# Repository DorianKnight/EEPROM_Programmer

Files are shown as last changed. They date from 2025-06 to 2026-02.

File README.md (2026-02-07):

# EEPROM_Programmer

## Project Overview
Custom Serializer Deserializer (SerDes) PCB designed to handle read/write operations to a parallel address EEPROM.
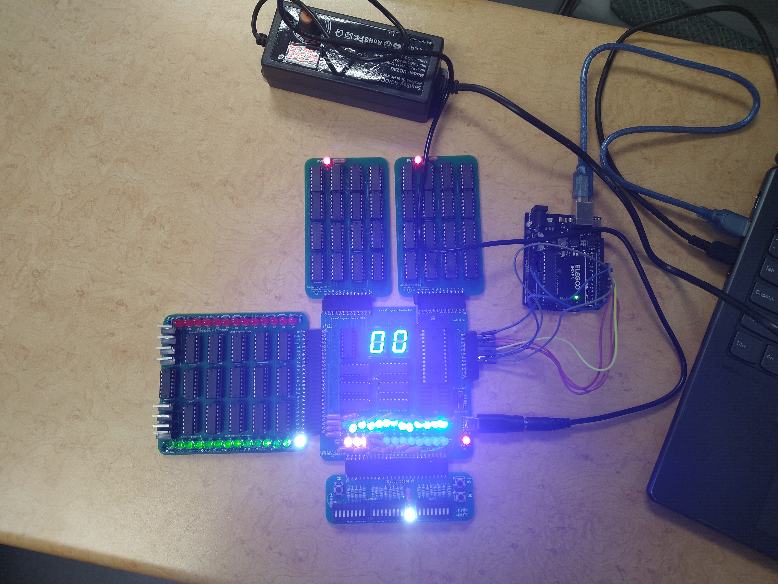
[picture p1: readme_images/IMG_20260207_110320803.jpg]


## High Level Architecture
Data from the host computer is transferred through serial communication to the Arduino. The Arduino writes the serial data into the SerDes which outputs the data in parallel to the EEPROM for storage.

To read information from the EEPROM, the Arduino loads the parallel data output into the SerDes and reconstructs the byte packet bit by bit. A high level functional block diagram explaining the system can be seen below.
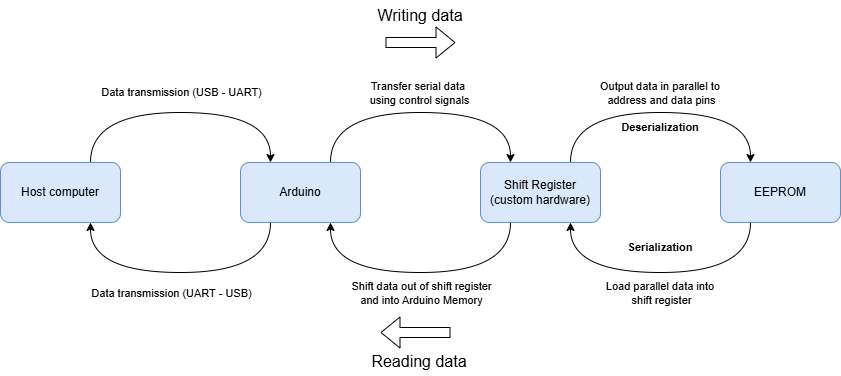
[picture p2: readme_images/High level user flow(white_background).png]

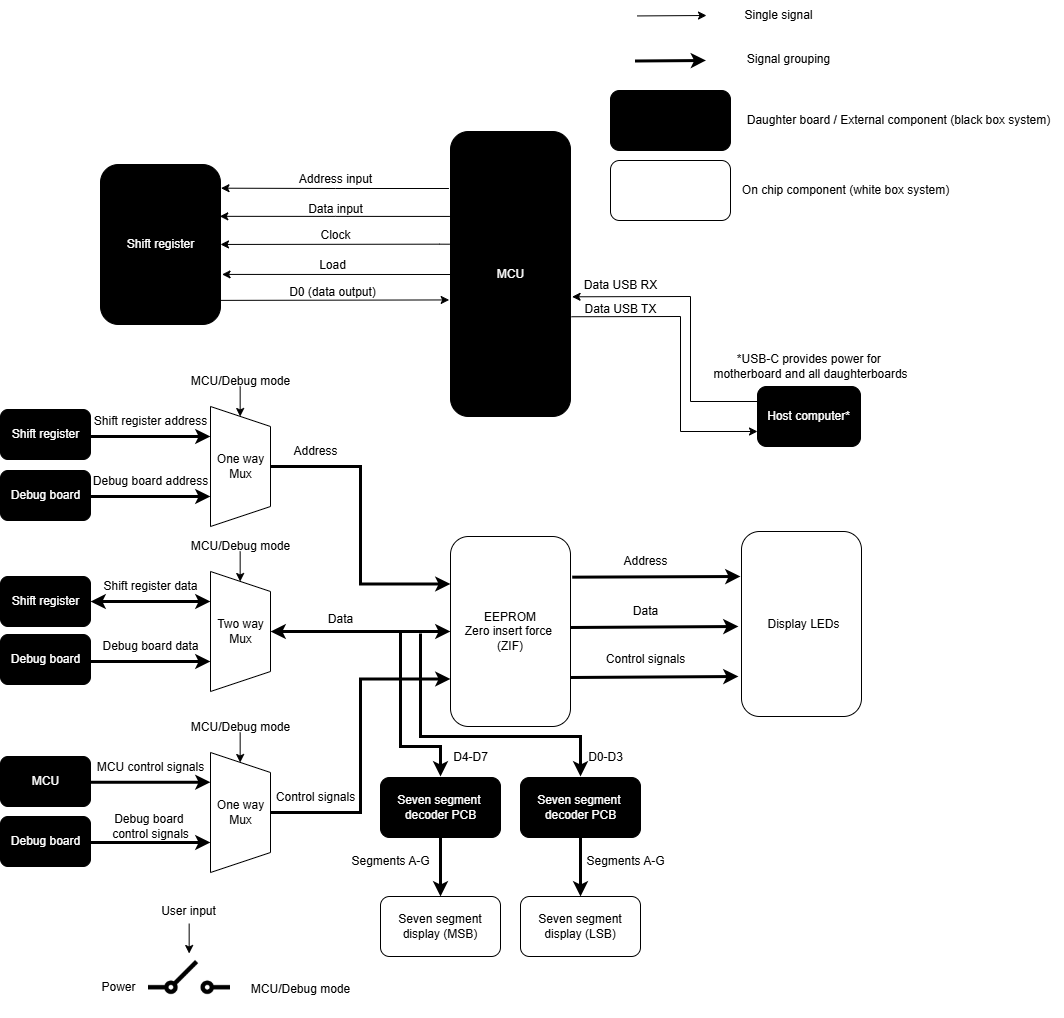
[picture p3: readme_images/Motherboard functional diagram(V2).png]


## SerDes
A custom shift register functions as a primitive SerDes. Going from serial to parallel, the custom hardware allows serial data to ripple into individual flip-flops where each flip-flop drives an individual output. These outputs then wire into the EEPROM’s address and data pins. The same hardware also functions to load in the parallel data output from the EEPROM and shift it out sequentially such that the Arduino can reconstruct the byte packet.
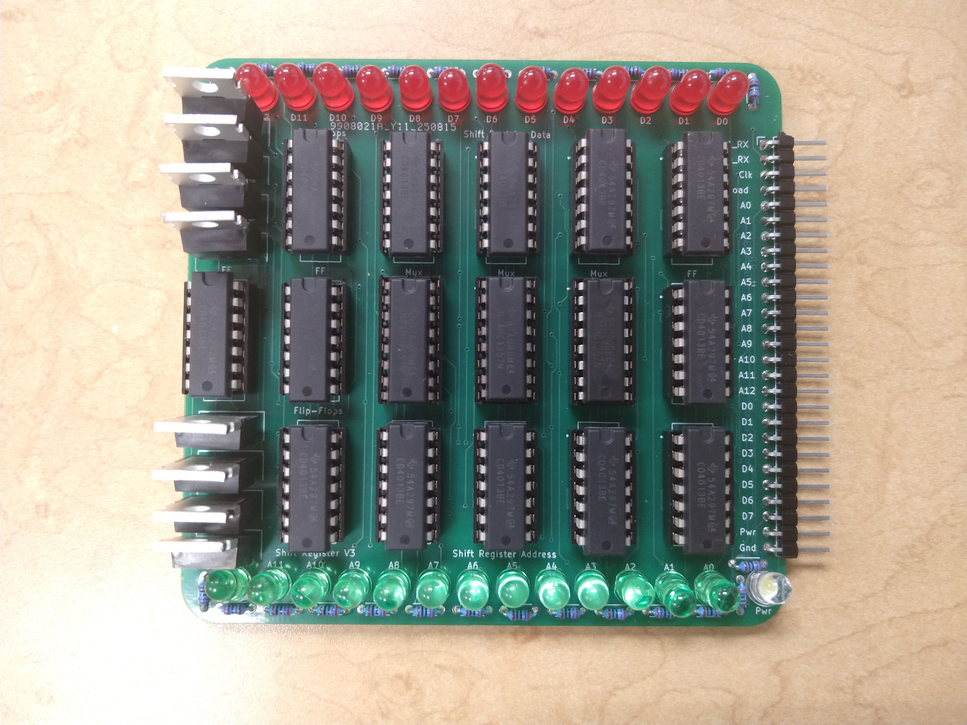
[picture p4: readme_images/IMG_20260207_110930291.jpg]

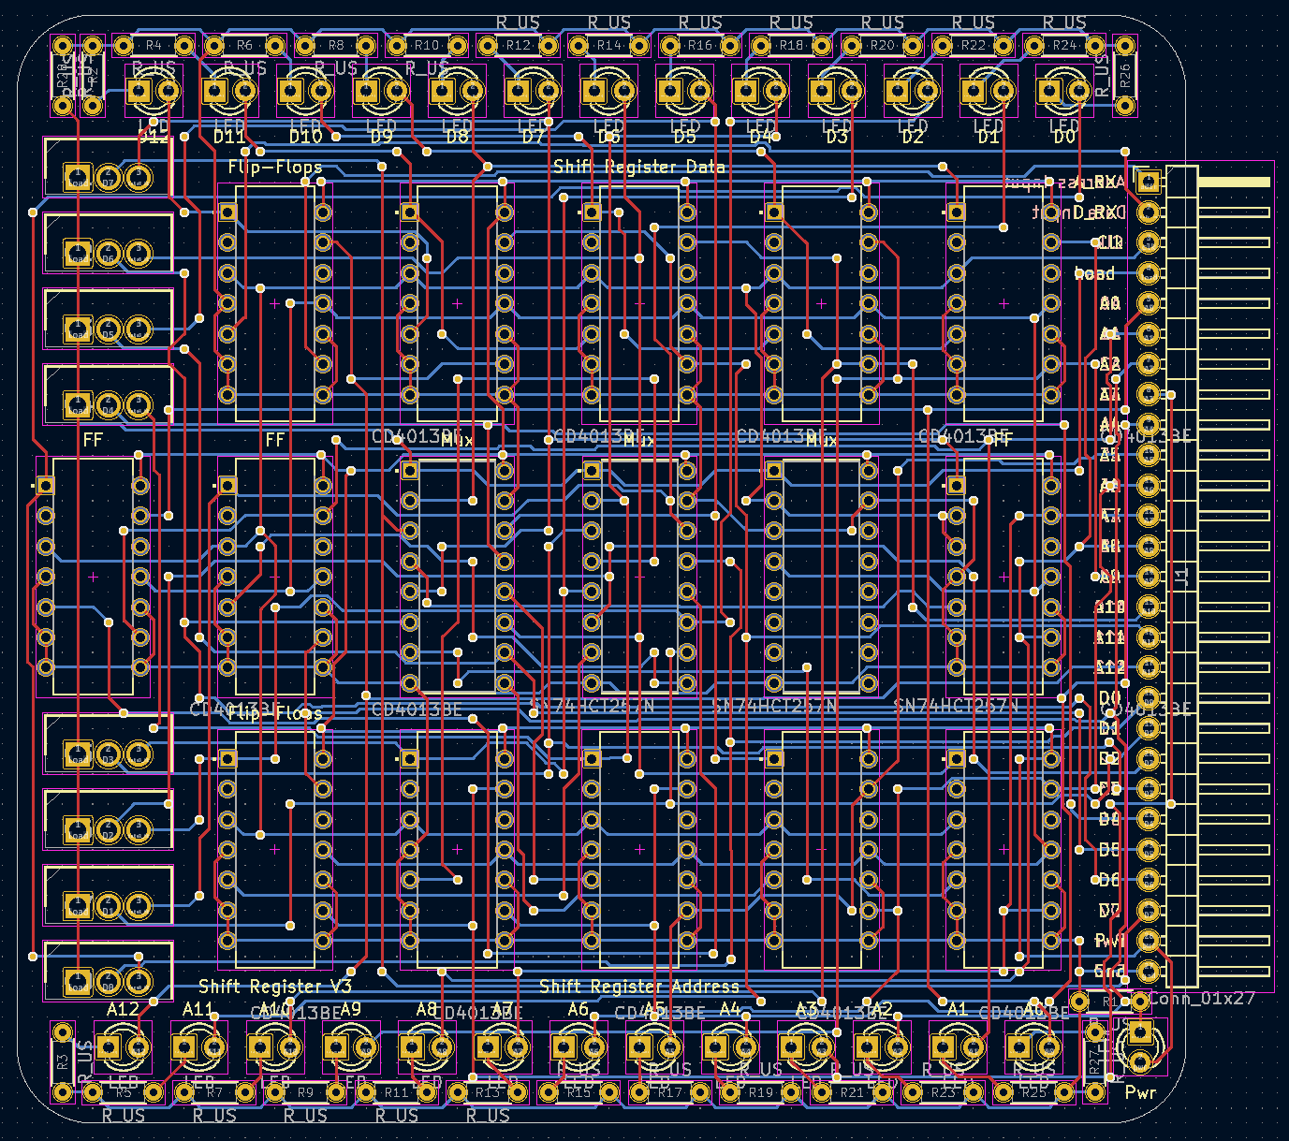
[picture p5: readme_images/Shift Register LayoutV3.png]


## Debugging
To facilitate debugging operations, a debug daughter board PCB was constructed that allows the technician to manually toggle all control signals made available to the Arduino MCU.
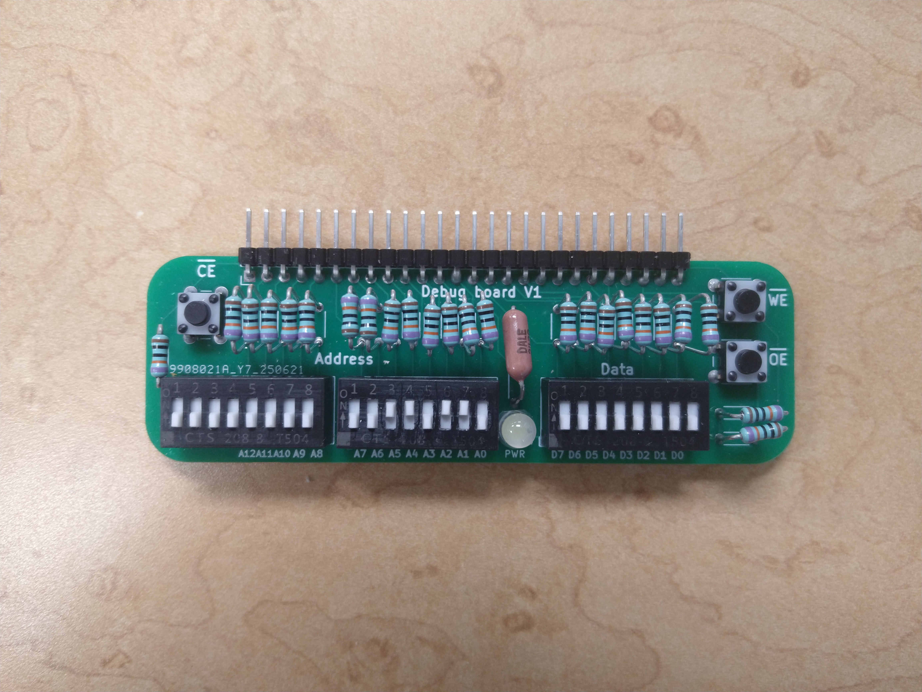
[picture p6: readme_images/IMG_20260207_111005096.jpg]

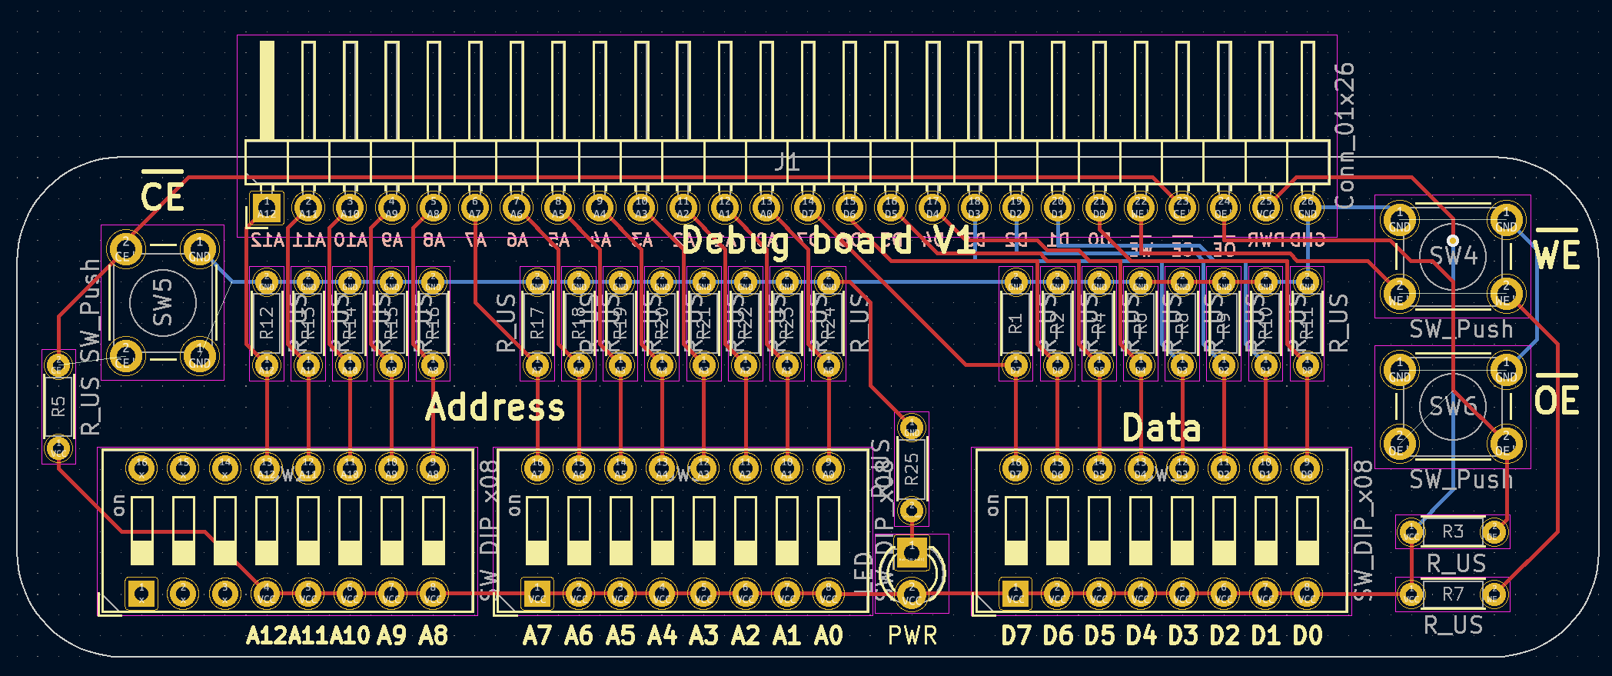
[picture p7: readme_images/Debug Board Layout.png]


## Motherboard Interface
The motherboard hosts a series of LEDs and seven-segment displays that serve to display the byte stored at a specific address. By changing the board to debug mode, the technician can select an address to read its binary and hexadecimal representation.
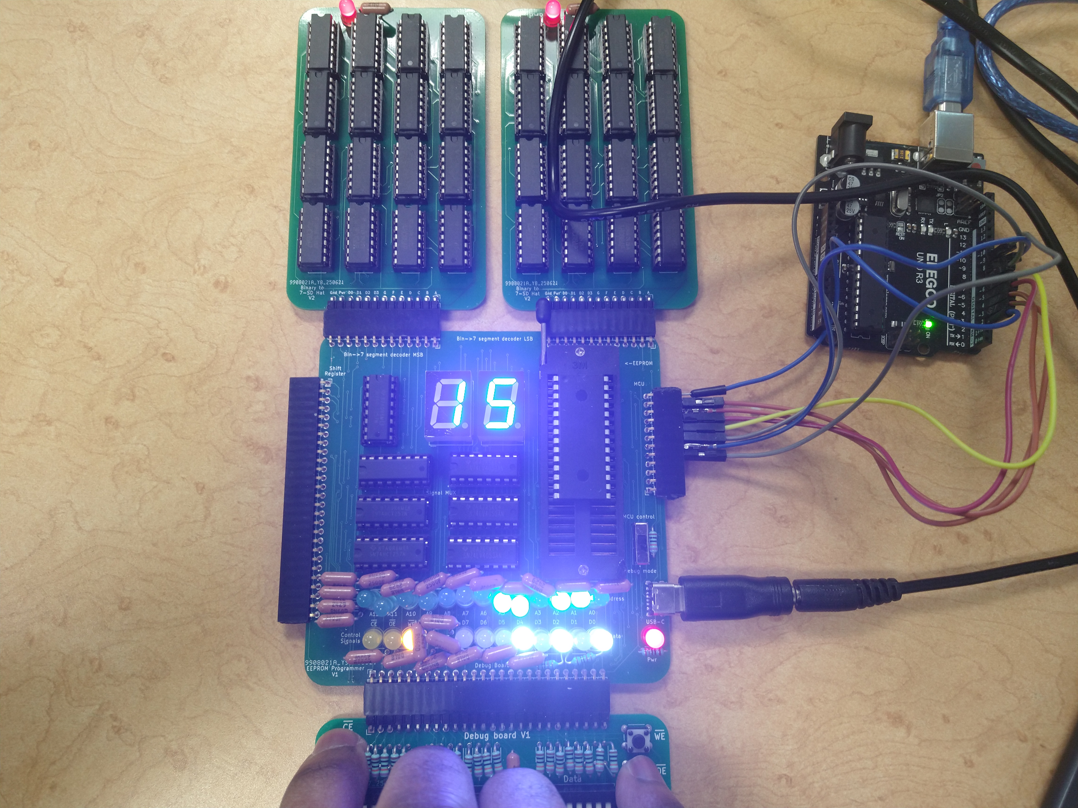
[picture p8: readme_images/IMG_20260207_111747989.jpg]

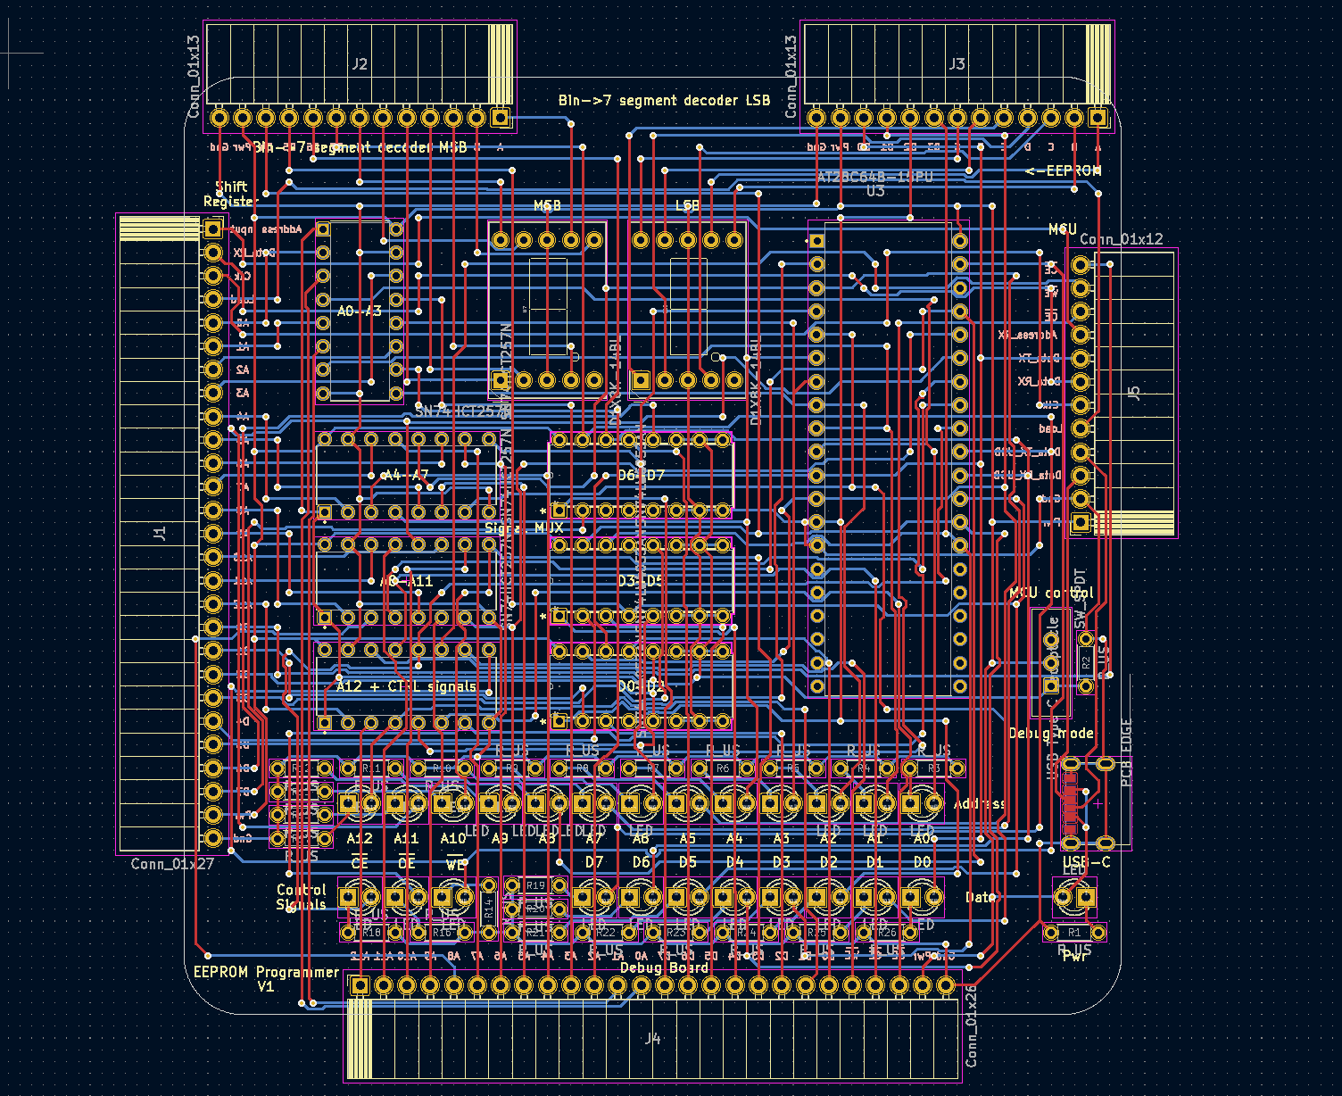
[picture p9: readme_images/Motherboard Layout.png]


## Custom Bin -> Hex 7-SD Driver 
Binary to hexadecimal conversion was accomplished through the design of custom digital combinational logic that uses a series of primitive logic gates to turn a four bit binary input into a seven pin output. The individual outputs turn on or off the individual segments on a seven segment display.
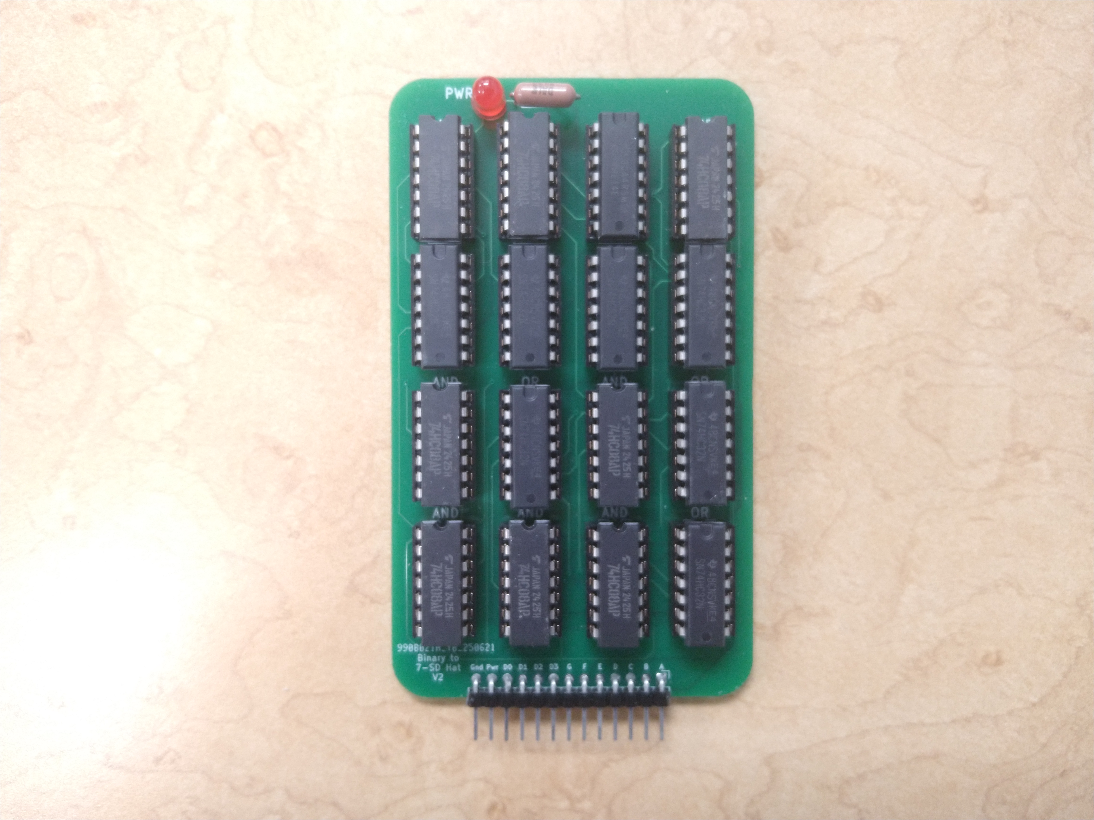
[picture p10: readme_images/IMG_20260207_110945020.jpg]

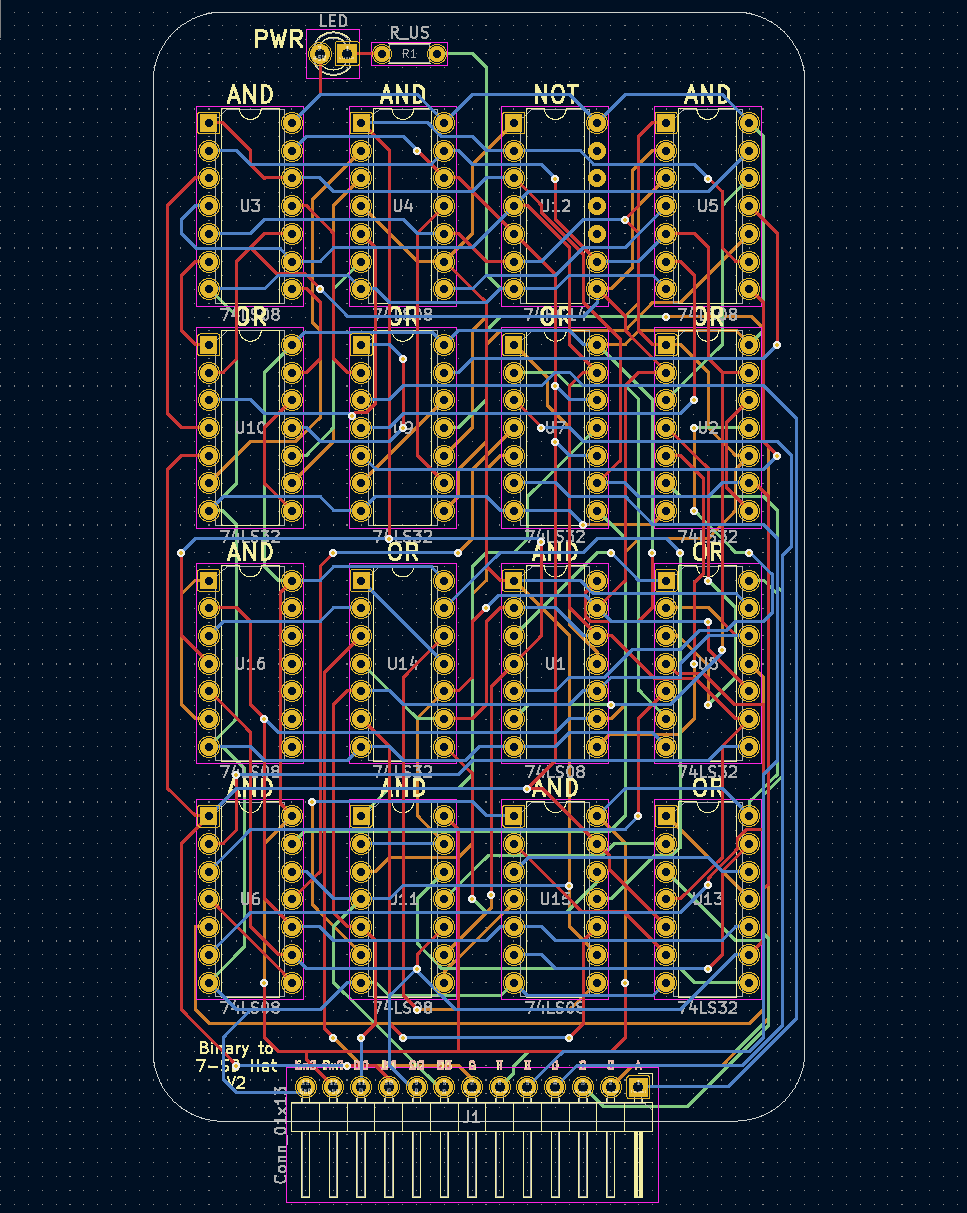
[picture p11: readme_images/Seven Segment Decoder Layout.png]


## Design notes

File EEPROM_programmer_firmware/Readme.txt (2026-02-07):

Arduino runs command_interpreter.ino which leverages EEPROM_Programmer_Utility.h and EEPROM_Programmer_Utility.cpp

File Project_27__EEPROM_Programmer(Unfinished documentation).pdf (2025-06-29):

# EEPROM Programmer

Dorian Knight

Created: June 27th 2025
Updated: June 29th 2025

## Contents

1 Project Overview | 2
2 Purpose | 2
3 Outcomes | 2
4 Skills Used | 3
5 Design Requirements | 3
6 High Level Design | 5
7 Design Implementation Details | 6
8 Bill of Materials Formation and Considerations | 23
1 | Internal project No.27

EEPROM Programmer

## 1 Project Overview

The EEPROM programmer is a custom-made hardware device with software support designed to interface a computer with the AT28C64B electrically erasable programmable read-only memory (EEPROM) [Link to data sheet] (https://ww1.microchip.com/downloads/en/DeviceDoc/doc0270.pdf) . For development and testing, custom firmware was made for the ATmega328p chip to drive the programmer. The EEPROM programmer also comes with bespoke software allowing the user to control the EEPROM programming from their computer.

## 2 Purpose

The purpose of this project was to venture far outside my comfort zone and tackle a problem I had no idea how to solve. I conceived this project idea while learning about the Pickit (https://www.microchip.com/en-us/development-tool/pg164130) series programmers after asking questions about how they worked and why I couldn’t program a PIC (https://en.wikipedia.org/wiki/PIC_microcontrollers) the same way I programmed an Arduino. (https://www.arduino.cc/)

Deciding to make a custom EEPROM programmer allowed me to gain the following skills:

- Gain printed circuit board (PCB) design experience
- Introduction to firmware and C language drivers
- Increase fluency in reading and understanding datasheets
- Using datasheet information to compose a bill of materials
- Use digital marketplace tools (digikey search) to select components that met requirement specifications but also didn’t break the bank
- Learn what it is like to manage a project – even if it was just a project with one developer who was also the manager

## 3 Outcomes

I worked through the hardware-software co-design process to create a custom EEPROM programmer PCB along with a custom software application to control the programming of a 64 KB EEPROM.

### 3.1 Hardware outcomes

- Created bidirectional serial to parallel interface allowing the Arduino’s serial data I/Os to interface with the EEPROM’s parallel addressing and data requirements
- Derived combinational digital logic through Karnaugh mapping to create a binary to seven-segment decoder
- Designed switching mechanism allowing the user to control the programmer through MCU firmware or user-driven debug board

### 3.2 Firmware outcomes

- Created custom C driver running on Arduino hardware to read from and write to an EEPROM using custom hardware bidirectional serial to parallel interface
- Supported error checking during EEPROM flashing transcription accuracy
- Communicates with custom software application over USB cable using UART
- Able to guarantee 99% accuracy when programming up to XX KHz

### 3.3 Software outcomes

- Used Angular framework with Electron to create a sleek graphical user interface (GUI) to interface with the MCU on the EEPROM Programmer

### 3.4 Project management outcomes

- Leveraged modular design to minimize development risks and parallelize development
- Strategically used Digikey component quantity price breaks to reduce component budget by 35%

## 4 Skills Used

(a) Digital logic | (b) Kicad logo | (c) Soldering | (d) Arduino icon
(e) Angular logo | (f) Electron logo | (g) GitHub icon

Figure 1: Skills used constructing EEPROM programmer

Digital logic was used to derive the combinational logic required to translate binary to seven-segment display control signals. Kicad was used to design and visualize the physical hardware of the EEPROM Programmer. Soldering was used to assemble all the components once I received the manufactured PCBs from JLCPCB. Arduino was used to drive the individual circuit components to accomplish the end goals of flashing data to the EEPROM. Arduino was also used to interface with the programmer software application such that the user could directly program the EEPROM from their computer. Angular was used to design the programming application and Electron was used to package that application making the software available for users on Windows, Linux and MacOS. GitHub was used to version control the Angular software application.

## 5 Design Requirements

To ensure project feasibility I drafted requirements during the project planning stage to set the initial project scope.

The requirements were as follows:

- R1: Must be controllable through microcontroller unit (MCU) or manual hardware debugger
- R2: Should use LED indicators to show the status of pins of interest (address, data, control signals)
- R3: All PCBs must have a power LED indicator that is illuminated when the board is powered.
- R4: Must minimize port interface size with MCU to increase the number of commercial MCUs that could be used to drive the EEPROM programmer hardware.
- R5: Must be programmable using software application on user’s computer.
- R6: Should perform error checking/correction during or after flashing information to the EEPROM.

Here is how the EEPROM programmer project adhers to the requirements above:

### 5.1 R1

To allow for MCU or direct user control, a switching mechanism was used to control multiplexing between the shift register and debug board signals. When the MCU control was selected, only the shift register and Arduino signals were let through to directly control the EEPROM. When debug mode was selected the multiplexers restricted the flow of information from the shift register and Arduino and allowed the signals from the debug board to pass through to the EEPROM.

### 5.2 R2

LEDs were used throughout the design on the shift register and the motherboard. The shift register LEDs indicate the status of each data flip-flop while the LEDs on the motherboard indicate the “post multiplexed” signal is on the address, data and control signal lines. Additional seven-segment display hardware was designed to humanize the data readout.

### 5.3 R3

An LED indicator was placed on all PCB boards to indicate whether or not the board was powered.

### 5.4 R4

Through the implementation of a bidirectional shift register, I was able to reduce the pin count from 28 pins to 12 pins greatly expanding the types of MCUs that could be used with my EEPROM programmer hardware.

Without serial to parallel converter the MCU needs 28 pins (2 power + 26 GPIO) to drive the following signals:

- 8 data
- 13 address
- 3 control
- 1 power
- 1 ground
- 1 USB TX
- 1 USB RX

With the serial to parallel converter the MCU only needs 12 pins (2 power + 10 GPIO) to drive the following signals:

- 1 data in (from the shift register for error correction)
- 1 data out (from Arduino to shift register)
- 1 address out (from Arduino to shift register)
- 3 control signals
- 1 load signal (used to reverse the serial-¿parallel interface into a parallel-¿serial interface)
- 1 clock signal (used to sequentially advance the data through the shift register
- 1 Power
- 1 Ground
- 1 USB TX
- 1 USB RX

### 5.5 R5

Angular application packaged for desktop using electron is used to interface the user’s computer with the onboard MCU.

### 5.6 R6

Every time a byte is written from the shift register into the EEPROM it is read back into the shift register then shifted out 1 bit at a time into the Arduino to be checked against the original byte that was sent out. If the received byte does not match the sent byte, the address is rewritten and checked again. This ensures that each address has the intended value.

By following these requirements, I was able to keep scope creep to a minimum and deliver a product that holds true to the initial inception of the project’s goals.

## 6 High Level Design

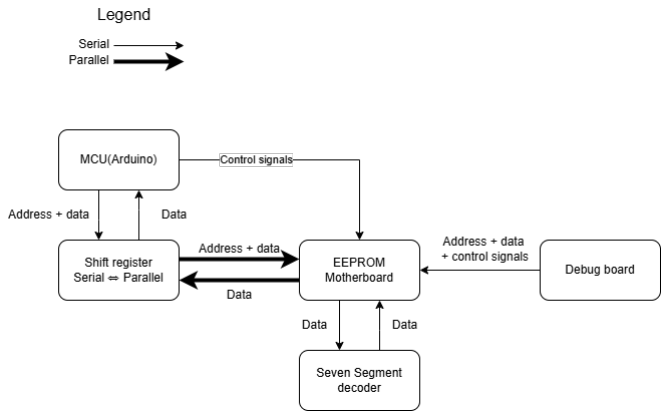
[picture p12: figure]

Figure 2: EEPROM programmer hardware high level block diagram

### 6.1 Serial to Parallel Conversion

Based on the system requirements the MCU interface is serial while the EEPROM interface is parallel. To rectify this difference, a custom bidirectional shift register is used such that the Arduino can pipe in the data one bit at a time and when sufficient data has been written, the Arduino can signal the EEPROM to read or write that specific address.

### 6.2 Bidirectional Read and Write

While data can be piped in one at a time into the shift register, data can also be loaded in parallel from the EEPROM into the shift register then shifted out to the Arduino controller one bit at a time. This is done to support error correction as the Arduino can compare what it intended to write vs what actually got written.

### 6.3 Manual User Debug

A custom debug board was designed to interface with the EEPROM Motherboard. When put into debug mode, the debug board dip switches and push buttons can be used to directly program the EEPROM.

### 6.4 Signal Multiplexing in EEPROM Motherboard

Both the shift register and debug board signals feed into multiplexer inputs and depending on the state of the MCU/debug switch either the shift register signals or debug board signals are let through to the EEPROM pins.

### 6.5 Seven Segment Decoder

A custom PCB was made to convert a 4-bit binary number into the seven signals required to drive a seven-segment display. This was done to prove my digital logic design capabilities. The PCB takes the 4 bits as an input and uses combinational logic derived through Karnaugh mapping to output the seven signals required to drive a seven-segment display. Two 7SD PCBs are used where each PCB drives one seven-segment display. One display represents the lower 4 bits in an address and the other represents the higher 4 bits. Together they represent every bit from 0x00 to 0xFF (0-255).

## 7 Design Implementation Details

### 7.1 Shift Register Design

The shift register design was created to resolve the serial to parallel disconnect between the MCU and EEPROM. R4 (from section 5.4) mandates that the required MCU GPIOs be kept to a minimum in order to maximize the list of compatible MCUs that could be used to drive the EEPROM programmer hardware. To reduce the number of required GPIOs, address and data bits are sent out one bit at a time serially instead of sending all bits at once in parallel. This reduces the number of address and data GPIO pins down from 21 (8 data + 13 address) to 2 (1 data + 1 address).

While the MCU interface was changed to support serial data flow, the EEPROM still required its data and address bits to be delivered in parallel. Looking at section 15 in the EEPROM datasheet we can see that the write waveform requires all 13 address bits and 8 data bits when the chip enable and write enable goes low.

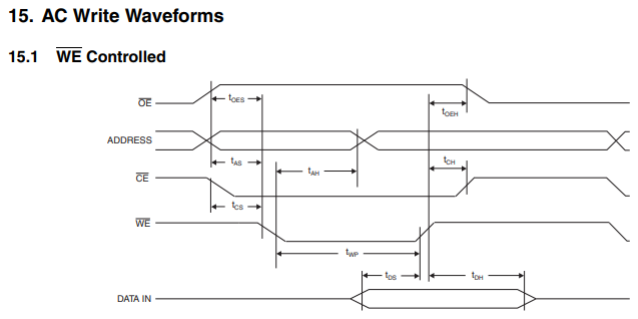
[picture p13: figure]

Figure 3: EEPROM writen enable controlled write waveform

Looking at the physical pin layout in figure 4 we can see that the 13 address bits and 8 data bits are all connected to separate legs of the IC requiring the driver to control the state of each chip leg at the time of writing.

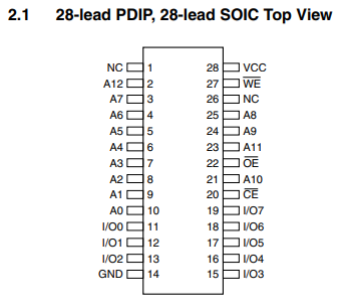
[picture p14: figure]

Figure 4: EEPROM IC pin layout

We only have two available pins (address and data) so the MCU can’t control the state of each individual leg at once. The solution to this disconnect was a serial to parallel shift register where the MCU could push in the address and data one bit at a time and the shift register would output all 13 address and 8 data bits at once when the entire bit stream had been output by the MCU. This will allow the two MCU GPIOs to control the 21 address and data legs of the EEPROM.

Unfortunately, the solution gets more complicated. R6 (from section 5.6) mandates that the MCU perform error checking processes either during or after programming to ensure transcription accuracy. To do this, the shift register must be bidirectional and allow the parallel address and data bits to be serially shifted out of the shift register back to the MCU for verification.

To support both R4 (from section 5.4) and R6 (from section 5.6), a custom bidirectional shift register PCB was developed. This bidirectional shift register supported MCU serial data and address inputs while also supporting parallel loading from the EEPROM data lines into the individual flip-flops when a “load” control signal is provided from the MCU. After loading, the data, now in the individual flip-flops that make up the shift register could be shifted out to the MCU one bit at a time.

The entire shift register design can be represented using the following functional block diagram in figure 5:

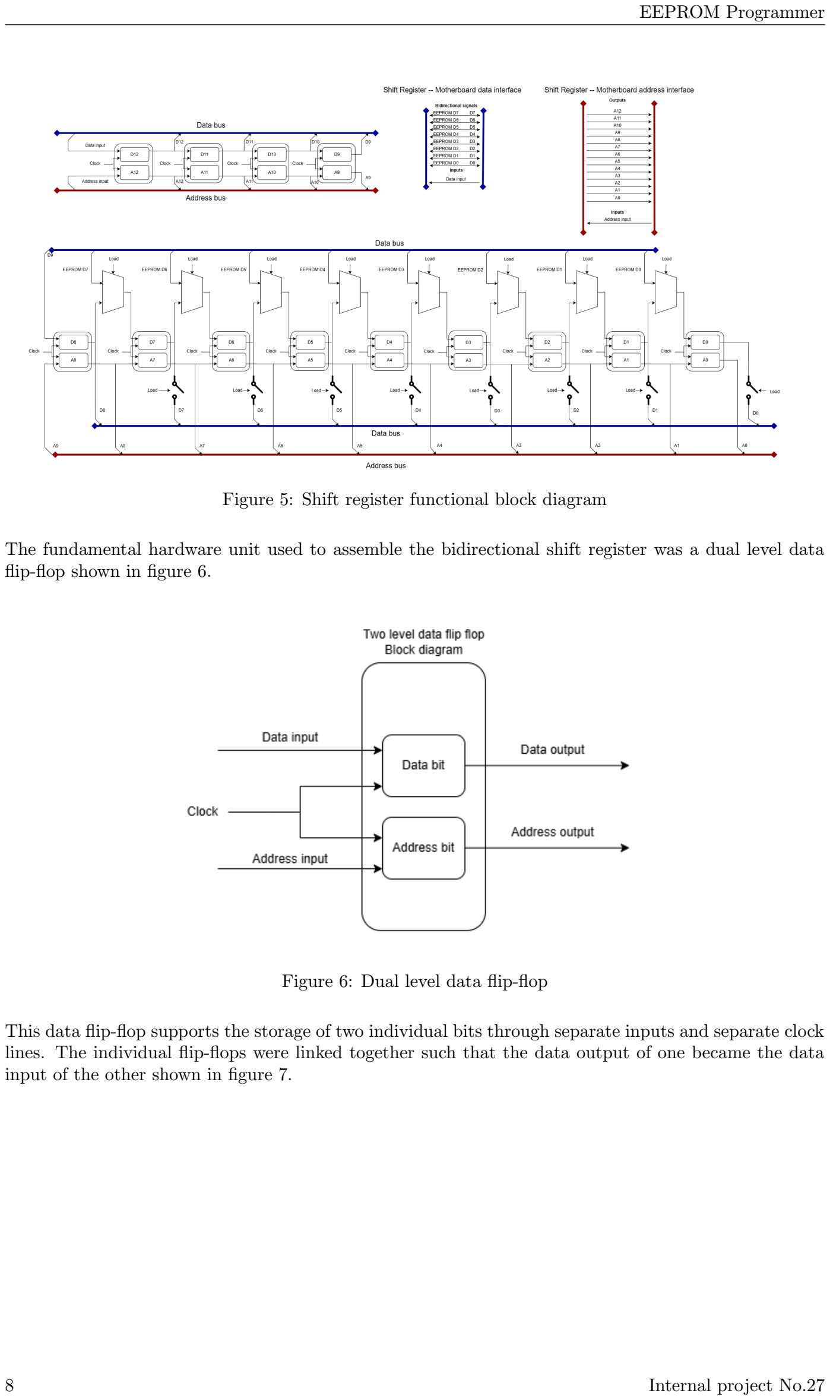
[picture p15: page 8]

Figure 5: Shift register functional block diagram

The fundamental hardware unit used to assemble the bidirectional shift register was a dual level data flip-flop shown in figure 6.

Figure 6: Dual level data flip-flop

This data flip-flop supports the storage of two individual bits through separate inputs and separate clock lines. The individual flip-flops were linked together such that the data output of one became the data input of the other shown in figure 7.

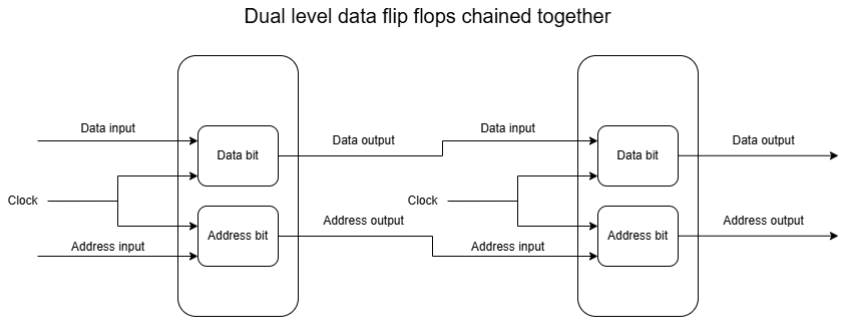
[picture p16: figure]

Figure 7: Two dual level data flip-flops linked together

All flip-flops share the same clock line to advance both the data and address bits at the same time, reducing the number of required clock lines from 2 to 1.

Thirteen dual level flip-flops were used to design the bidirectional shift register. This allowed each address bit to be represented in a flip-flop. However, since there were thirteen address bits, there were also thirteen data bits, of which only bits 0-7 were used by the EEPROM therefore only data bits 0-7 were connected through to the motherboard and into the EEPROM.

To support parallel loading, the data input lines were fed from a multiplexer shown in figure 8 which took the previous flip-flop’s data and the EEPROM’s data as inputs. The multiplexer was controlled by a “load” signal provided by the MCU requiring an additional GPIO pin.

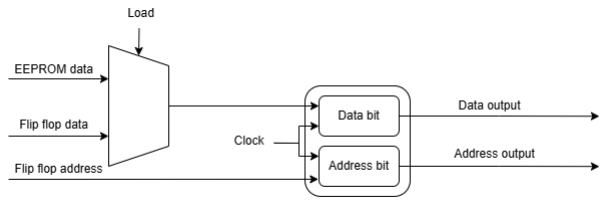
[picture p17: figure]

Figure 8: Flip-flop data input multiplexed to accept EEPROM data or shift register data

Because the data pins on the EEPROM are bidirectional, the data output from the flip-flops and the EEPROM data fed into the multiplexer actually come from the same PCB trace. To ensure the flip-flop data output doesn’t pollute the signal trace when trying to load data from the EEPROM, a switch was used to turn off the flip-flop output as seen in figure 9.

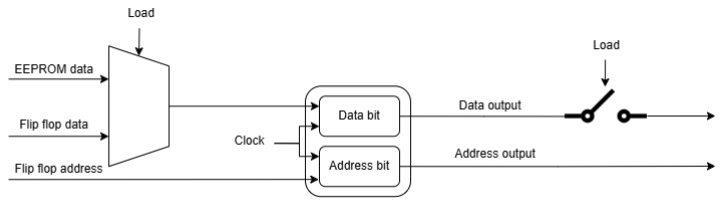
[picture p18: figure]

Figure 9: Flip-flop output controlled through load signal

The switch is controlled by the same load signal to reduce the required MCU GPIOs. When the load signal is active, the switch opens and the multiplexer switches to forward the EEPROM data. On the next clock signal, the EEPROM data bit will be stored in the shift register such that it can eventually be shifted out and read by the MCU.

Data bits 0-7 are the only outputs that need to be switched as data bits 8-12 are kept internally on the shift register board and are not piped forward to the motherboard.

### 7.2 Debug Board Design

The debug board was designed to satisfy R1 (from section 5.1). The manual hardware debugger is a combination of dip switches and buttons the user can use to physically control all the necessary signals to program individual addresses on the EEPROM. The main use of this board is for debugging purposes; to test if the correct byte is written on a specific address and if not, being able to rewrite that address with a new byte.

The debug board design can be represented using this functional block diagram in figure 10:

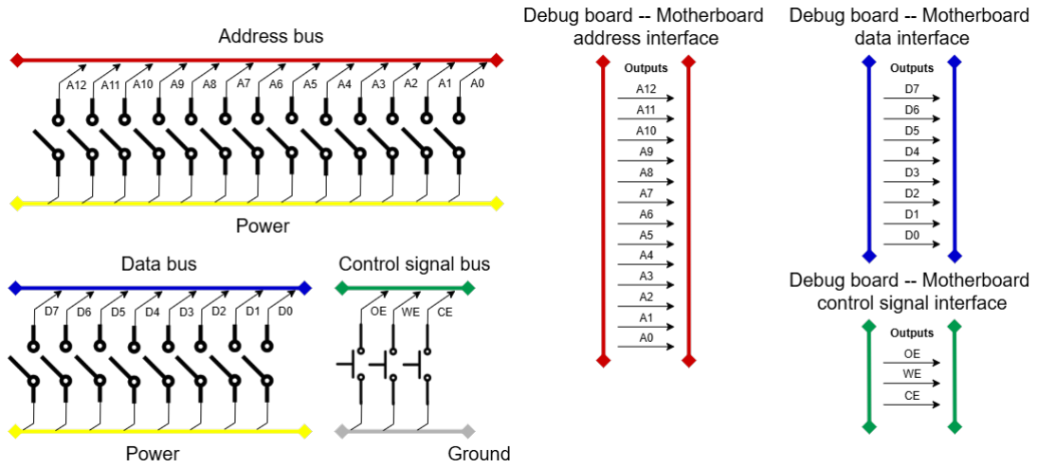
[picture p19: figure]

Figure 10: Debug board functioanl block diagram

Because the control signals are active low, the buttons are pulled high to Vcc and then the push button pulls the respective control signal back to ground when pressed. The remainder of the address and data signals are all pulled low to ground and the dip switches pull the signal line high to Vcc.

These signals are all piped through to the motherboard so that they can be multiplexed with the shift register signals, the output of which is piped through directly to the EEPROM.

### 7.3 Seven Segment Decoder Design

The seven-segment decoder was designed to satisfy R2 (from section 5.2). While the motherboard does have indicator LEDs showing the status of all address, data, and control signal lines, I’m more comfortable decoding hexadecimal than raw binary especially when the numbers get sufficiently large. To support a hexadecimal read out of the binary data at a specified address, I synthesized digital logic through Karnaugh mapping to take in a 4-bit binary number and output the required control signals to illuminate the hexadecimal representation of said number on a seven-segment display.

There are many valid ways to solve this problem. One would be to program an EEPROM where each address corresponded to a binary number and the data at that address mapped to the on/off status of each segment in a seven-segment display. It also was entirely possible to reuse one of my seven-segment decoder ICs from my time in undergrad but I decided to create my own combinational logic to showcase my digital logic synthesis skills.

The seven-segment decoder PCB can be represented using the following functional block diagram in figure 11.

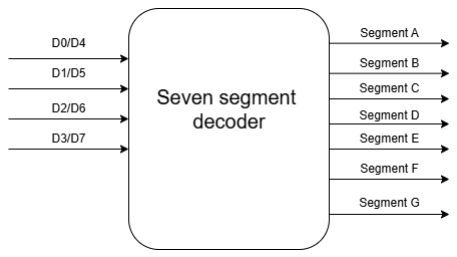
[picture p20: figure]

Figure 11: Seven segment decoder functional block diagram

There are two seven-segment decoder PCBs, one for bits D0-D3 and bits D4-D7. The corresponding segment outputs are piped to the two seven-segment displays housed on the motherboard. The two seven-segment displays represent the lowest four significant bits for D0-D3 and the four highest significant bits for D4-D7.

### 7.3.1 Combinational logic derivation overview

To derive the combinational logic, I had to create seven separate circuits which all took the four bits as input and outputted a zero or one for whether its respective segment should be turned off or on respectively.

Table 1 shows the Boolean state of each segment for every possible input from the motherboard.

Decimal representation | Input(binary) | Output (segments A-G) | 7SD output
0 1 2 3 4 5 6 7 8 9 10 11 12 13 14 15 | 0000 0001 0010 0011 0100 0101 0110 0111 1000 1001 1010 1011 1100 1101 1110 1111 | 1111110 0110000 1101101 1111001 0110011 1011011 1011111 1110000 1111111 1110011 1111101 0011111 1001110 0111101 1001111 1000111 | 0 1 2 3 4 5 6 7 8 9 a b C d E F

Table 1: 7SD combinational logic overview

### 7.3.2 A-segment combinational logic

Table 2 is a subset of table 1 displaying the individual Boolean state of the A-segment based on the binary input from the motherboard.

Decimal representation | Input (D3D2D1D0) | A segment output
0 1 2 3 4 5 6 7 8 9 10 11 12 13 14 15 | 0000 0001 0010 0011 0100 0101 0110 0111 1000 1001 1010 1011 1100 1101 1110 1111 | 1 0 1 1 0 1 1 1 1 1 1 0 1 0 1 1

Table 2: A-segment Boolean state based on 4-bit input

Writing table 2 in a 4x4 Karnaugh map using gray code produces the following combinational logic shown in figure 12.

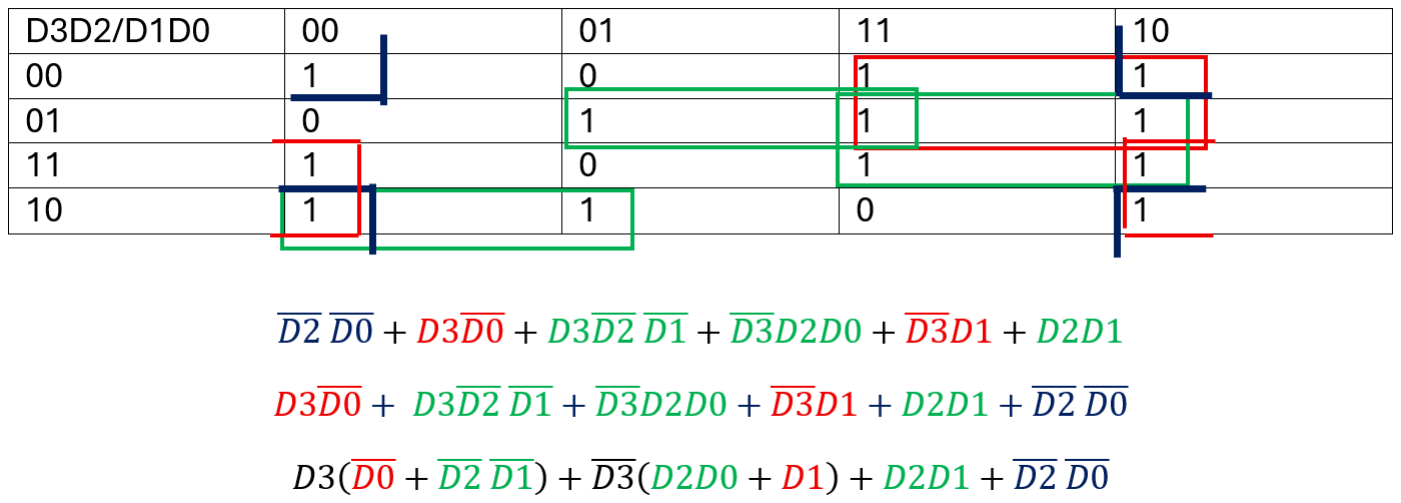
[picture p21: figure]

Figure 12: A-segment Karnaugh map + digital logic simplification

Implementing the logic above using logic gates yields the following circuit shown in figure 13.

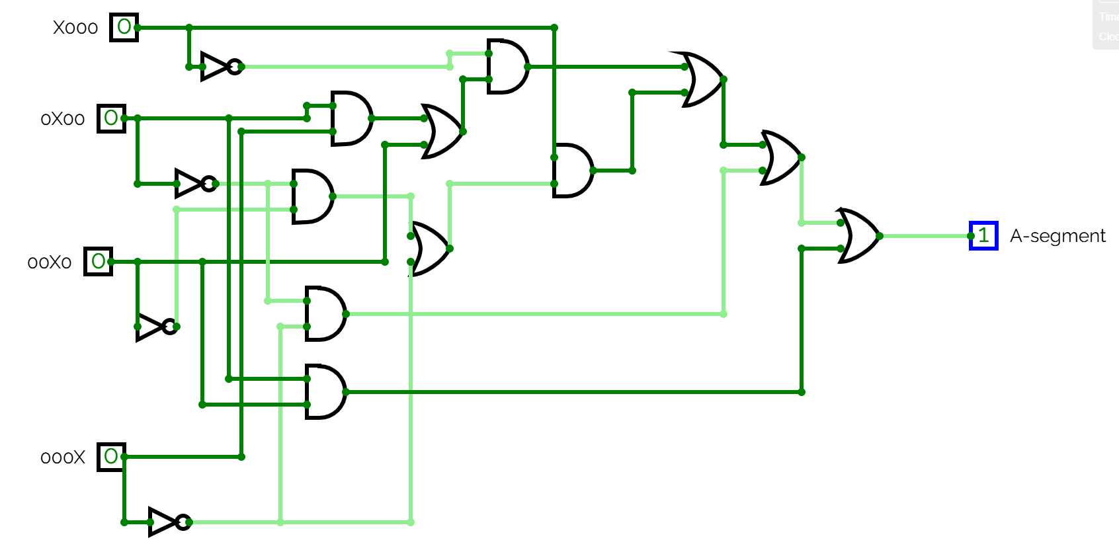
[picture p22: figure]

Figure 13: A-segment combinational logic

### 7.3.3 B-segment combinational logic

Table 3 is a subset of table 1 displaying the individual Boolean state of the B-segment based on the binary input from the motherboard.

Decimal representation | Input (D3D2D1D0) | B segment output
0 1 2 3 4 5 6 7 8 9 10 11 12 13 14 15 | 0000 0001 0010 0011 0100 0101 0110 0111 1000 1001 1010 1011 1100 1101 1110 1111 | 1 1 1 1 1 0 0 1 1 1 1 0 0 1 0 0

Table 3: B-segment Boolean state based on 4-bit input

Writing table 3 in a 4x4 Karnaugh map using gray code produces the following combinational logic shown in figure 14.

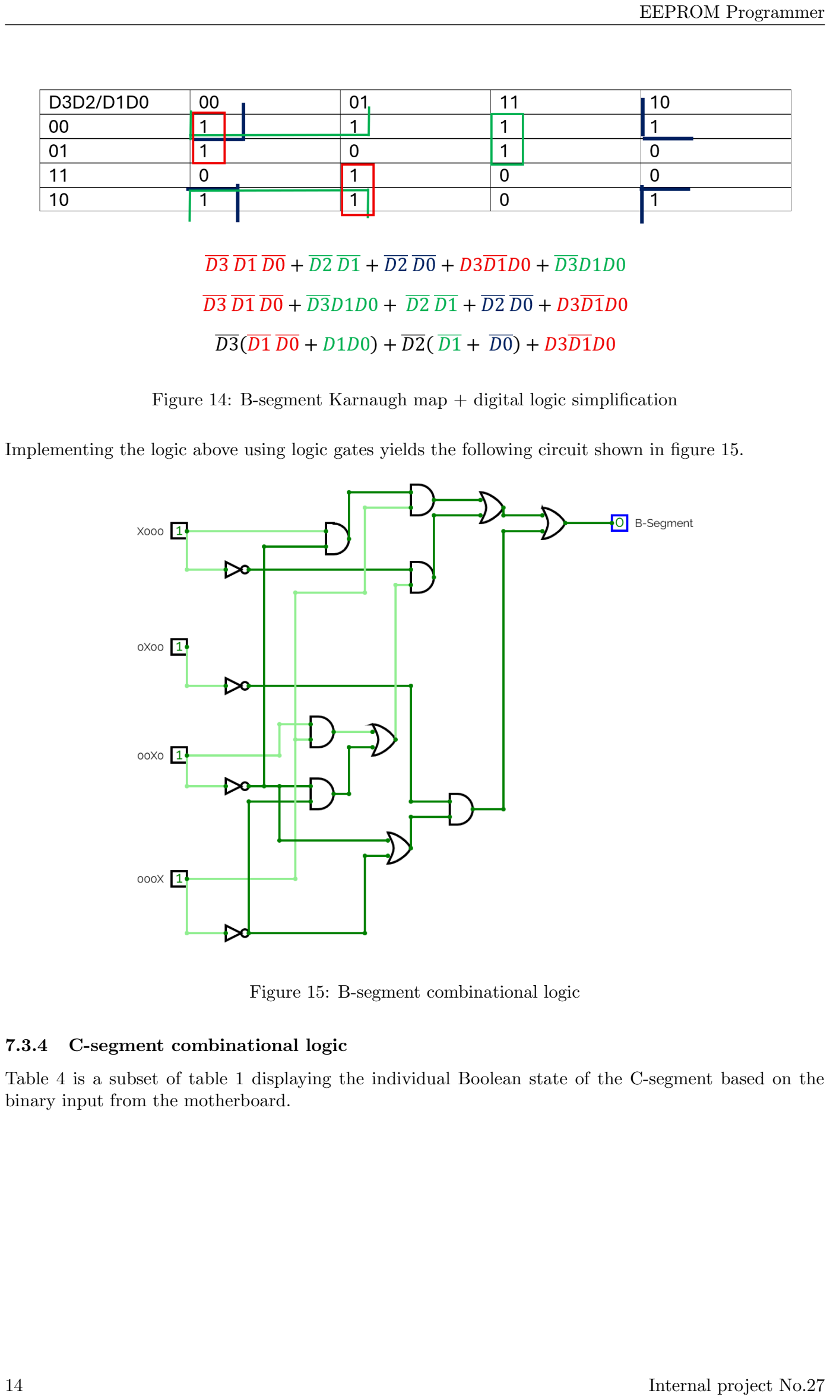
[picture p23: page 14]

Figure 14: B-segment Karnaugh map + digital logic simplification

Implementing the logic above using logic gates yields the following circuit shown in figure 15.

Figure 15: B-segment combinational logic

### 7.3.4 C-segment combinational logic

Table 4 is a subset of table 1 displaying the individual Boolean state of the C-segment based on the binary input from the motherboard.

Decimal representation | Input (D3D2D1D0) | C segment output
0 1 2 3 4 5 6 7 8 9 10 11 12 13 14 15 | 0000 0001 0010 0011 0100 0101 0110 0111 1000 1001 1010 1011 1100 1101 1110 1111 | 1 1 0 1 1 1 1 1 1 1 1 1 0 1 0 0

Table 4: C-segment Boolean state based on 4-bit input

Writing table 4 in a 4x4 Karnaugh map using gray code produces the following combinational logic shown in figure 16.

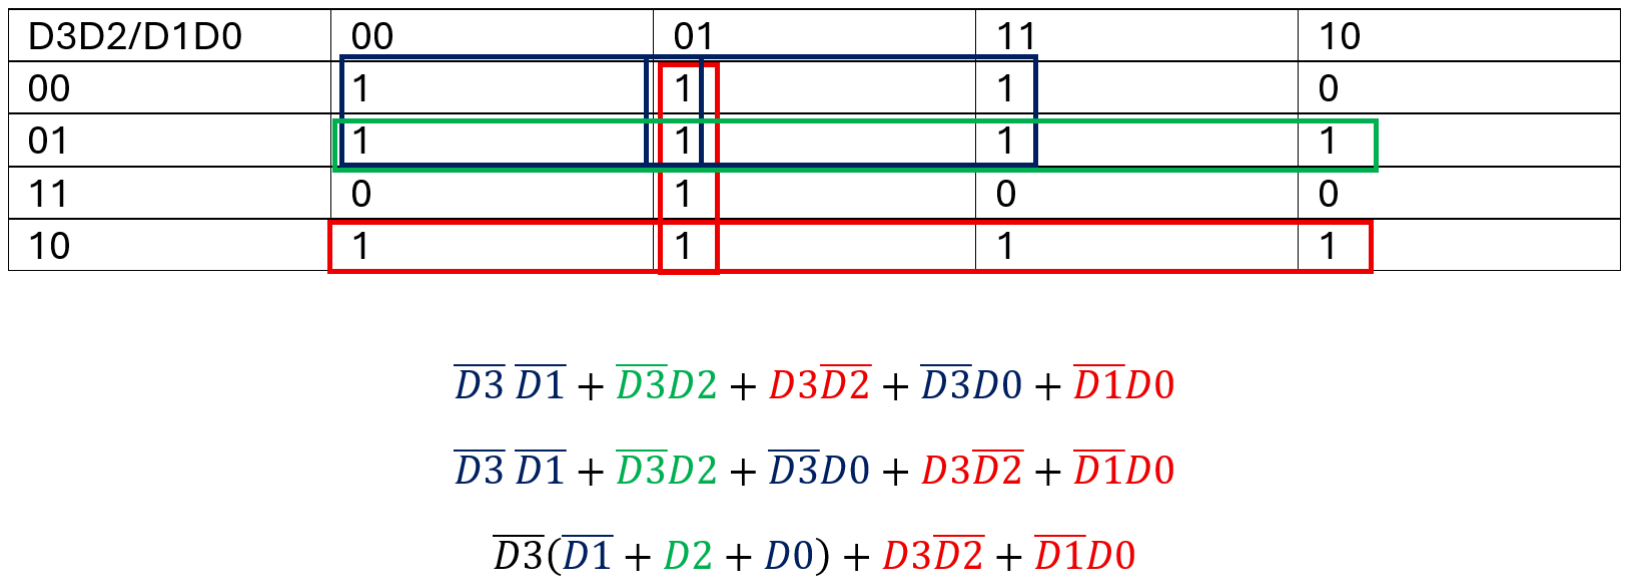
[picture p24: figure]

Figure 16: C-segment Karnaugh map + digital logic simplification

Implementing the logic above using logic gates yields the following circuit shown in figure 17.

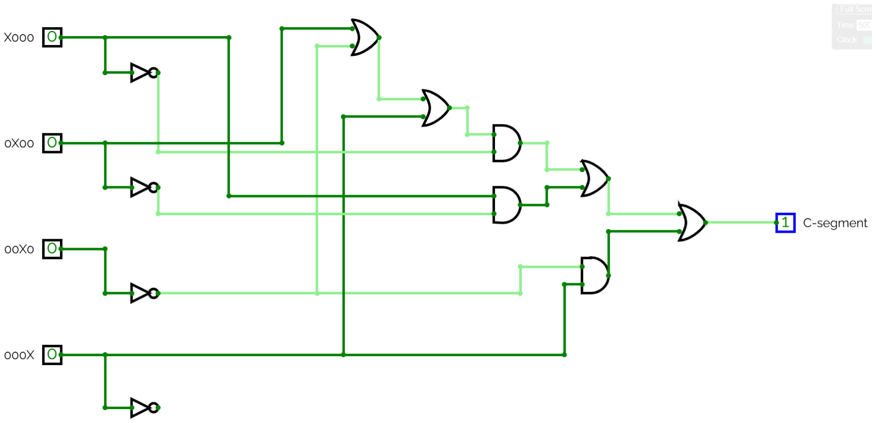
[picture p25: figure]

Figure 17: C-segment combinational logic

### 7.3.5 D-segment combinational logic

Table 5 is a subset of table 1 displaying the individual Boolean state of the D-segment based on the binary input from the motherboard.

Decimal representation | Input (D3D2D1D0) | D segment output
0 1 2 3 4 5 6 7 8 9 10 11 12 13 14 15 | 0000 0001 0010 0011 0100 0101 0110 0111 1000 1001 1010 1011 1100 1101 1110 1111 | 1 0 1 1 0 1 1 0 1 0 1 1 1 1 1 0

Table 5: D-segment Boolean state based on 4-bit input

Writing table 5 in a 4x4 Karnaugh map using gray code produces the following combinational logic shown in figure 18.

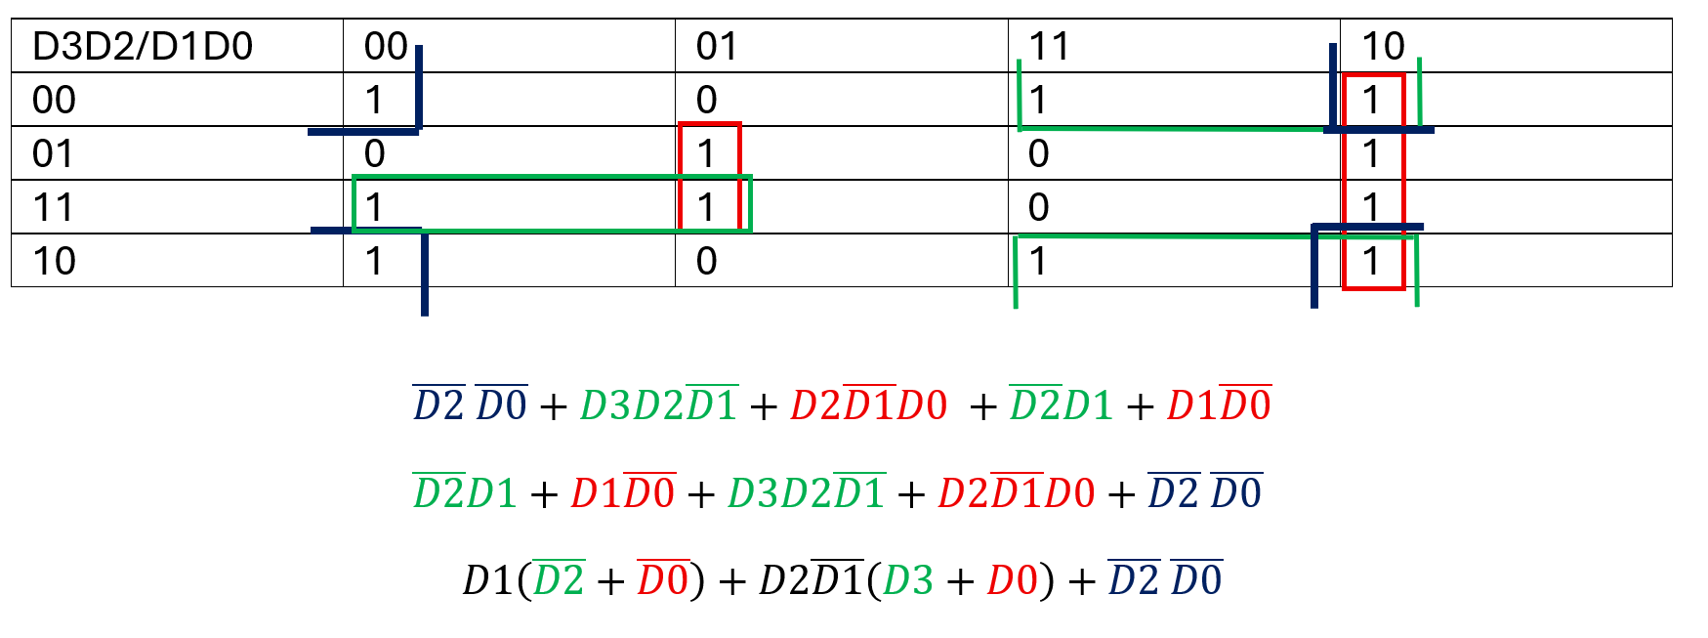
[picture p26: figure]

Figure 18: D-segment Karnaugh map + digital logic simplification

Implementing the logic above using logic gates yields the following circuit shown in figure 19.

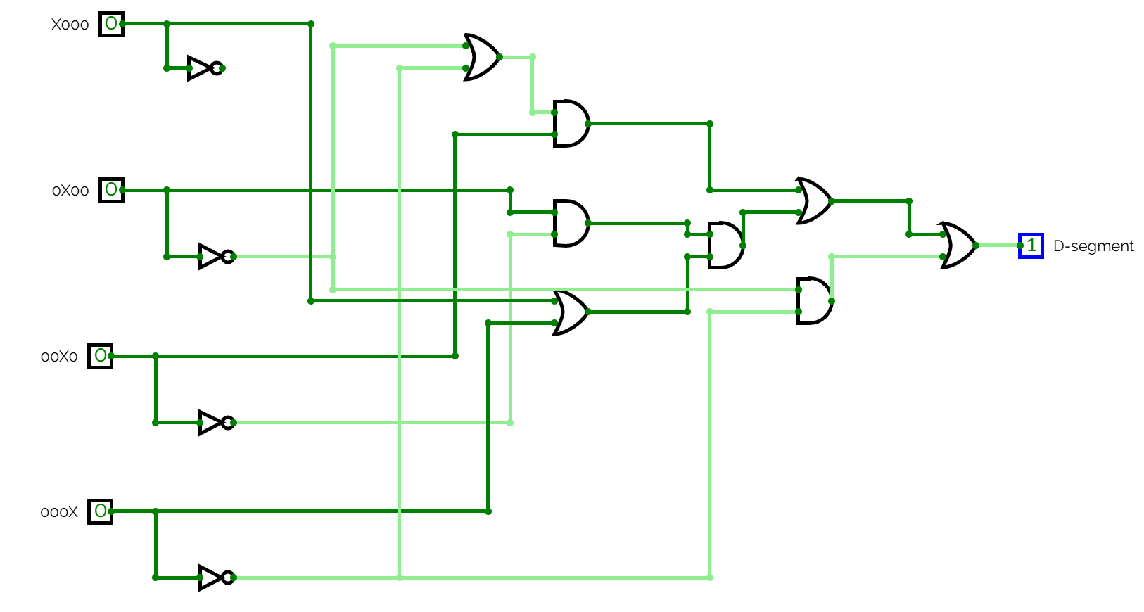
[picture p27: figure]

Figure 19: D-segment combinational logic

### 7.3.6 E-segment combinational logic

Table 6 is a subset of table 1 displaying the individual Boolean state of the E-segment based on the binary input from the motherboard.

Decimal representation | Input (D3D2D1D0) | E segment output
0 1 2 3 4 5 6 7 8 9 10 11 12 13 14 15 | 0000 0001 0010 0011 0100 0101 0110 0111 1000 1001 1010 1011 1100 1101 1110 1111 | 1 0 1 0 0 0 1 0 1 0 1 1 1 1 1 1

Table 6: E-segment Boolean state based on 4-bit input

Writing table 6 in a 4x4 Karnaugh map using gray code produces the following combinational logic shown in figure 20.

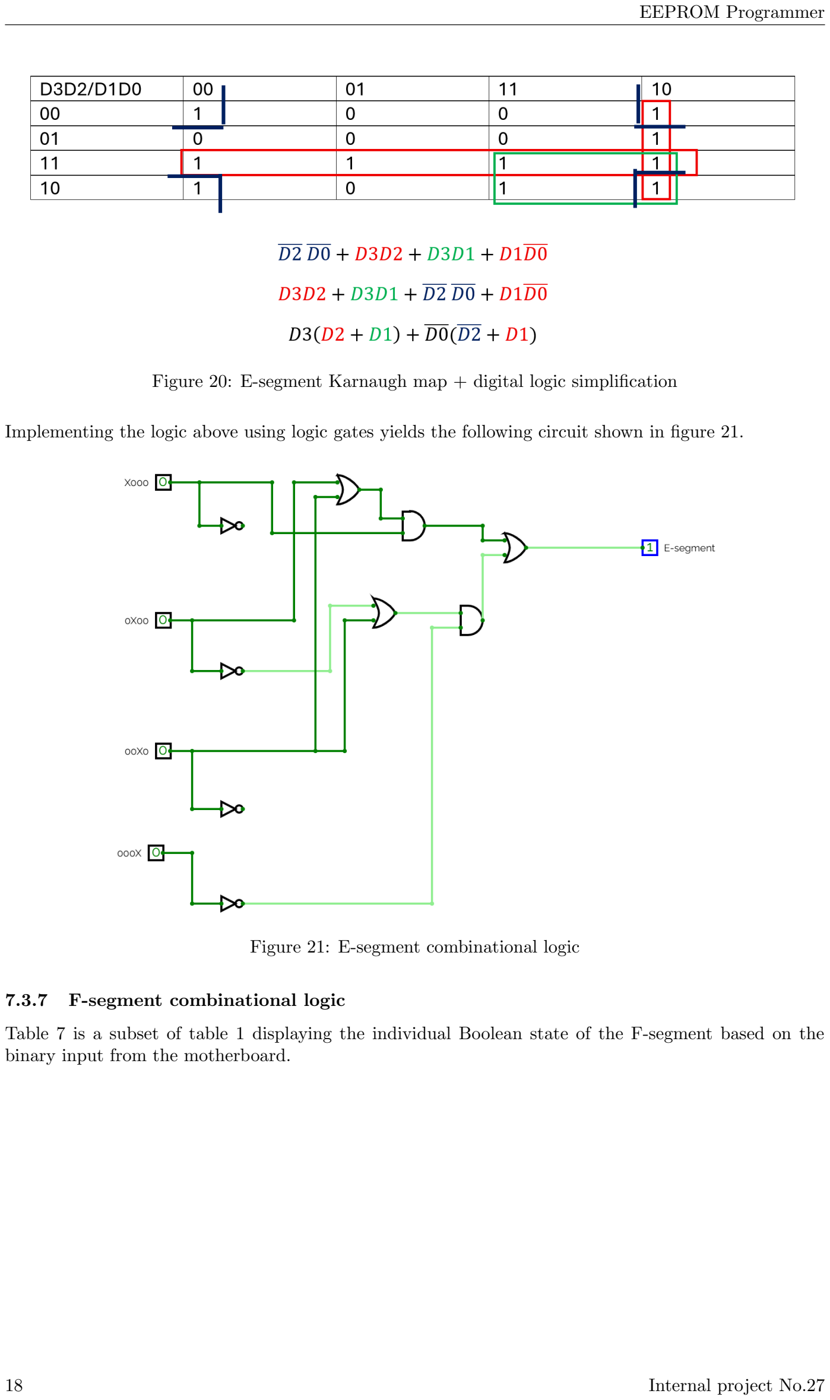
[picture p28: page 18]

Figure 20: E-segment Karnaugh map + digital logic simplification

Implementing the logic above using logic gates yields the following circuit shown in figure 21.

Figure 21: E-segment combinational logic

### 7.3.7 F-segment combinational logic

Table 7 is a subset of table 1 displaying the individual Boolean state of the F-segment based on the binary input from the motherboard.

Decimal representation | Input (D3D2D1D0) | F segment output
0 1 2 3 4 5 6 7 8 9 10 11 12 13 14 15 | 0000 0001 0010 0011 0100 0101 0110 0111 1000 1001 1010 1011 1100 1101 1110 1111 | 1 0 0 0 1 1 1 0 1 1 0 1 1 0 1 1

Table 7: F-segment Boolean state based on 4-bit input

Writing table 7 in a 4x4 Karnaugh map using gray code produces the following combinational logic shown in figure 22.

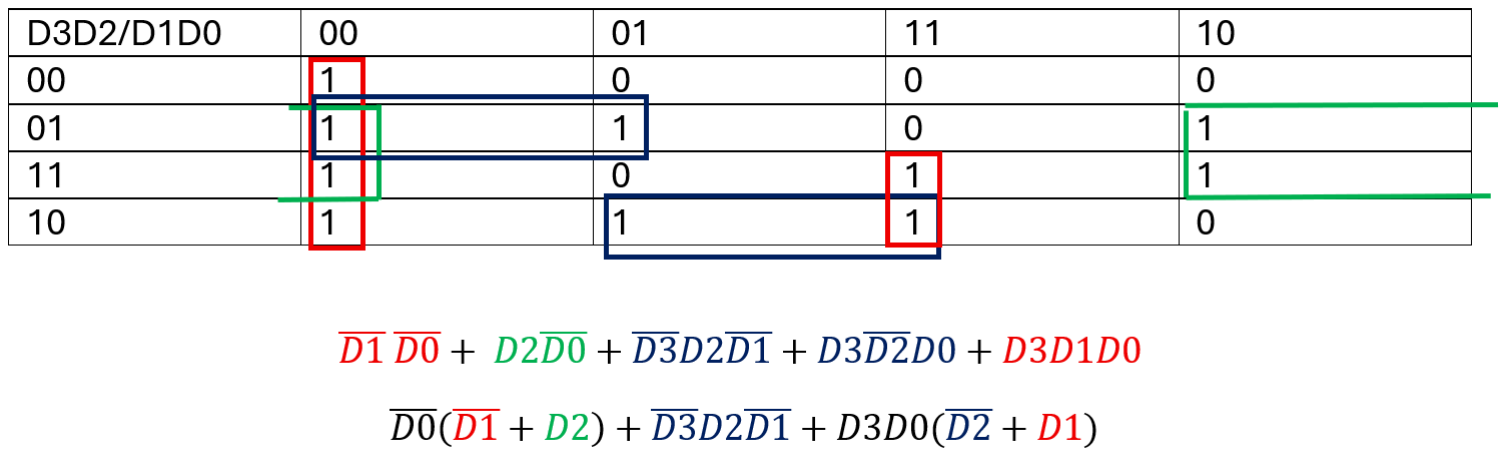
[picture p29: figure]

Figure 22: F-segment Karnaugh map + digital logic simplification

Implementing the logic above using logic gates yields the following circuit shown in figure 23.

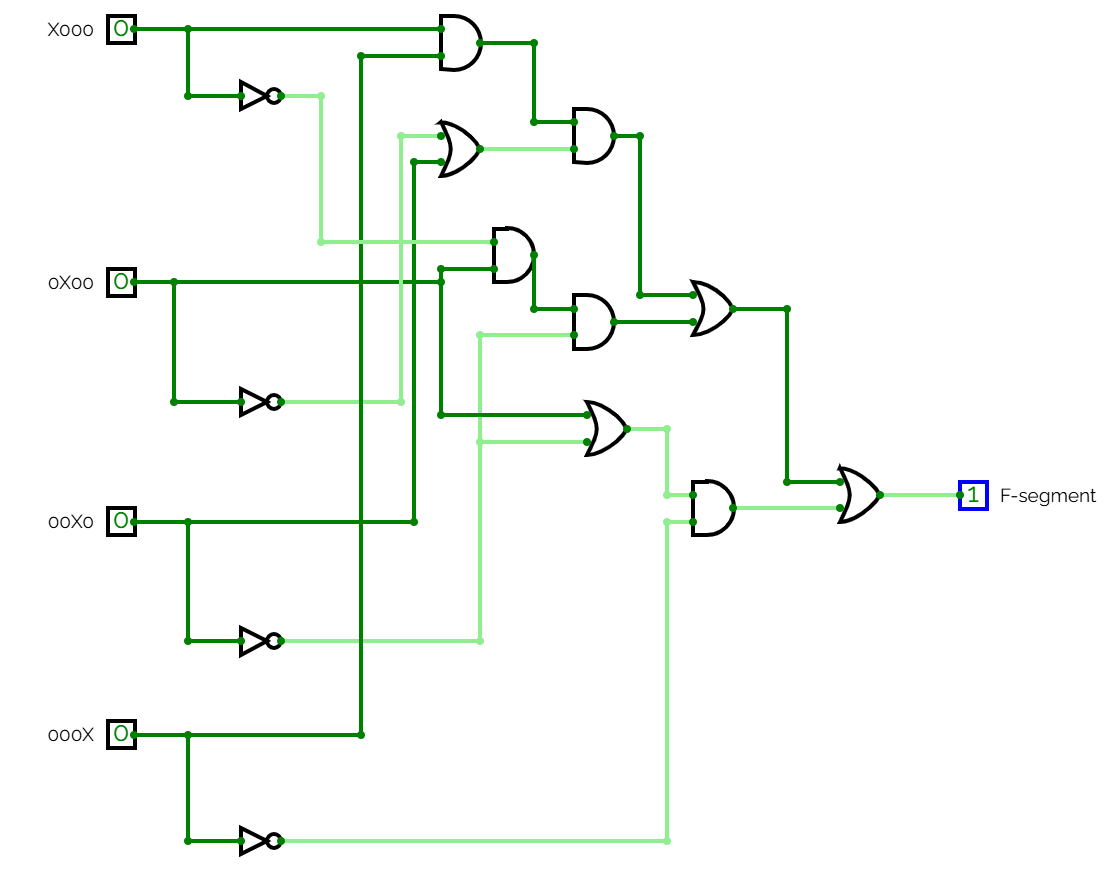
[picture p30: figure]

Figure 23: F-segment combinational logic

### 7.3.8 G-segment combinational logic

Table 8 is a subset of table 1 displaying the individual Boolean state of the G-segment based on the binary input from the motherboard.

Decimal representation | Input (D3D2D1D0) | G segment output
0 1 2 3 4 5 6 7 8 9 10 11 12 13 14 15 | 0000 0001 0010 0011 0100 0101 0110 0111 1000 1001 1010 1011 1100 1101 1110 1111 | 0 0 1 1 1 1 1 0 1 1 1 1 0 1 1 1

Table 8: B-segment Boolean state based on 4-bit input

Writing table 8 in a 4x4 Karnaugh map using gray code produces the following combinational logic shown in figure 24.

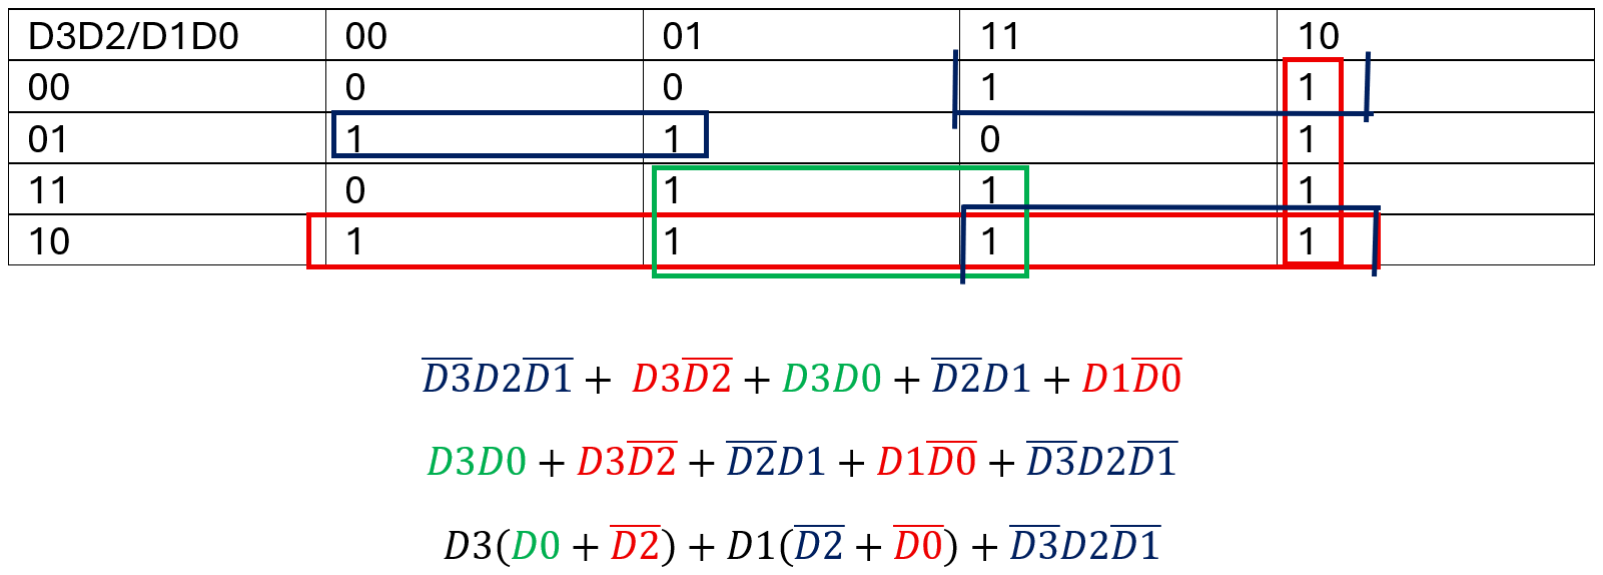
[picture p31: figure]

Figure 24: G-segment Karnaugh map + digital logic simplification

Implementing the logic above using logic gates yields the following circuit shown in figure 25.

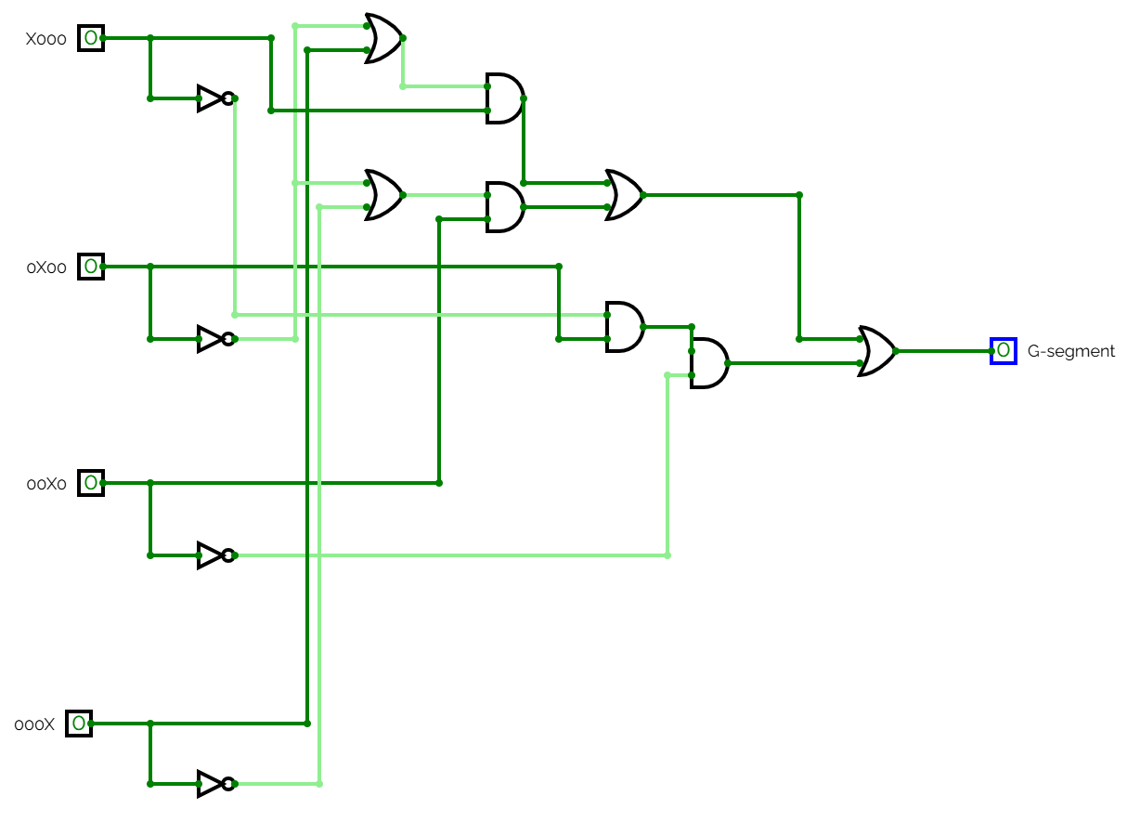
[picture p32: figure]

Figure 25: G-segment combinational logic

### 7.3.9 Combinational logic simulation

Before designing the physical PCB to decode binary into 7SD control signals, I ran my derived combinational logic through a simulator to ensure the base logic was sound. Check out my simulation on CircuitVerse here. (https://circuitverse.org/users/235298/projects/7-sd-display-encoder)

### 7.4 Motherboard Design

The motherboard design is integral to the functionality of the entire project. The motherboard is what allows all control signals and data signals to interface with the EEPROM hardware. The motherboard also hosts a suite of LEDs that show the status of each address, data, and control signal trace.

The motherboard docks with all daughterboards, taking signals from the MCU and directing them to the shift register, then taking the shift register signals and debug board signals through a multiplexer into the seven-segment decoder and ZIF (zero input force) socket which houses the EEPROM to be programmed.

The EEPROM programmer motherboard can be represented using the following functional block diagram in figure 26:

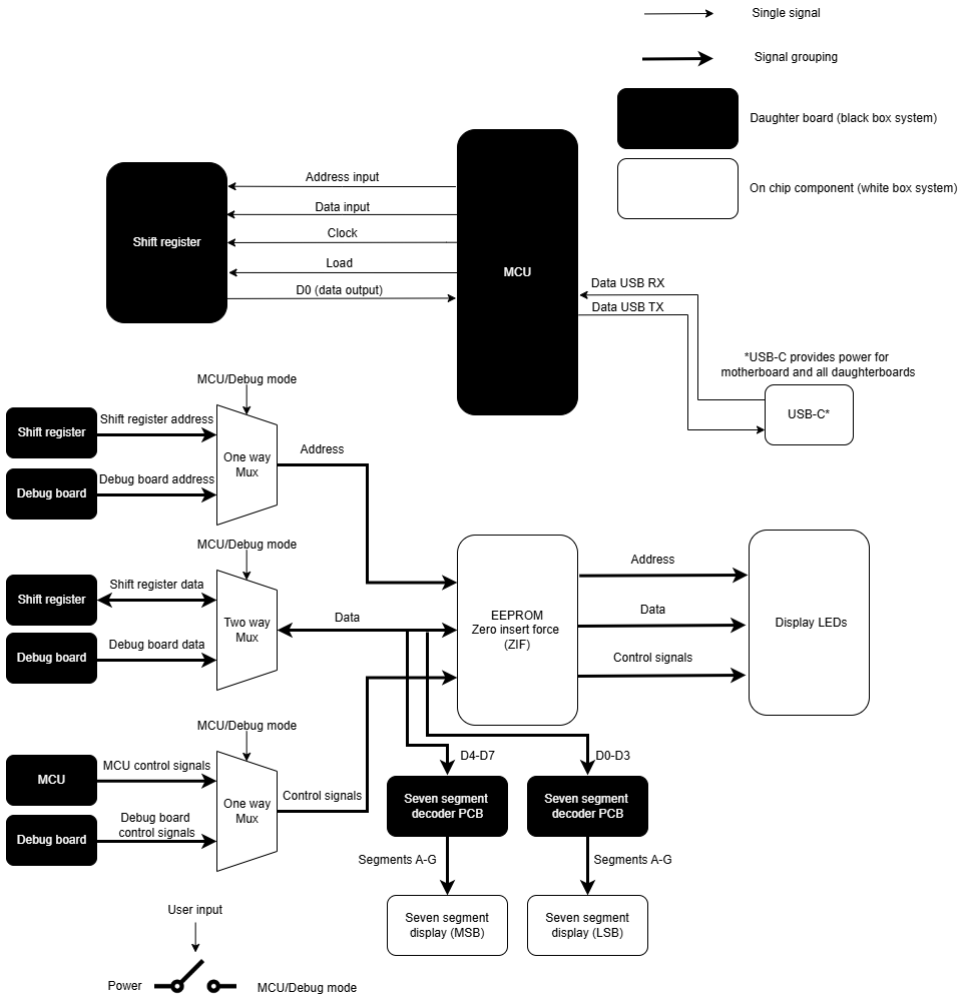
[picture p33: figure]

Figure 26: EEPROM programmer motherboard functional block diagram

As seen in the functional block diagram, the MCU/Debug mode switch allows the EEPROM Programmer to be controlled through either the MCU (Arduino) or the manual debug board satisfying R1 (from section 5.1). The motherboard also has a LED display showing the status of all address, data, and control signals in addition with a seven-segment display to humanize the data read out satisfying R2 (from section 5.2). While not shown on any block diagram, all PCBs have a power LED indicator which illuminates when the board is powered satisfying R3 (from section 5.3). Through the development of the shift register, the MCU can serially read and write data allowing for the minimization of required GPIOs thus keeping the list of compatible MCUs larger than if the MCU had to interface in parallel with the EEPROM satisfying R4 (from section 5.4).

Details on how R5 (from section 5.5) and R6 (from section 5.6) are satisfied are discussed in later sections.

Unlike the previous daughterboards, the motherboard doesn’t necessarily “do” anything, rather it connects everything together and interfaces with the user through the “MCU/Debug mode” switch to alternate between MCU control and human manual control.

## 8 Bill of Materials Formation and Considerations

The project component cost according to the BOM ended up coming out to $196.70 CAD however I already had ZIF (zero input force) sockets and EEPROMs from a previous order so I was able to cut the raw cost down to $183.69 CAD. I sourced all parts for this project using Digikey. Digikey has a price break feature where if you buy a greater quantity of items, the cost per unit decreases. In effect, buying ten of one item is usually cheaper than buying nine. By strategically leveraging this price break feature on a case by case basis, I was able to bring down my raw cost from $183.69 CAD down to $119.32 CAD, a 35% reduction in component costs.

Below is a table of all components required to build the EEPROM programmer before changing the quantities to take advantage of price breaks.

TABLE INCOMPLETE, coming soon.

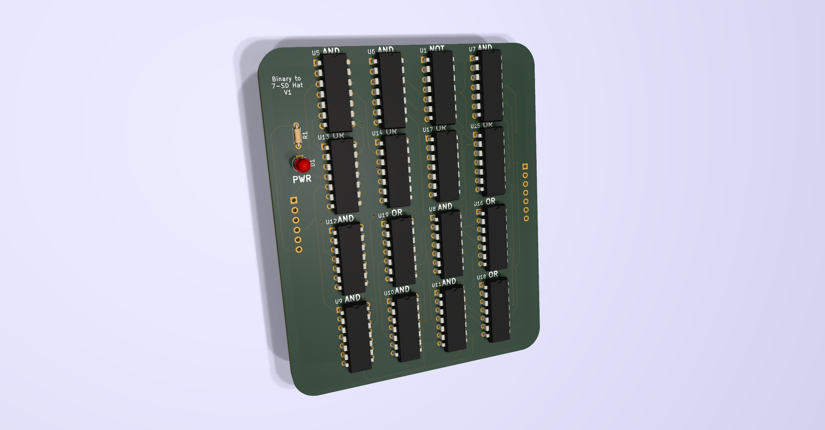
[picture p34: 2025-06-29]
7SD_hat/Seven Segment Display/photos/v1_hat_4.png

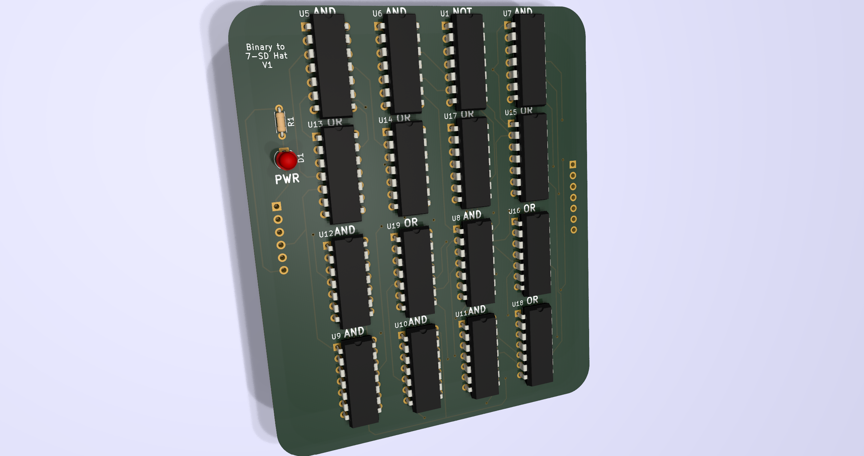
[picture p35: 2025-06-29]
7SD_hat/Seven Segment Display/photos/v1_hat_3.png

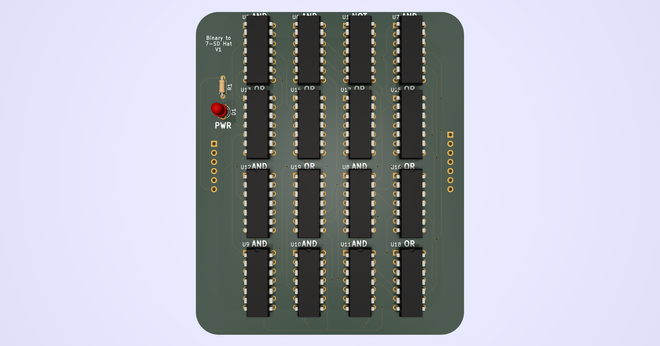
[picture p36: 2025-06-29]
7SD_hat/Seven Segment Display/photos/v1_hat_2.png

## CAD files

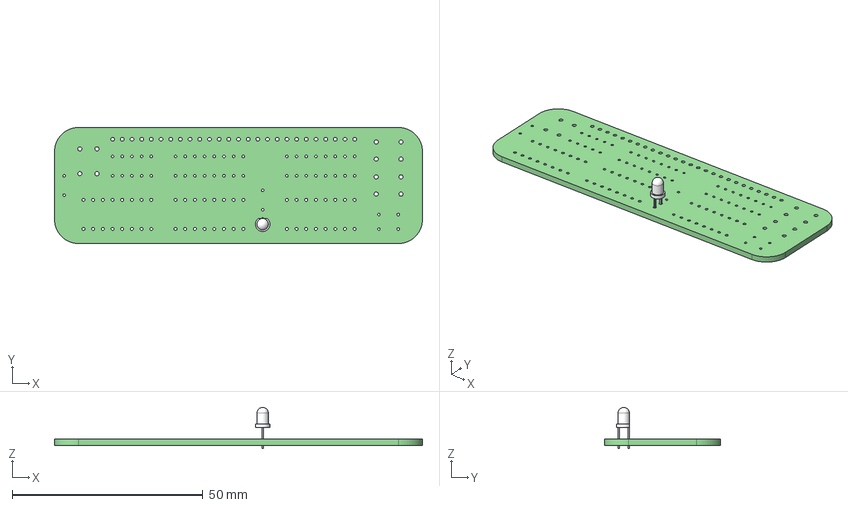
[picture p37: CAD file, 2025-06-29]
V2 3d models/DebugBoard.step
96.5 x 30.5 x 10.8 mm
DebugBoard PCB

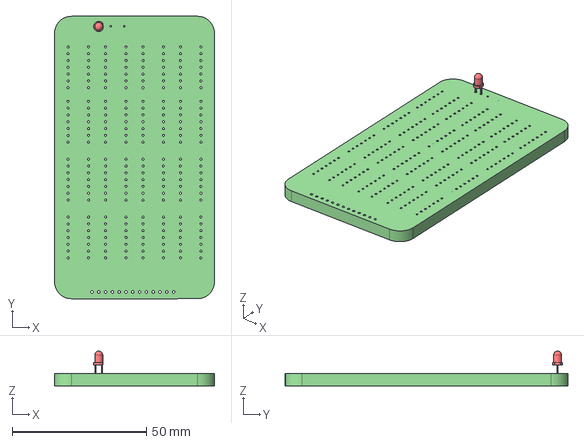
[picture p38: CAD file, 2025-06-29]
V2 3d models/Seven Segment Display.step
59.7 x 105.4 x 13.0 mm
Seven Segment Display PCB

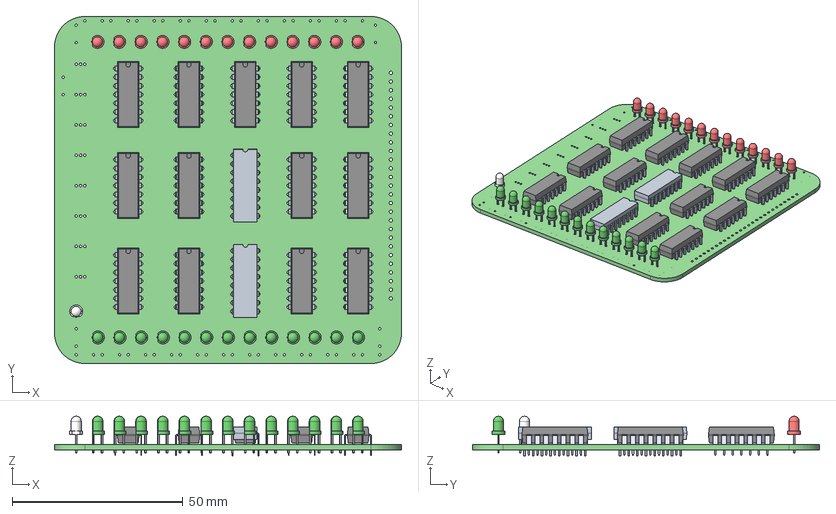
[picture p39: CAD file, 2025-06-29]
V2 3d models/ShiftRegisterPrototypeV2.step
101.6 x 101.6 x 11.6 mm
ShiftRegisterPrototypeV2 PCB

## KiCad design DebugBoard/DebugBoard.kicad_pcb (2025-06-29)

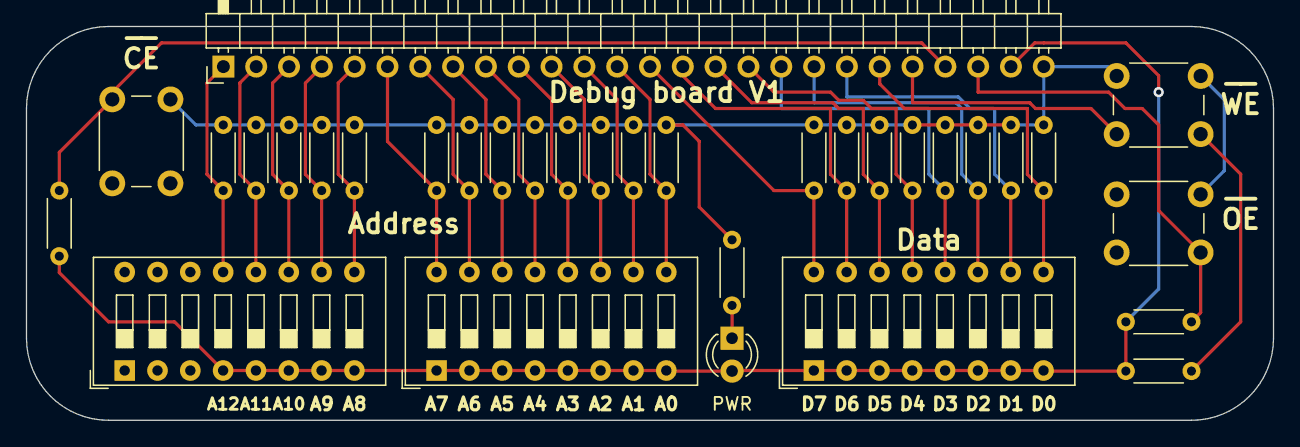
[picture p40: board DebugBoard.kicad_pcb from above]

Board: 2 copper layers, 96.5 x 30.5 mm, 33 parts (0 on the bottom side), 27 nets.

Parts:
D1: LED; LED_D3.0mm_white
J1: Conn_01x26; PinHeader_1x26_P2.54mm_Horizontal
R1, R2, R3, R4, R5, R6, R7, R8, R9, R10, R11, R12, R13, R14, R15, R16, R17, R18, R19, R20, R21, R22, R23, R24, R25: R_US; R_Axial_DIN0204_L3.6mm_D1.6mm_P5.08mm_Horizontal
SW1, SW2, SW3: SW_DIP_x08; SW_DIP_SPSTx08_Slide_9.78x22.5mm_W7.62mm_P2.54mm
SW4, SW5, SW6: SW_Push; SW_PUSH_6mm

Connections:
A0: J1.13, R24.1, SW3.9
A1: J1.12, R23.1, SW3.10
A2: J1.11, R22.1, SW3.11
A3: J1.10, R21.1, SW3.12
A4: J1.9, R20.1, SW3.13
A5: J1.8, R19.1, SW3.14
A6: J1.7, R18.1, SW3.15
A7: J1.6, R17.1, SW3.16
A8: J1.5, R16.1, SW2.9
A9: J1.4, R15.1, SW2.10
A10: J1.3, R14.1, SW2.11
A11: J1.2, R13.1, SW2.12
A12: J1.1, R12.1, SW2.13
CE': J1.23, R5.2, SW5.2
D0: J1.21, R11.1, SW1.9
D1: J1.20, R10.1, SW1.10
D2: J1.19, R9.1, SW1.11
D3: J1.18, R8.1, SW1.12
D4: J1.17, R6.1, SW1.13
D5: J1.16, R4.1, SW1.14
D6: J1.15, R2.1, SW1.15
D7: J1.14, R1.1, SW1.16
GND: J1.26, R1.2, R2.2, R4.2, R6.2, R8.2, R9.2, R10.2, R11.2, R12.2, R13.2, R14.2, R15.2, R16.2, R17.2, R18.2, R19.2, R20.2, R21.2, R22.2, R23.2, R24.2, R25.1, SW4.1, SW5.1, SW6.1
unnamed: D1.1 (K), R25.2
OE': J1.24, R3.2, SW6.2
VCC: D1.2 (A), J1.25, R3.1, R5.1, R7.1, SW1.1, SW1.2, SW1.3, SW1.4, SW1.5, SW1.6, SW1.7, SW1.8, SW2.4, SW2.5, SW2.6, SW2.7, SW2.8, SW3.1, SW3.2, SW3.3, SW3.4, SW3.5, SW3.6, SW3.7, SW3.8
WE': J1.22, R7.2, SW4.2

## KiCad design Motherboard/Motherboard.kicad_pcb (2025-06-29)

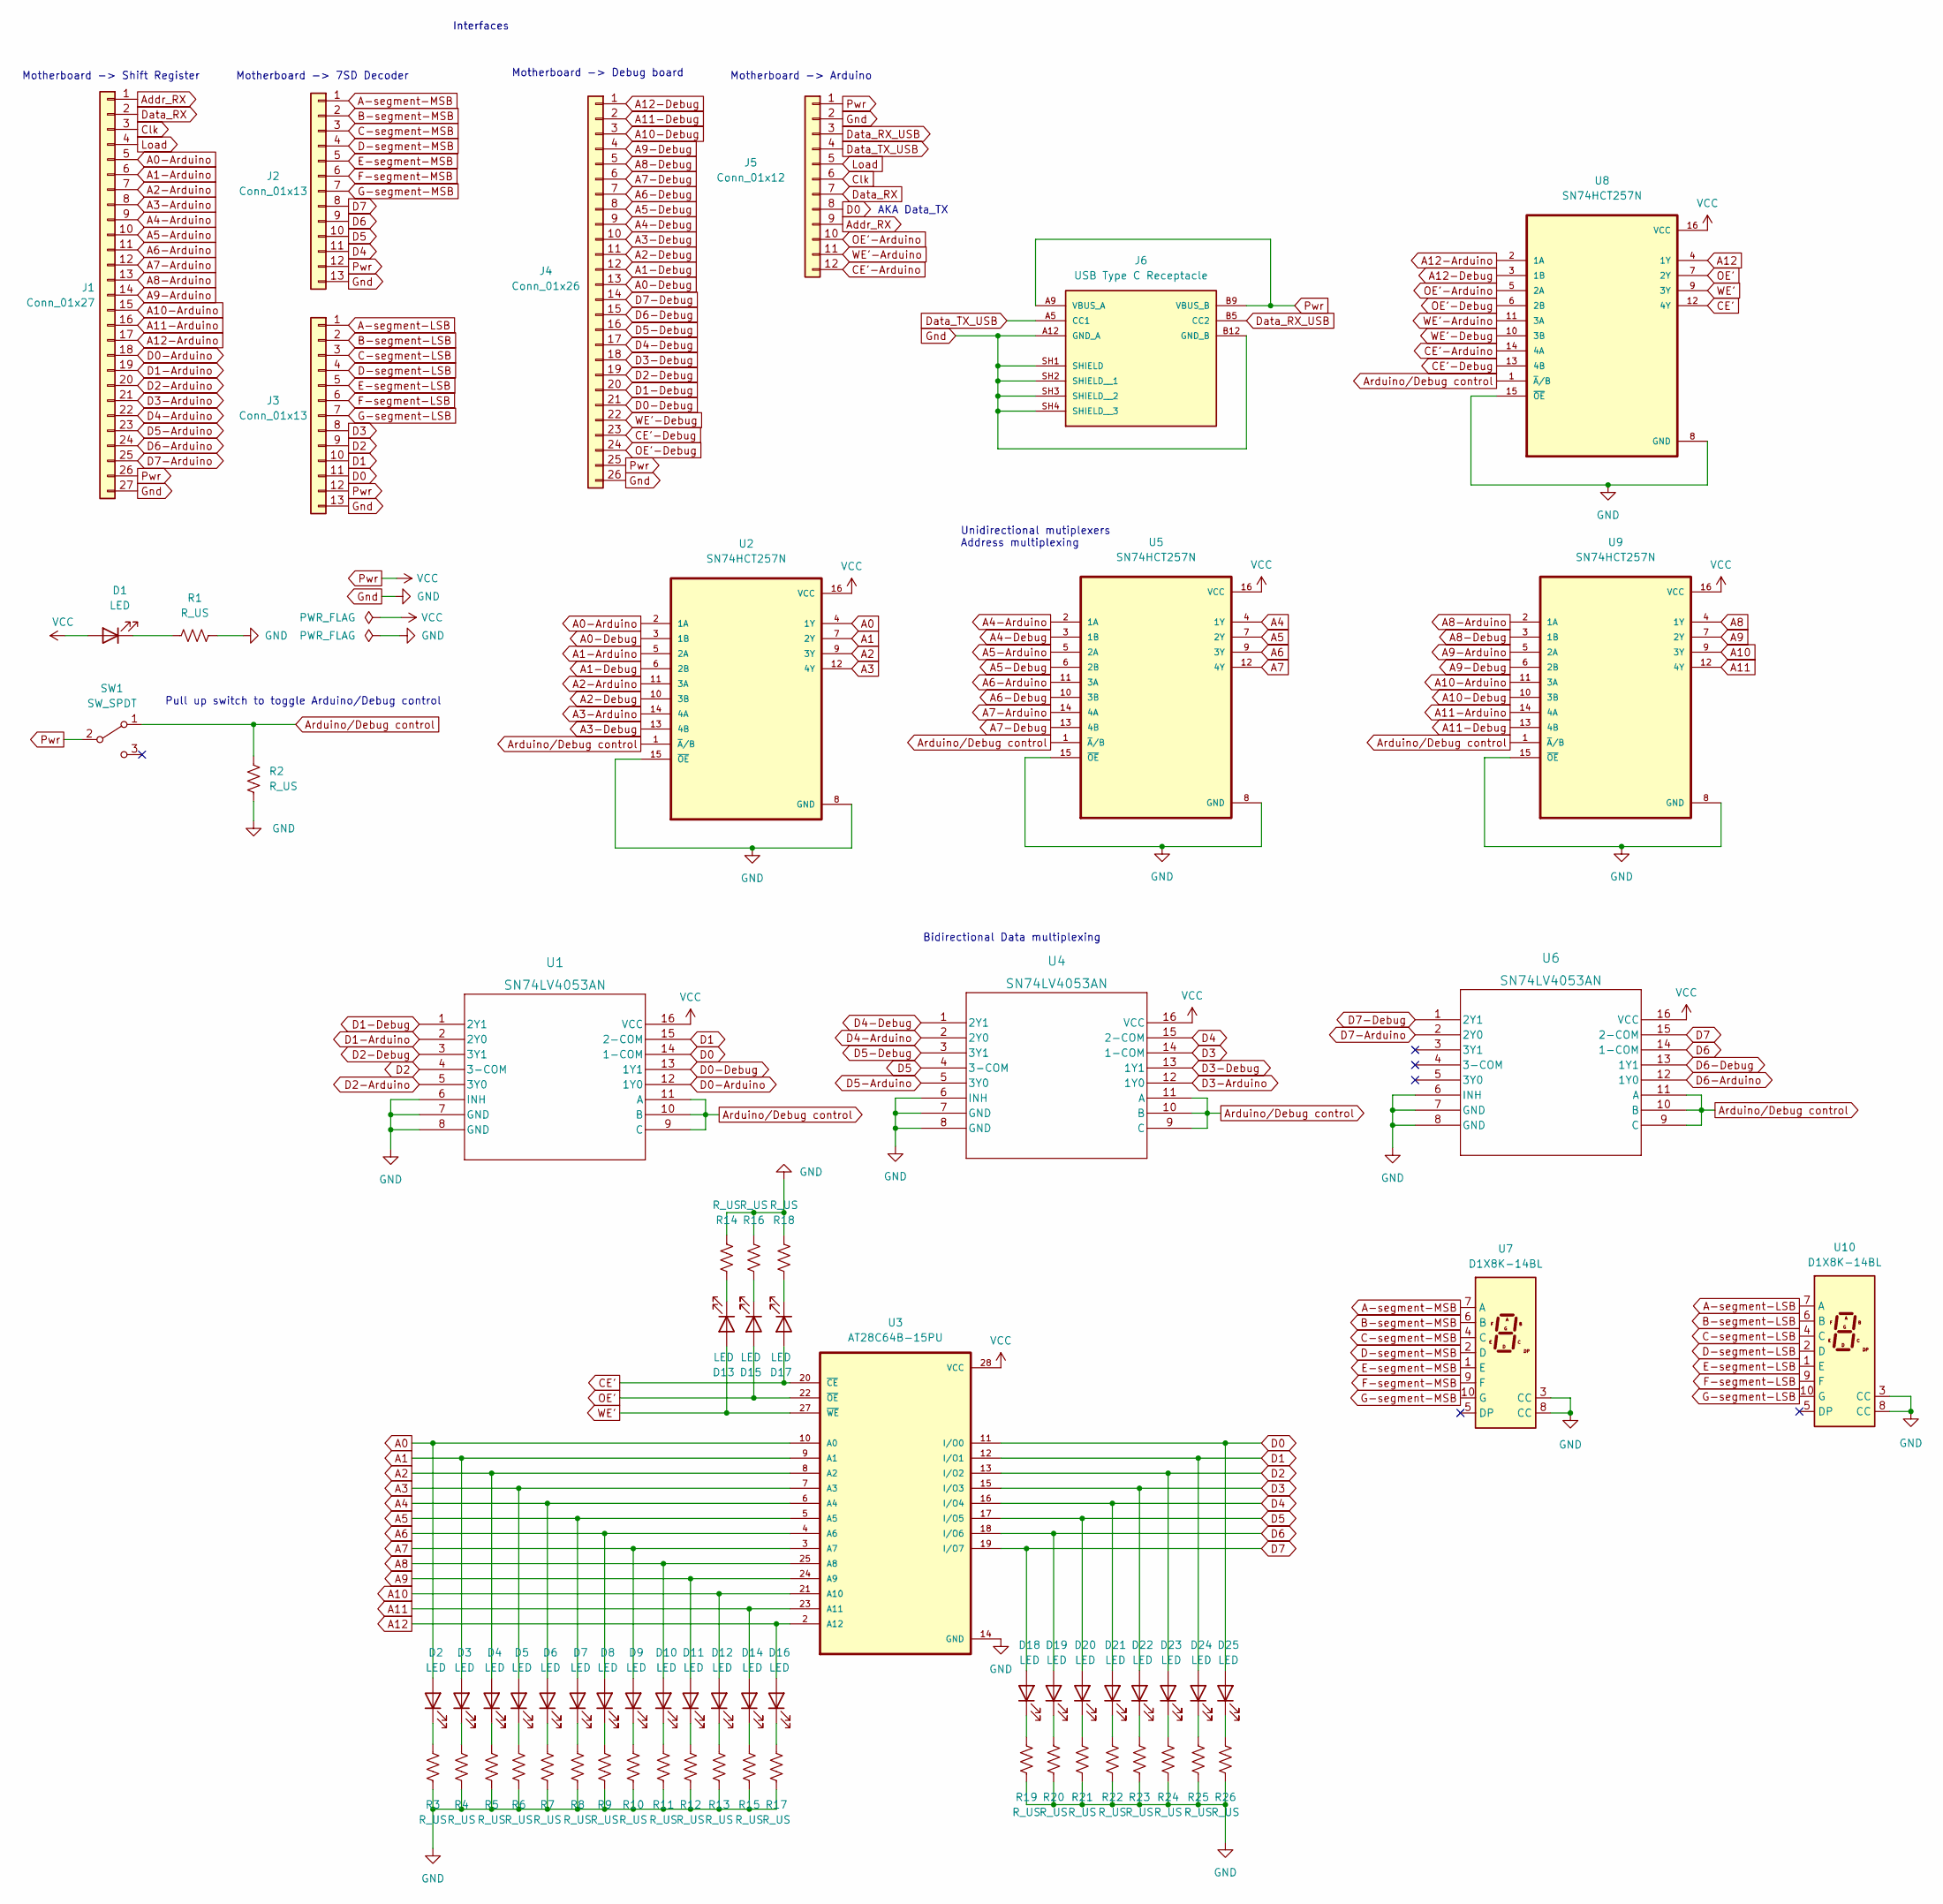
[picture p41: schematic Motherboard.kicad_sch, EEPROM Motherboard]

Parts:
D1: LED; LED_D3.0mm_red
D2, D3, D4, D5, D6, D7, D8, D9, D10, D11, D12, D14, D16: LED; LED_D3.0mm_blue
D13, D15, D17: LED; LED_D3.0mm_yellow
D18, D19, D20, D21, D22, D23, D24, D25: LED; LED_D3.0mm_white
J1: Conn_01x27; PinSocket_1x27_P2.54mm_Horizontal
J2, J3: Conn_01x13; PinSocket_1x13_P2.54mm_Horizontal
J4: Conn_01x26; PinSocket_1x26_P2.54mm_Horizontal
J5: Conn_01x12; PinSocket_1x12_P2.54mm_Horizontal
J6: USB Type C Receptacle; AMPHENOL_10164359-00011LF; PARTREV A
R1, R2, R3, R4, R5, R6, R7, R8, R9, R10, R11, R12, R13, R14, R15, R16, R17, R18, R19, R20, R21, R22, R23, R24, R25, R26: R_US; R_Axial_DIN0204_L3.6mm_D1.6mm_P5.08mm_Horizontal
SW1: SW_SPDT; SPDT_SW_SLW-116641-5A-S-D
U1, U4, U6: SN74LV4053AN
U2, U5, U8, U9: SN74HCT257N; DIP794W45P254L1969H508Q16
U3: AT28C64B-15PU; EEPROM in 40pin ZIF; PARTREV B
U7, U10: D1X8K-14BL; D1X8K

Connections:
A0: D2.2 (A), U2.4 (1Y), U3.10 (A0)
A0-Arduino: J1.5, U2.2 (1A)
A0-Debug: J4.13, U2.3 (1B)
A1: D3.2 (A), U2.7 (2Y), U3.9 (A1)
A1-Arduino: J1.6, U2.5 (2A)
A1-Debug: J4.12, U2.6 (2B)
A2: D4.2 (A), U2.9 (3Y), U3.8 (A2)
A2-Arduino: J1.7, U2.11 (3A)
A2-Debug: J4.11, U2.10 (3B)
A3: D5.2 (A), U2.12 (4Y), U3.7 (A3)
A3-Arduino: J1.8, U2.14 (4A)
A3-Debug: J4.10, U2.13 (4B)
A4: D6.2 (A), U3.6 (A4), U5.4 (1Y)
A4-Arduino: J1.9, U5.2 (1A)
A4-Debug: J4.9, U5.3 (1B)
A5: D7.2 (A), U3.5 (A5), U5.7 (2Y)
A5-Arduino: J1.10, U5.5 (2A)
A5-Debug: J4.8, U5.6 (2B)
A6: D8.2 (A), U3.4 (A6), U5.9 (3Y)
A6-Arduino: J1.11, U5.11 (3A)
A6-Debug: J4.7, U5.10 (3B)
A7: D9.2 (A), U3.3 (A7), U5.12 (4Y)
A7-Arduino: J1.12, U5.14 (4A)
A7-Debug: J4.6, U5.13 (4B)
A8: D10.2 (A), U3.25 (A8), U9.4 (1Y)
A8-Arduino: J1.13, U9.2 (1A)
A8-Debug: J4.5, U9.3 (1B)
A9: D11.2 (A), U3.24 (A9), U9.7 (2Y)
A9-Arduino: J1.14, U9.5 (2A)
A9-Debug: J4.4, U9.6 (2B)
A10: D12.2 (A), U3.21 (A10), U9.9 (3Y)
A10-Arduino: J1.15, U9.11 (3A)
A10-Debug: J4.3, U9.10 (3B)
A11: D14.2 (A), U3.23 (A11), U9.12 (4Y)
A11-Arduino: J1.16, U9.14 (4A)
A11-Debug: J4.2, U9.13 (4B)
A12: D16.2 (A), U3.2 (A12), U8.4 (1Y)
A12-Arduino: J1.17, U8.2 (1A)
A12-Debug: J4.1, U8.3 (1B)
A-segment-LSB: J3.1, U10.7 (A)
A-segment-MSB: J2.1, U7.7 (A)
Addr_RX: J1.1, J5.9
Arduino/Debug control: R2.1, SW1.1 (A), U1.9 (C), U1.10 (B), U1.11 (A), U2.1 (~A/B), U4.9 (C), U4.10 (B), U4.11 (A), U5.1 (~A/B), U6.9 (C), U6.10 (B), U6.11 (A), U8.1 (~A/B), U9.1 (~A/B)
B-segment-LSB: J3.2, U10.6 (B)
B-segment-MSB: J2.2, U7.6 (B)
C-segment-LSB: J3.3, U10.4 (C)
C-segment-MSB: J2.3, U7.4 (C)
CE': D17.2 (A), U3.20 (~CE), U8.12 (4Y)
CE'-Arduino: J5.12, U8.14 (4A)
CE'-Debug: J4.23, U8.13 (4B)
Clk: J1.3, J5.6
D0: D25.2 (A), J3.11, J5.8, U1.14 (1-COM), U3.11 (I/O0)
D0-Arduino: J1.18, U1.12 (1Y0)
D0-Debug: J4.21, U1.13 (1Y1)
D1: D24.2 (A), J3.10, U1.15 (2-COM), U3.12 (I/O1)
D1-Arduino: J1.19, U1.2 (2Y0)
D1-Debug: J4.20, U1.1 (2Y1)
D2: D23.2 (A), J3.9, U1.4 (3-COM), U3.13 (I/O2)
D2-Arduino: J1.20, U1.5 (3Y0)
D2-Debug: J4.19, U1.3 (3Y1)
D3: D22.2 (A), J3.8, U3.15 (I/O3), U4.14 (1-COM)
D3-Arduino: J1.21, U4.12 (1Y0)
D3-Debug: J4.18, U4.13 (1Y1)
D4: D21.2 (A), J2.11, U3.16 (I/O4), U4.15 (2-COM)
D4-Arduino: J1.22, U4.2 (2Y0)
D4-Debug: J4.17, U4.1 (2Y1)
D5: D20.2 (A), J2.10, U3.17 (I/O5), U4.4 (3-COM)
D5-Arduino: J1.23, U4.5 (3Y0)
D5-Debug: J4.16, U4.3 (3Y1)
D6: D19.2 (A), J2.9, U3.18 (I/O6), U6.14 (1-COM)
D6-Arduino: J1.24, U6.12 (1Y0)
D6-Debug: J4.15, U6.13 (1Y1)
D7: D18.2 (A), J2.8, U3.19 (I/O7), U6.15 (2-COM)
D7-Arduino: J1.25, U6.2 (2Y0)
D7-Debug: J4.14, U6.1 (2Y1)
D-segment-LSB: J3.4, U10.2 (D)
D-segment-MSB: J2.4, U7.2 (D)
Data_RX: J1.2, J5.7
Data_RX_USB: J5.3, J6.B5 (CC2)
Data_TX_USB: J5.4, J6.A5 (CC1)
E-segment-LSB: J3.5, U10.1 (E)
E-segment-MSB: J2.5, U7.1 (E)
F-segment-LSB: J3.6, U10.9 (F)
F-segment-MSB: J2.6, U7.9 (F)
G-segment-LSB: J3.7, U10.10 (G)
G-segment-MSB: J2.7, U7.10 (G)
Gnd: J1.27, J2.13, J3.13, J4.26, J5.2, J6.A12 (GND_A), J6.B12 (GND_B), J6.SH1 (SHIELD), J6.SH2 (SHIELD__1), J6.SH3 (SHIELD__2), J6.SH4 (SHIELD__3), R1.1, R2.2, R3.1, R4.1, R5.1, R6.1, R7.1, R8.1, R9.1, R10.1, R11.1, R12.1, R13.1, R14.1, R15.1, R16.1, R17.1, R18.1, R19.1, R20.1, R21.1, R22.1, R23.1, R24.1, R25.1, R26.1, U1.6 (INH), U1.7 (GND), U1.8 (GND), U2.8 (GND), U2.15 (~OE), U3.14 (GND), U4.6 (INH), U4.7 (GND), U4.8 (GND), U5.8 (GND), U5.15 (~OE), U6.6 (INH), U6.7 (GND), U6.8 (GND), U7.3 (CC), U7.8 (CC), U8.8 (GND), U8.15 (~OE), U9.8 (GND), U9.15 (~OE), U10.3 (CC), U10.8 (CC)
Load: J1.4, J5.5
unnamed: D1.1 (K), R1.2
unnamed: D2.1 (K), R3.2
unnamed: D3.1 (K), R4.2
unnamed: D4.1 (K), R5.2
unnamed: D5.1 (K), R6.2
unnamed: D6.1 (K), R7.2
unnamed: D7.1 (K), R8.2
unnamed: D8.1 (K), R9.2
unnamed: D9.1 (K), R10.2
unnamed: D10.1 (K), R11.2
unnamed: D11.1 (K), R12.2
unnamed: D12.1 (K), R13.2
unnamed: D13.1 (K), R14.2
unnamed: D14.1 (K), R15.2
unnamed: D15.1 (K), R16.2
unnamed: D16.1 (K), R17.2
unnamed: D17.1 (K), R18.2
unnamed: D18.1 (K), R19.2
unnamed: D19.1 (K), R20.2
unnamed: D20.1 (K), R21.2
unnamed: D21.1 (K), R22.2
unnamed: D22.1 (K), R23.2
unnamed: D23.1 (K), R24.2
unnamed: D24.1 (K), R25.2
unnamed: D25.1 (K), R26.2
OE': D15.2 (A), U3.22 (~OE), U8.7 (2Y)
OE'-Arduino: J5.10, U8.5 (2A)
OE'-Debug: J4.24, U8.6 (2B)
Pwr: D1.2 (A), J1.26, J2.12, J3.12, J4.25, J5.1, J6.A9 (VBUS_A), J6.B9 (VBUS_B), SW1.2 (B), U1.16 (VCC), U2.16 (VCC), U3.28 (VCC), U4.16 (VCC), U5.16 (VCC), U6.16 (VCC), U8.16 (VCC), U9.16 (VCC)
WE': D13.2 (A), U3.27 (~WE), U8.9 (3Y)
WE'-Arduino: J5.11, U8.11 (3A)
WE'-Debug: J4.22, U8.10 (3B)

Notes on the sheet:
Bidirectional Data multiplexing
Motherboard -> 7SD Decoder
Pull up switch to toggle Arduino/Debug control
Motherboard -> Shift Register
Motherboard -> Arduino
Interfaces
Unidirectional mutiplexers Address multiplexing
AKA Data_TX
Motherboard -> Debug board

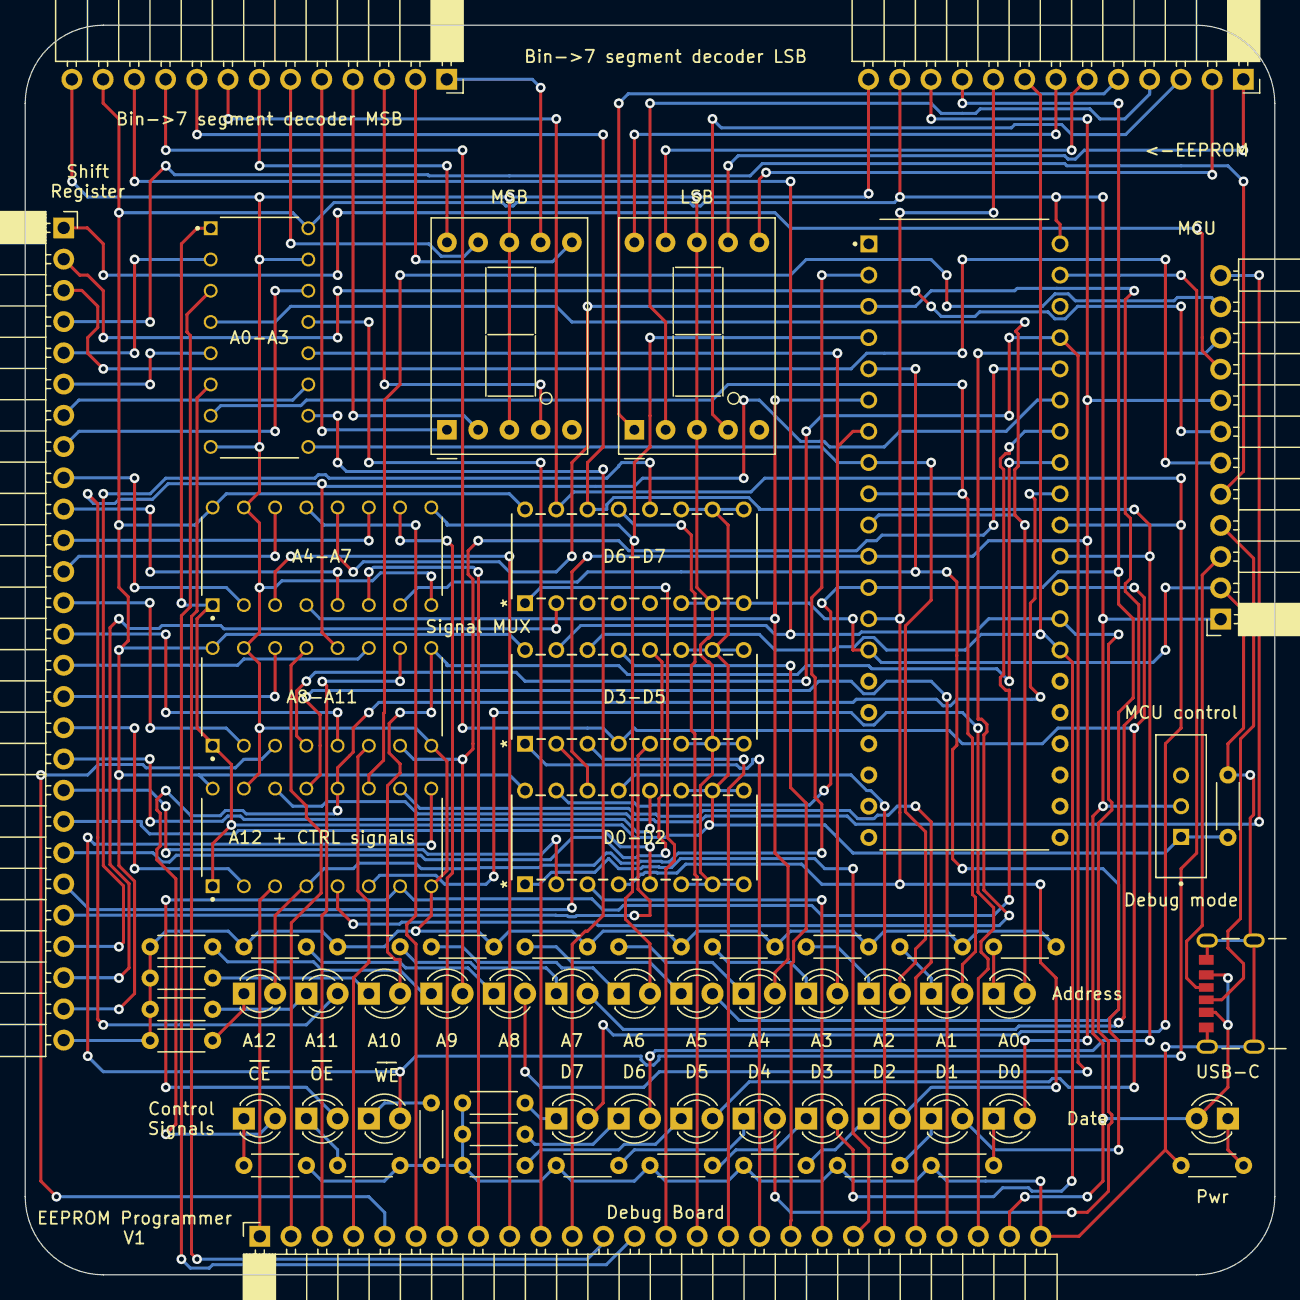
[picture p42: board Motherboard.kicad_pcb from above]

Board: 2 copper layers, 101.6 x 101.6 mm, 68 parts (0 on the bottom side), 120 nets.

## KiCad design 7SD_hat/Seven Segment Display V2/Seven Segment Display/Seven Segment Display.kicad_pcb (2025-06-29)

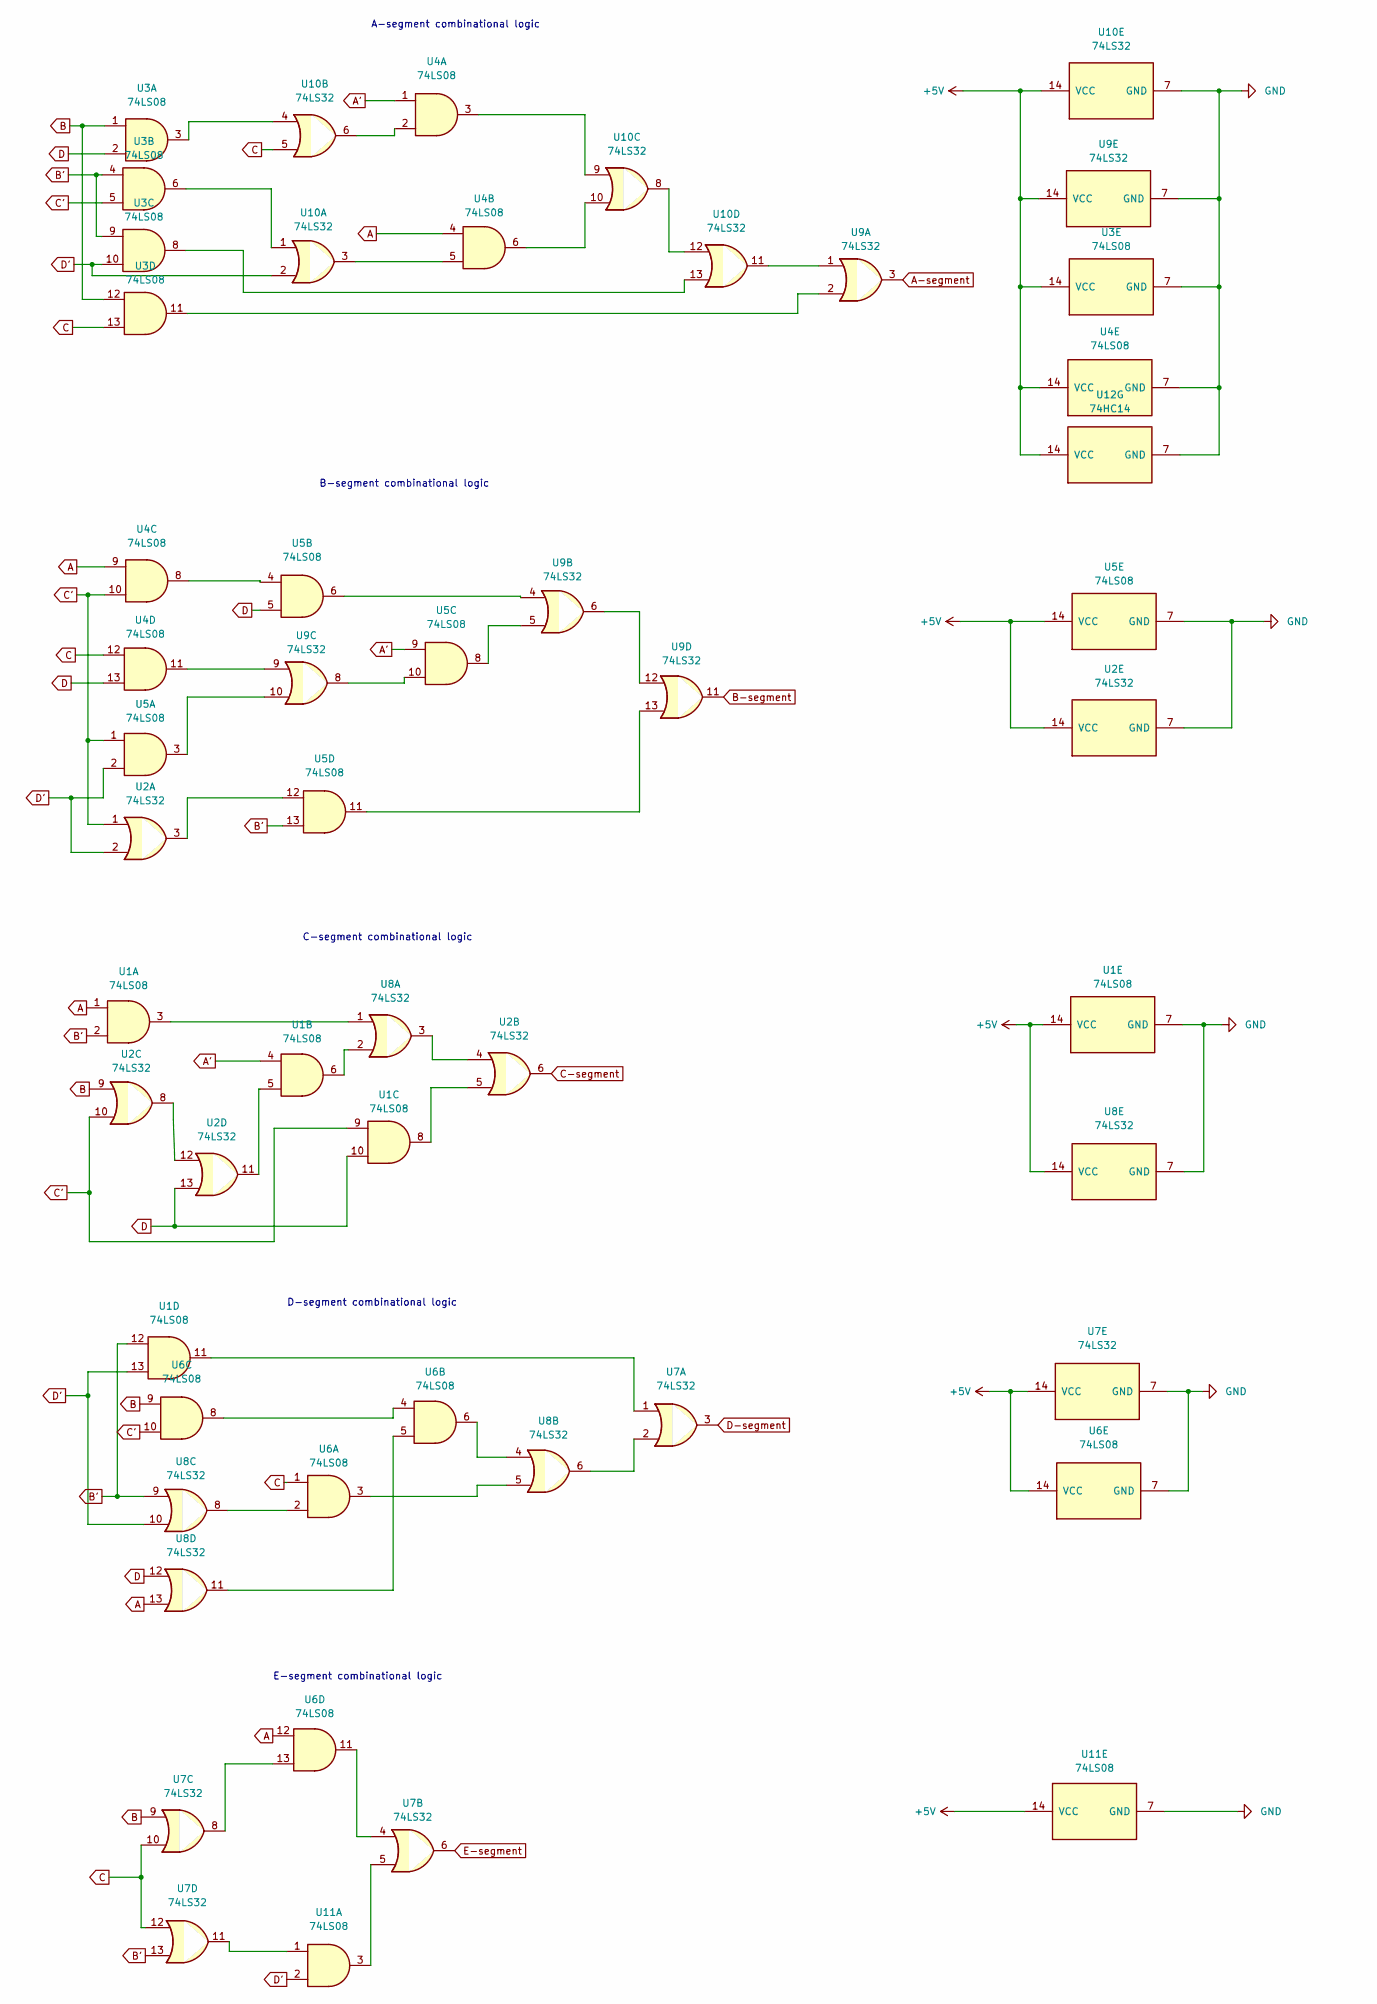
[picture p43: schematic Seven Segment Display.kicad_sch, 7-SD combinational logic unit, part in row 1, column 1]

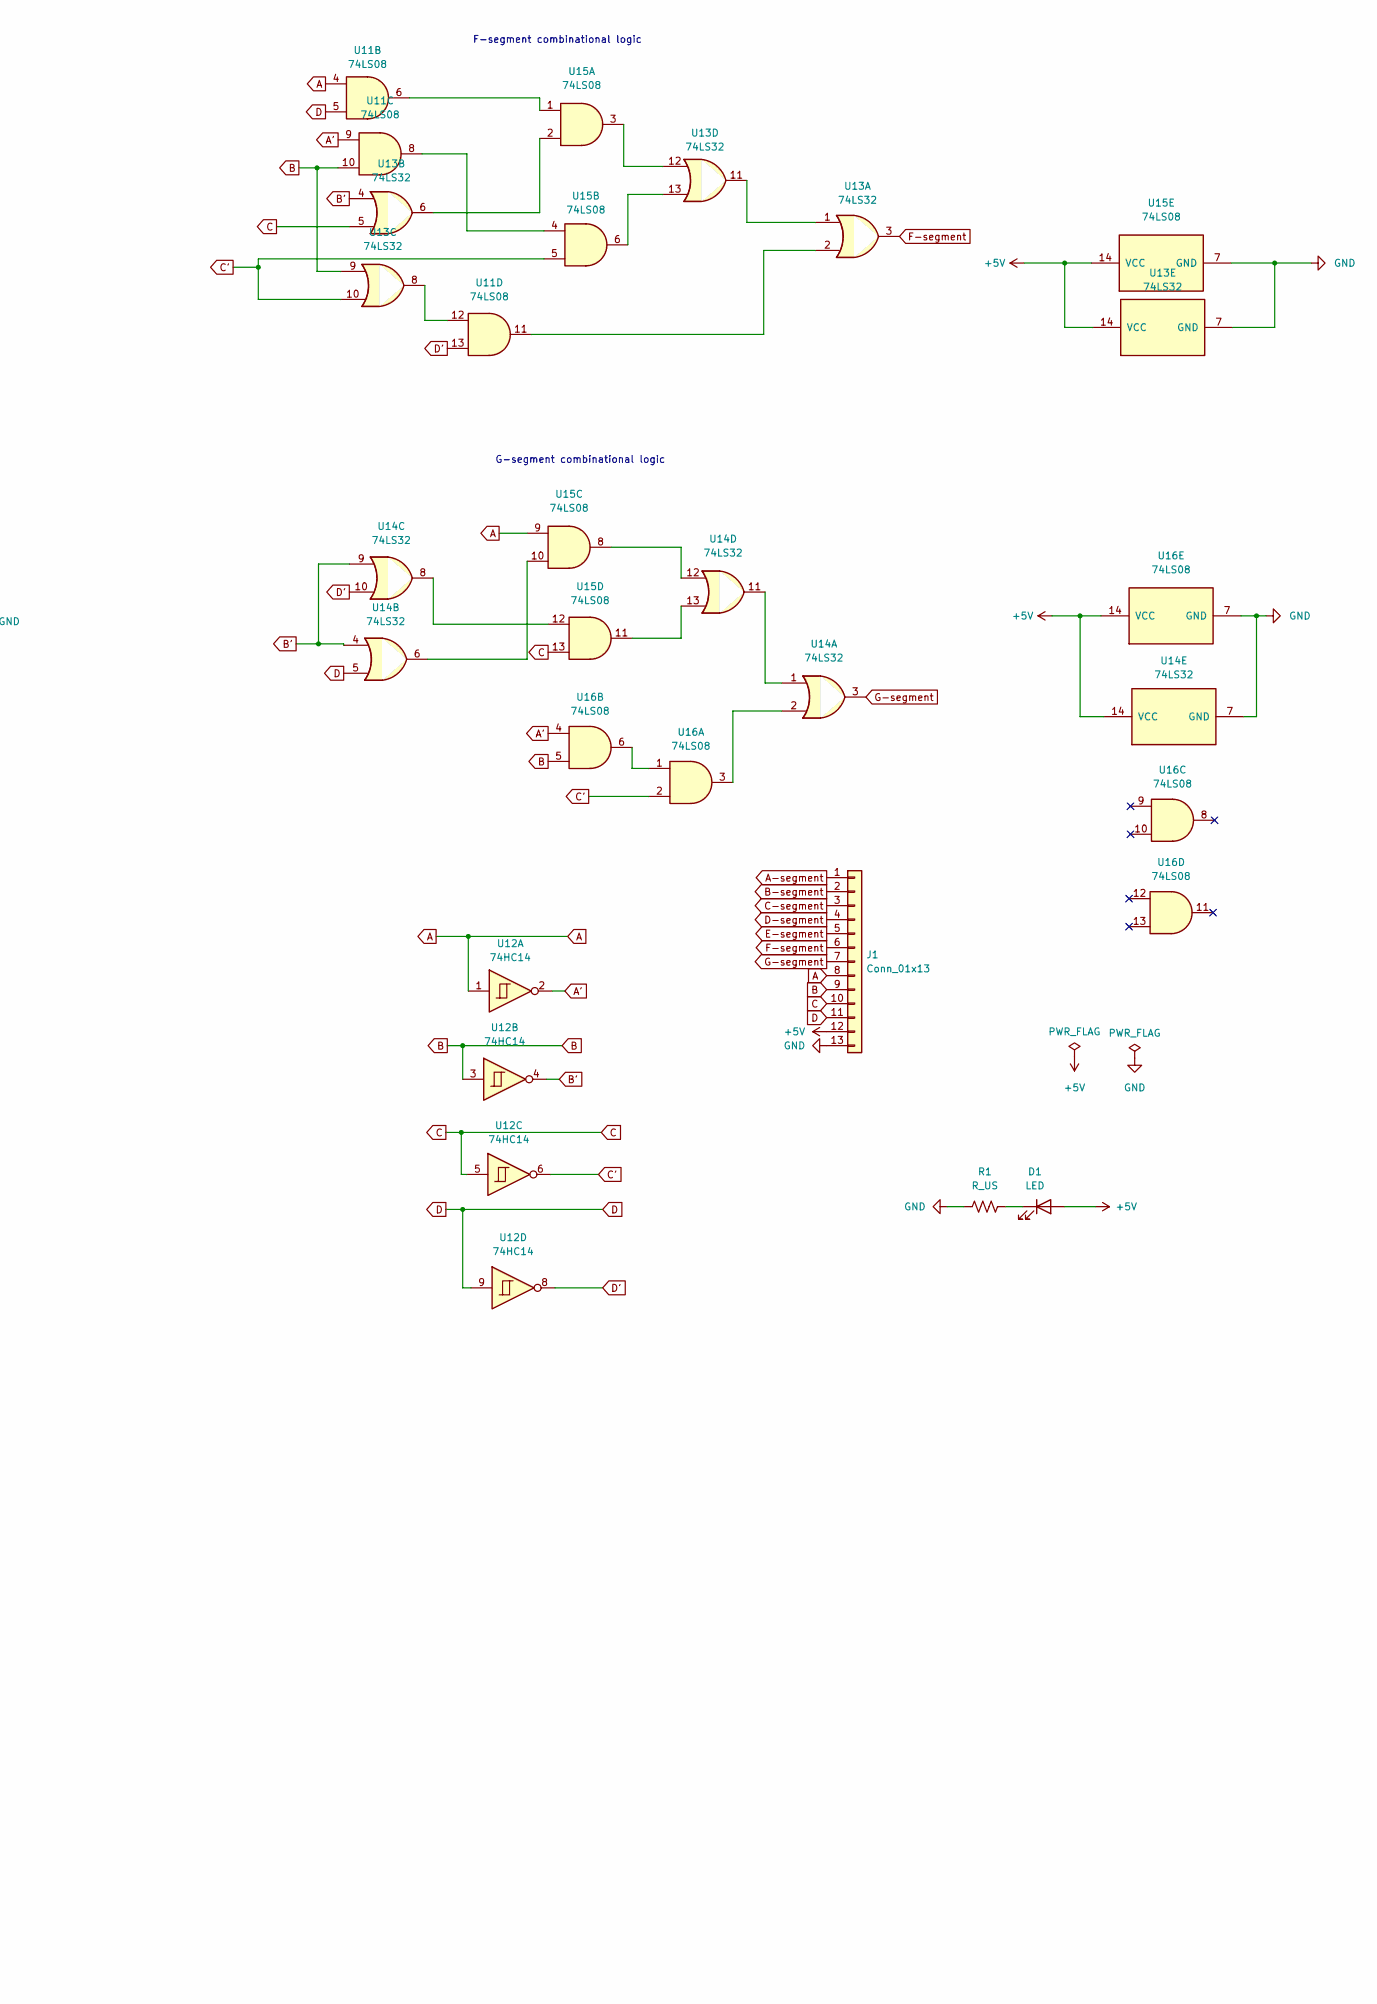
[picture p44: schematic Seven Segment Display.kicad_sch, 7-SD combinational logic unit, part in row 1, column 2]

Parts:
D1: LED; LED_D3.0mm_red
J1: Conn_01x13; PinHeader_1x13_P2.54mm_Horizontal
R1: R_US; R_Axial_DIN0204_L3.6mm_D1.6mm_P5.08mm_Horizontal
U1, U3, U4, U5, U6, U11, U15, U16: 74LS08; DIP-14_W7.62mm
U2, U7, U8, U9, U10, U13, U14: 74LS32; DIP-14_W7.62mm
U12: 74HC14; DIP-14_W7.62mm

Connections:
+5V: D1.2 (A), J1.12, U1.14 (VCC), U2.14 (VCC), U3.14 (VCC), U4.14 (VCC), U5.14 (VCC), U6.14 (VCC), U7.14 (VCC), U8.14 (VCC), U9.14 (VCC), U10.14 (VCC), U11.14 (VCC), U12.14 (VCC), U13.14 (VCC), U14.14 (VCC), U15.14 (VCC), U16.14 (VCC)
A: J1.8, U1.1, U4.4, U4.9, U6.12, U8.13, U11.4, U12.1, U15.9
A': U1.4, U4.1, U5.9, U11.9, U12.2, U16.4
A-segment: J1.1, U9.3
B: J1.9, U2.9, U3.1, U3.12, U6.9, U7.9, U11.10, U12.3, U13.9, U16.5
B': U1.2, U1.12, U3.4, U3.9, U5.13, U7.13, U8.9, U12.4, U13.4, U14.4, U14.9
B-segment: J1.2, U9.11
C: J1.10, U3.13, U4.12, U6.1, U7.10, U7.12, U10.5, U12.5, U13.5, U15.13
C': U1.9, U2.1, U2.10, U3.5, U4.10, U5.1, U6.10, U12.6, U13.10, U15.5, U16.2
C-segment: J1.3, U2.6
D: J1.11, U1.10, U2.13, U3.2, U4.13, U5.5, U8.12, U11.5, U12.9, U14.5
D': U1.13, U2.2, U3.10, U5.2, U8.10, U10.2, U11.2, U11.13, U12.8, U14.10
D-segment: J1.4, U7.3
E-segment: J1.5, U7.6
F-segment: J1.6, U13.3
G-segment: J1.7, U14.3
GND: J1.13, R1.1, U1.7 (GND), U2.7 (GND), U3.7 (GND), U4.7 (GND), U5.7 (GND), U6.7 (GND), U7.7 (GND), U8.7 (GND), U9.7 (GND), U10.7 (GND), U11.7 (GND), U12.7 (GND), U13.7 (GND), U14.7 (GND), U15.7 (GND), U16.7 (GND)
unnamed: D1.1 (K), R1.2
unnamed: U1.3, U8.1
unnamed: U1.5, U2.11
unnamed: U1.6, U8.2
unnamed: U1.8, U2.5
unnamed: U1.11, U7.1
unnamed: U2.3, U5.12
unnamed: U2.4, U8.3
unnamed: U2.8, U2.12
unnamed: U3.11, U9.2
unnamed: U4.8, U5.4
unnamed: U4.11, U9.9
unnamed: U5.3, U9.10
unnamed: U5.6, U9.4
unnamed: U5.8, U9.5
unnamed: U5.10, U9.8
unnamed: U5.11, U9.13
unnamed: U6.2, U8.8
unnamed: U6.3, U8.5
unnamed: U6.4, U6.8
unnamed: U6.5, U8.11
unnamed: U6.6, U8.4
unnamed: U6.11, U7.4
unnamed: U6.13, U7.8
unnamed: U7.2, U8.6
unnamed: U9.6, U9.12
unnamed: U3.6, U10.1
unnamed: U4.5, U10.3
unnamed: U3.3, U10.4
unnamed: U4.2, U10.6
unnamed: U4.3, U10.9
unnamed: U4.6, U10.10
unnamed: U9.1, U10.11
unnamed: U10.8, U10.12
unnamed: U3.8, U10.13
unnamed: U7.11, U11.1
unnamed: U7.5, U11.3
unnamed: U11.6, U15.1
unnamed: U11.8, U15.4
unnamed: U11.11, U13.2
unnamed: U11.12, U13.8
unnamed: U13.1, U13.11
unnamed: U13.6, U15.2
unnamed: U13.12, U15.3
unnamed: U13.13, U15.6
unnamed: U14.1, U14.11
unnamed: U14.2, U16.3
unnamed: U14.6, U15.10
unnamed: U14.8, U15.12
unnamed: U14.12, U15.8
unnamed: U14.13, U15.11
unnamed: U16.1, U16.6

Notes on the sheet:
D-segment combinational logic
G-segment combinational logic
A-segment combinational logic
F-segment combinational logic
B-segment combinational logic
C-segment combinational logic
E-segment combinational logic

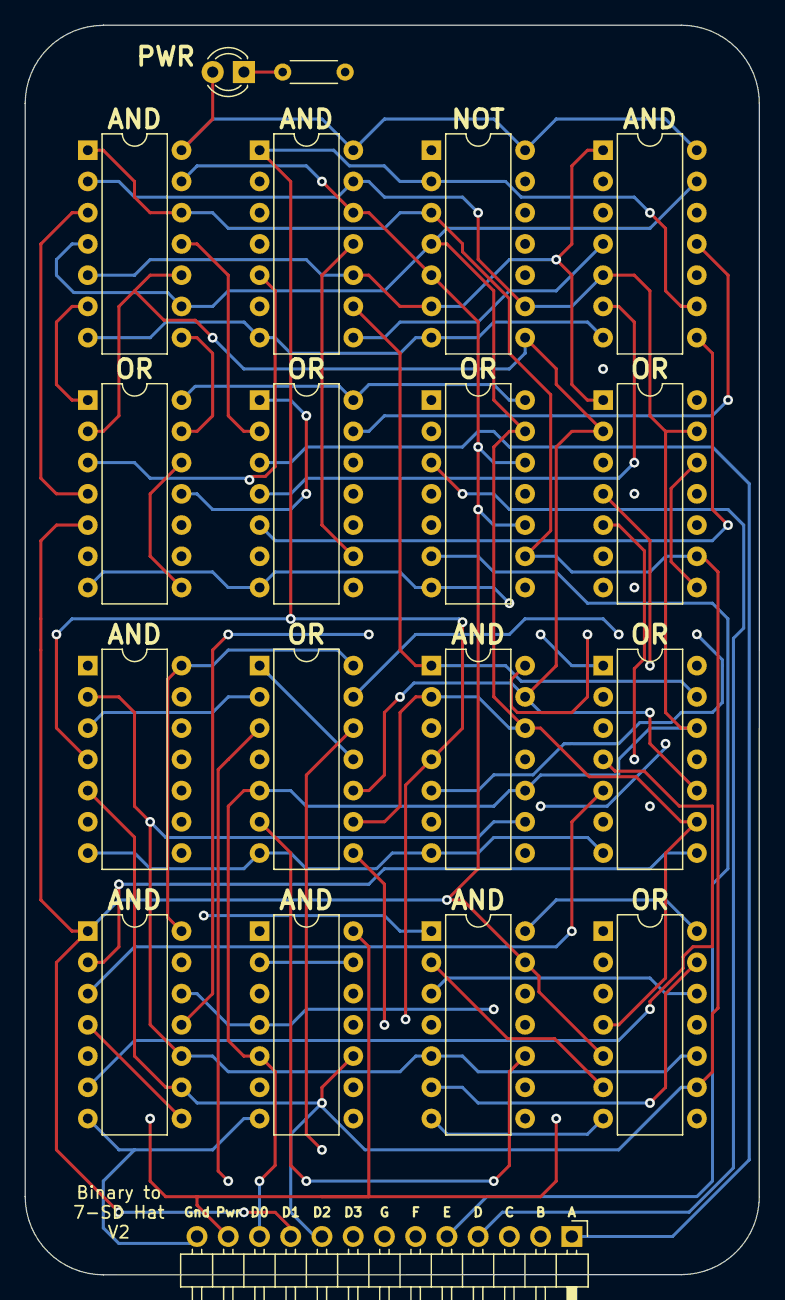
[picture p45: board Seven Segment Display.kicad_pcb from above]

Board: 4 copper layers, 59.7 x 101.6 mm, 19 parts (0 on the bottom side), 69 nets.

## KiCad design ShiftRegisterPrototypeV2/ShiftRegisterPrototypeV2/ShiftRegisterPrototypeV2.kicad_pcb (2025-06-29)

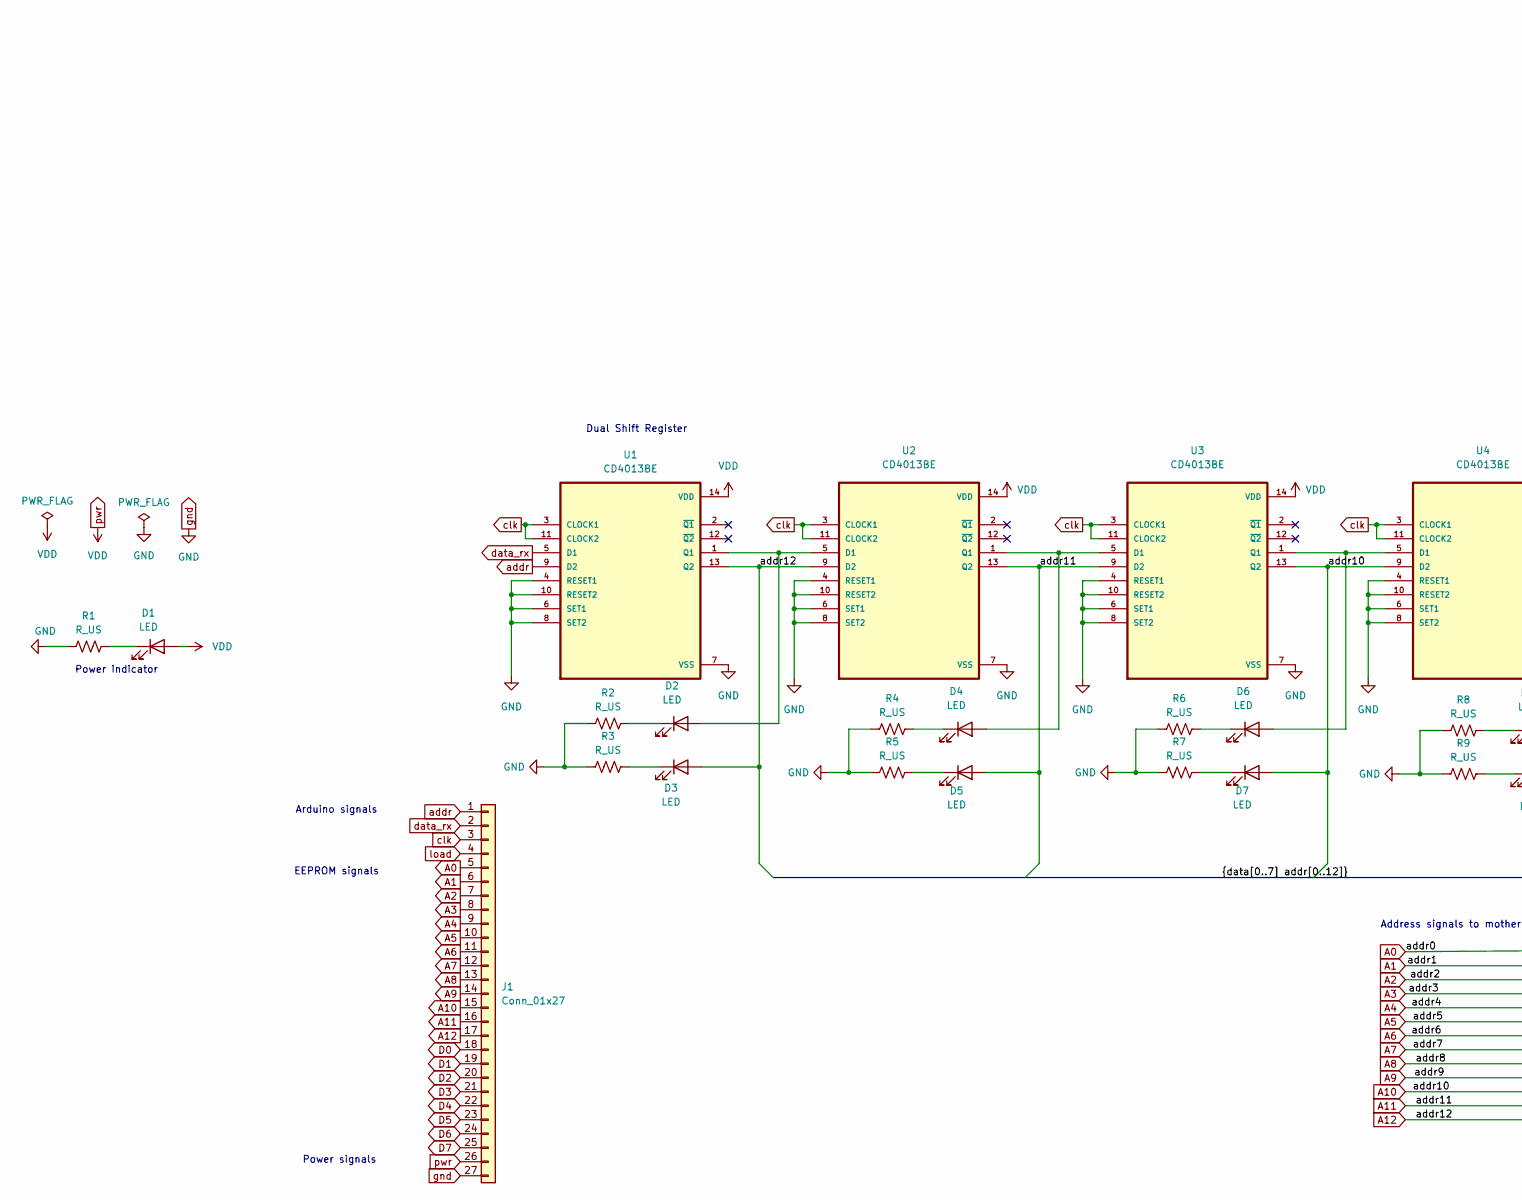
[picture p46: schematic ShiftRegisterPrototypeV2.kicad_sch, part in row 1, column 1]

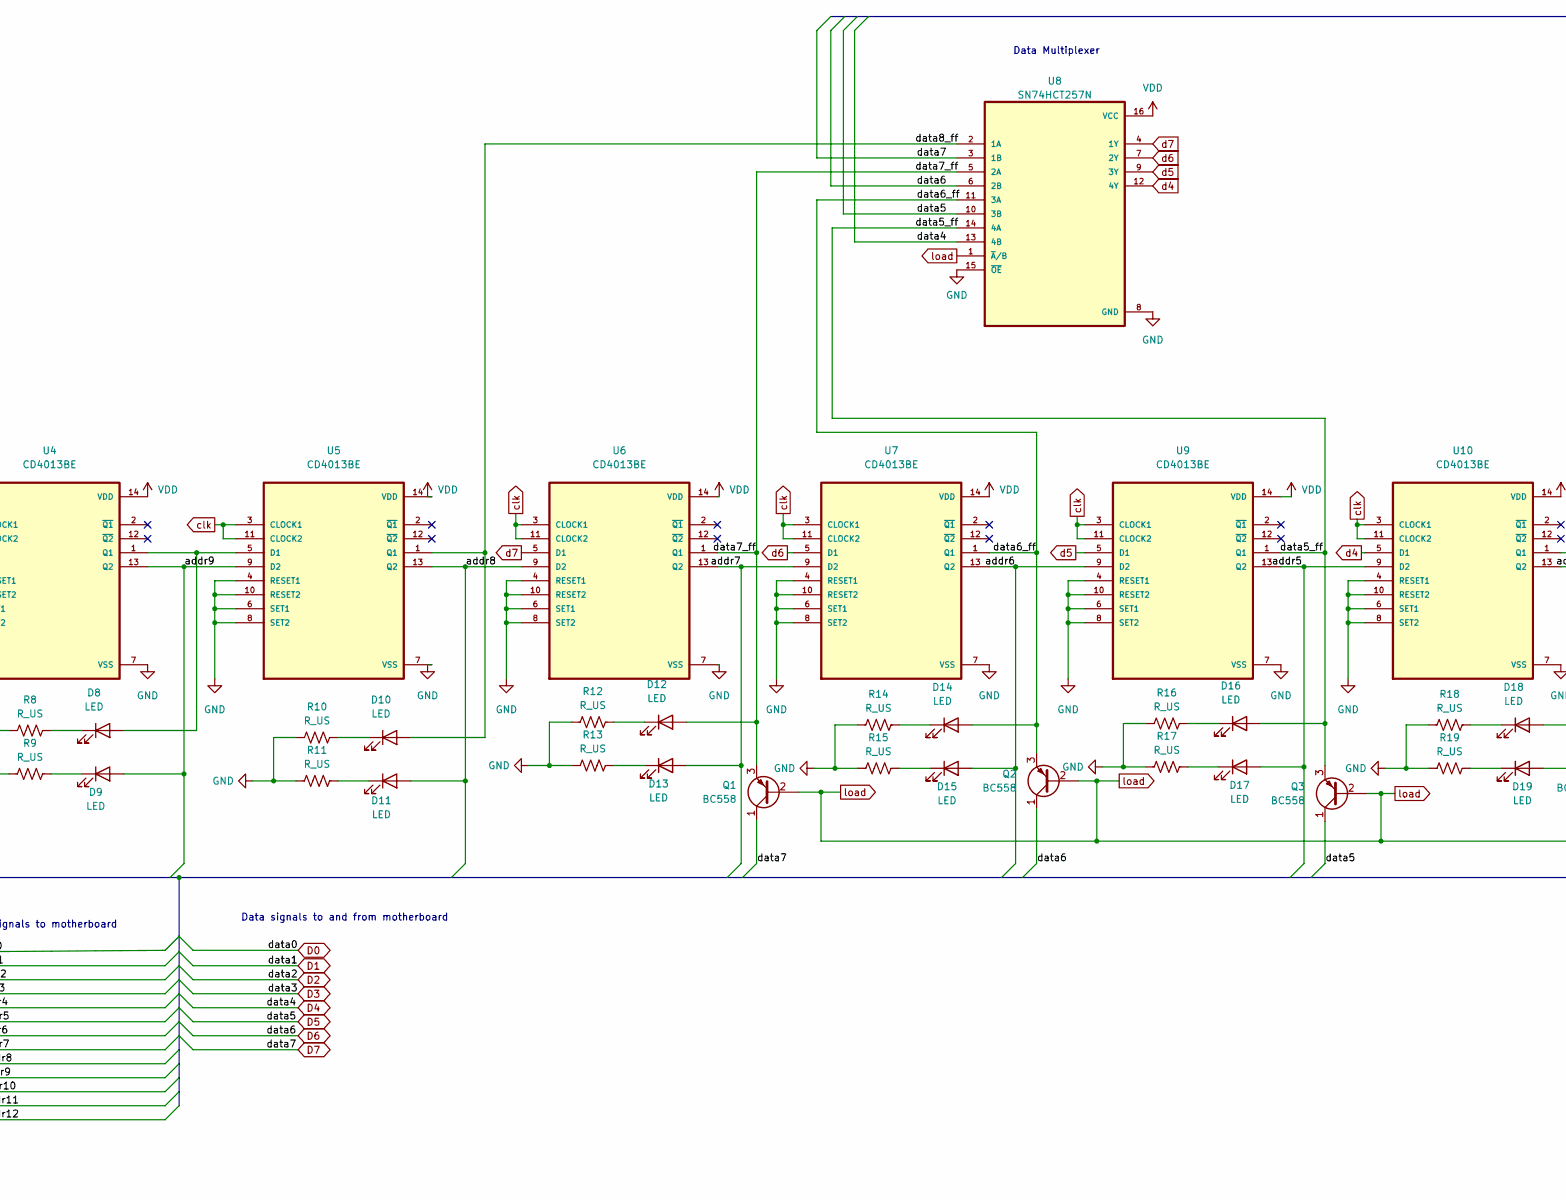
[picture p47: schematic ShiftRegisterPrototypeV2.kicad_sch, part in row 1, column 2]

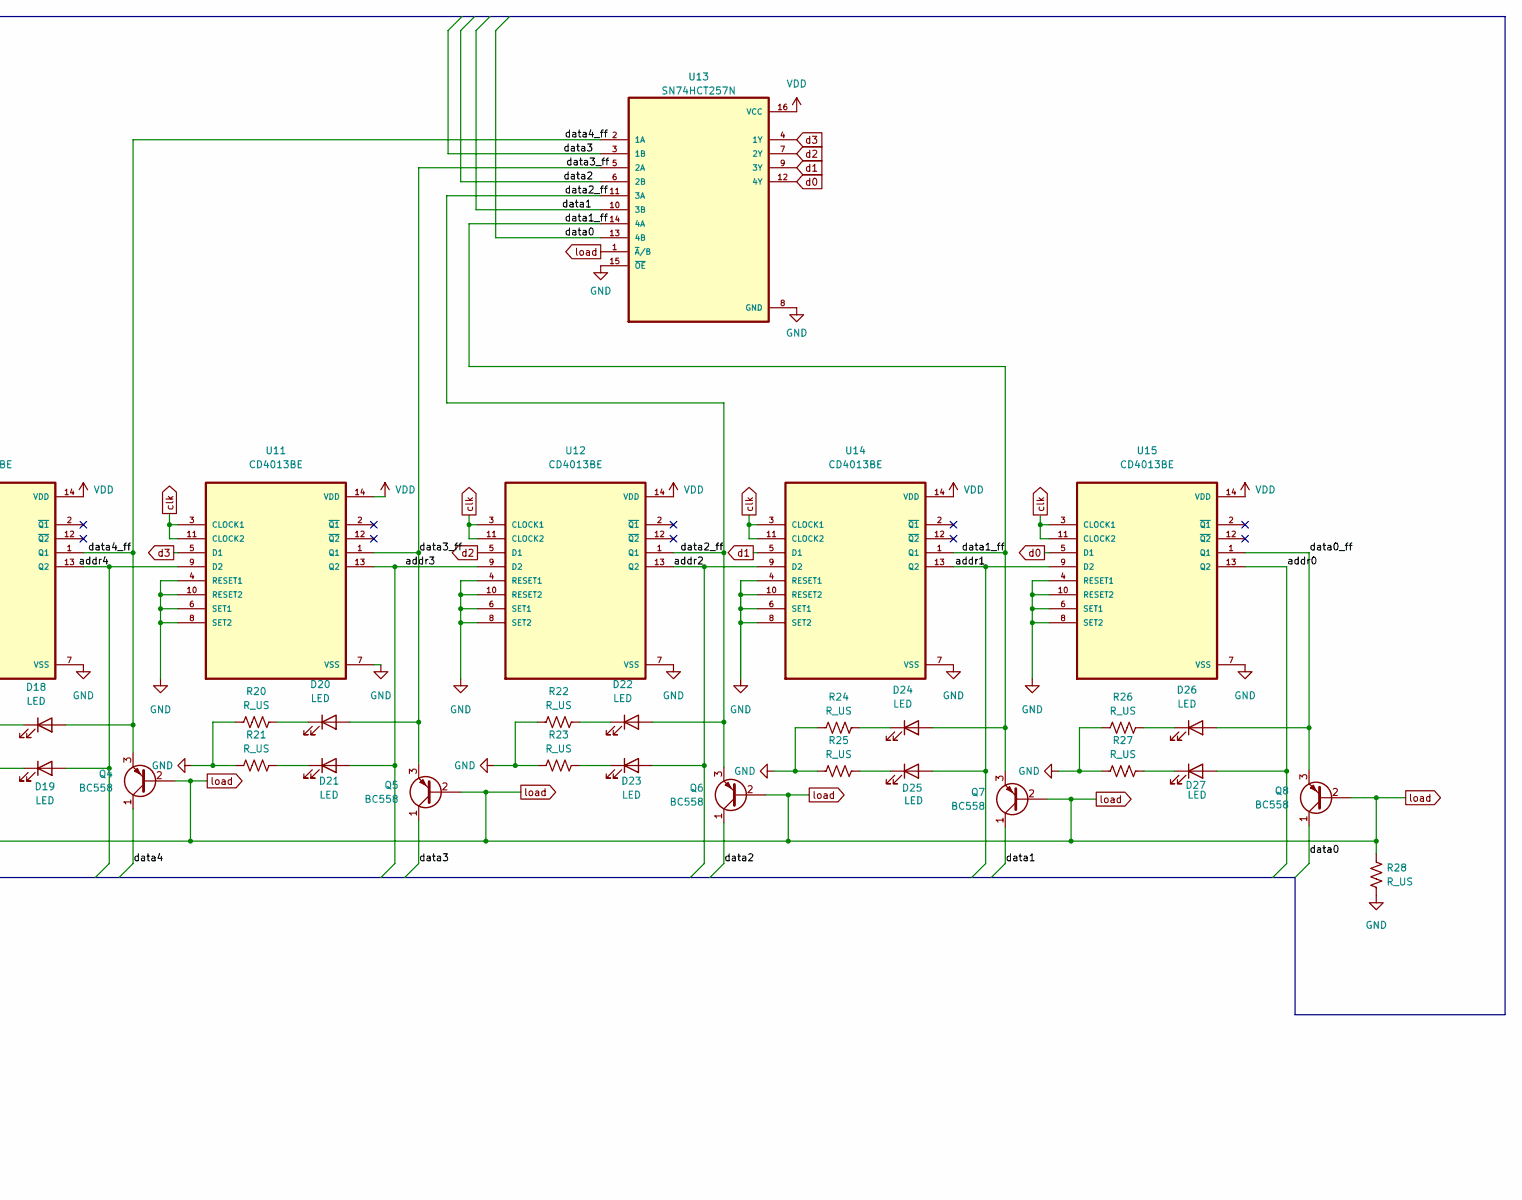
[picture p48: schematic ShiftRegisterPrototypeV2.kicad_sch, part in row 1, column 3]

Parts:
D1: LED; LED_D3.0mm_white
D2, D4, D6, D8, D10, D12, D14, D16, D18, D20, D22, D24, D26: LED; LED_D3.0mm_red
D3, D5, D7, D9, D11, D13, D15, D17, D19, D21, D23, D25, D27: LED; LED_D3.0mm_green
J1: Conn_01x27; PinHeader_1x27_P2.54mm_Horizontal
Q1, Q2, Q3, Q4, Q5, Q6, Q7, Q8: BC558; TO-92_Inline
R1, R2, R3, R4, R5, R6, R7, R8, R9, R10, R11, R12, R13, R14, R15, R16, R17, R18, R19, R20, R21, R22, R23, R24, R25, R26, R27, R28: R_US; R_Axial_DIN0204_L3.6mm_D1.6mm_P5.08mm_Horizontal
U1, U2, U3, U4, U5, U6, U7, U9, U10, U11, U12, U14, U15: CD4013BE; DIP794W45P254L1969H508Q14
U8, U13: SN74HCT257N; DIP794W45P254L1969H508Q16

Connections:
/data0_ff: D26.2 (A), Q8.3 (E), U15.1 (Q1)
/data1_ff: D24.2 (A), Q7.3 (E), U13.14 (4A), U14.1 (Q1)
/data2_ff: D22.2 (A), Q6.3 (E), U12.1 (Q1), U13.11 (3A)
/data3_ff: D20.2 (A), Q5.3 (E), U11.1 (Q1), U13.5 (2A)
/data4_ff: D18.2 (A), Q4.3 (E), U10.1 (Q1), U13.2 (1A)
/data5_ff: D16.2 (A), Q3.3 (E), U8.14 (4A), U9.1 (Q1)
/data6_ff: D14.2 (A), Q2.3 (E), U7.1 (Q1), U8.11 (3A)
/data7_ff: D12.2 (A), Q1.3 (E), U6.1 (Q1), U8.5 (2A)
/data8_ff: D10.2 (A), U5.1 (Q1), U8.2 (1A)
A0: D27.2 (A), J1.5, U15.13 (Q2)
A1: D25.2 (A), J1.6, U14.13 (Q2), U15.9 (D2)
A2: D23.2 (A), J1.7, U12.13 (Q2), U14.9 (D2)
A3: D21.2 (A), J1.8, U11.13 (Q2), U12.9 (D2)
A4: D19.2 (A), J1.9, U10.13 (Q2), U11.9 (D2)
A5: D17.2 (A), J1.10, U9.13 (Q2), U10.9 (D2)
A6: D15.2 (A), J1.11, U7.13 (Q2), U9.9 (D2)
A7: D13.2 (A), J1.12, U6.13 (Q2), U7.9 (D2)
A8: D11.2 (A), J1.13, U5.13 (Q2), U6.9 (D2)
A9: D9.2 (A), J1.14, U4.13 (Q2), U5.9 (D2)
A10: D7.2 (A), J1.15, U3.13 (Q2), U4.9 (D2)
A11: D5.2 (A), J1.16, U2.13 (Q2), U3.9 (D2)
A12: D3.2 (A), J1.17, U1.13 (Q2), U2.9 (D2)
D0: J1.18, Q8.1 (C), U13.13 (4B)
D1: J1.19, Q7.1 (C), U13.10 (3B)
D2: J1.20, Q6.1 (C), U13.6 (2B)
D3: J1.21, Q5.1 (C), U13.3 (1B)
D4: J1.22, Q4.1 (C), U8.13 (4B)
D5: J1.23, Q3.1 (C), U8.10 (3B)
D6: J1.24, Q2.1 (C), U8.6 (2B)
D7: J1.25, Q1.1 (C), U8.3 (1B)
unnamed: D1.1 (K), R1.2
unnamed: D2.1 (K), R2.2
unnamed: D2.2 (A), U1.1 (Q1), U2.5 (D1)
unnamed: D3.1 (K), R3.2
unnamed: D4.1 (K), R4.2
unnamed: D4.2 (A), U2.1 (Q1), U3.5 (D1)
unnamed: D5.1 (K), R5.2
unnamed: D6.1 (K), R6.2
unnamed: D6.2 (A), U3.1 (Q1), U4.5 (D1)
unnamed: D7.1 (K), R7.2
unnamed: D8.1 (K), R8.2
unnamed: D8.2 (A), U4.1 (Q1), U5.5 (D1)
unnamed: D9.1 (K), R9.2
unnamed: D10.1 (K), R10.2
unnamed: D11.1 (K), R11.2
unnamed: D12.1 (K), R12.2
unnamed: D13.1 (K), R13.2
unnamed: D14.1 (K), R14.2
unnamed: D15.1 (K), R15.2
unnamed: D16.1 (K), R16.2
unnamed: D17.1 (K), R17.2
unnamed: D18.1 (K), R18.2
unnamed: D19.1 (K), R19.2
unnamed: D20.1 (K), R20.2
unnamed: D21.1 (K), R21.2
unnamed: D22.1 (K), R22.2
unnamed: D23.1 (K), R23.2
unnamed: D24.1 (K), R24.2
unnamed: D25.1 (K), R25.2
unnamed: D26.1 (K), R26.2
unnamed: D27.1 (K), R27.2
addr: J1.1, U1.9 (D2)
clk: J1.3, U1.3 (CLOCK1), U1.11 (CLOCK2), U2.3 (CLOCK1), U2.11 (CLOCK2), U3.3 (CLOCK1), U3.11 (CLOCK2), U4.3 (CLOCK1), U4.11 (CLOCK2), U5.3 (CLOCK1), U5.11 (CLOCK2), U6.3 (CLOCK1), U6.11 (CLOCK2), U7.3 (CLOCK1), U7.11 (CLOCK2), U9.3 (CLOCK1), U9.11 (CLOCK2), U10.3 (CLOCK1), U10.11 (CLOCK2), U11.3 (CLOCK1), U11.11 (CLOCK2), U12.3 (CLOCK1), U12.11 (CLOCK2), U14.3 (CLOCK1), U14.11 (CLOCK2), U15.3 (CLOCK1), U15.11 (CLOCK2)
d0: U13.12 (4Y), U15.5 (D1)
d1: U13.9 (3Y), U14.5 (D1)
d2: U12.5 (D1), U13.7 (2Y)
d3: U11.5 (D1), U13.4 (1Y)
d4: U8.12 (4Y), U10.5 (D1)
d5: U8.9 (3Y), U9.5 (D1)
d6: U7.5 (D1), U8.7 (2Y)
d7: U6.5 (D1), U8.4 (1Y)
data_rx: J1.2, U1.5 (D1)
gnd: J1.27, R1.1, R2.1, R3.1, R4.1, R5.1, R6.1, R7.1, R8.1, R9.1, R10.1, R11.1, R12.1, R13.1, R14.1, R15.1, R16.1, R17.1, R18.1, R19.1, R20.1, R21.1, R22.1, R23.1, R24.1, R25.1, R26.1, R27.1, R28.2, U1.4 (RESET1), U1.6 (SET1), U1.7 (VSS), U1.8 (SET2), U1.10 (RESET2), U2.4 (RESET1), U2.6 (SET1), U2.7 (VSS), U2.8 (SET2), U2.10 (RESET2), U3.4 (RESET1), U3.6 (SET1), U3.7 (VSS), U3.8 (SET2), U3.10 (RESET2), U4.4 (RESET1), U4.6 (SET1), U4.7 (VSS), U4.8 (SET2), U4.10 (RESET2), U5.4 (RESET1), U5.6 (SET1), U5.7 (VSS), U5.8 (SET2), U5.10 (RESET2), U6.4 (RESET1), U6.6 (SET1), U6.7 (VSS), U6.8 (SET2), U6.10 (RESET2), U7.4 (RESET1), U7.6 (SET1), U7.7 (VSS), U7.8 (SET2), U7.10 (RESET2), U8.8 (GND), U8.15 (~OE), U9.4 (RESET1), U9.6 (SET1), U9.7 (VSS), U9.8 (SET2), U9.10 (RESET2), U10.4 (RESET1), U10.6 (SET1), U10.7 (VSS), U10.8 (SET2), U10.10 (RESET2), U11.4 (RESET1), U11.6 (SET1), U11.7 (VSS), U11.8 (SET2), U11.10 (RESET2), U12.4 (RESET1), U12.6 (SET1), U12.7 (VSS), U12.8 (SET2), U12.10 (RESET2), U13.8 (GND), U13.15 (~OE), U14.4 (RESET1), U14.6 (SET1), U14.7 (VSS), U14.8 (SET2), U14.10 (RESET2), U15.4 (RESET1), U15.6 (SET1), U15.7 (VSS), U15.8 (SET2), U15.10 (RESET2)
load: J1.4, Q1.2 (B), Q2.2 (B), Q3.2 (B), Q4.2 (B), Q5.2 (B), Q6.2 (B), Q7.2 (B), Q8.2 (B), R28.1, U8.1 (~A/B), U13.1 (~A/B)
pwr: D1.2 (A), J1.26, U1.14 (VDD), U2.14 (VDD), U3.14 (VDD), U4.14 (VDD), U5.14 (VDD), U6.14 (VDD), U7.14 (VDD), U8.16 (VCC), U9.14 (VDD), U10.14 (VDD), U11.14 (VDD), U12.14 (VDD), U13.16 (VCC), U14.14 (VDD), U15.14 (VDD)

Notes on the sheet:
Dual Shift Register
Data signals to and from motherboard
Data Multiplexer
Arduino signals
Address signals to motherboard
Power indicator
EEPROM signals
Power signals

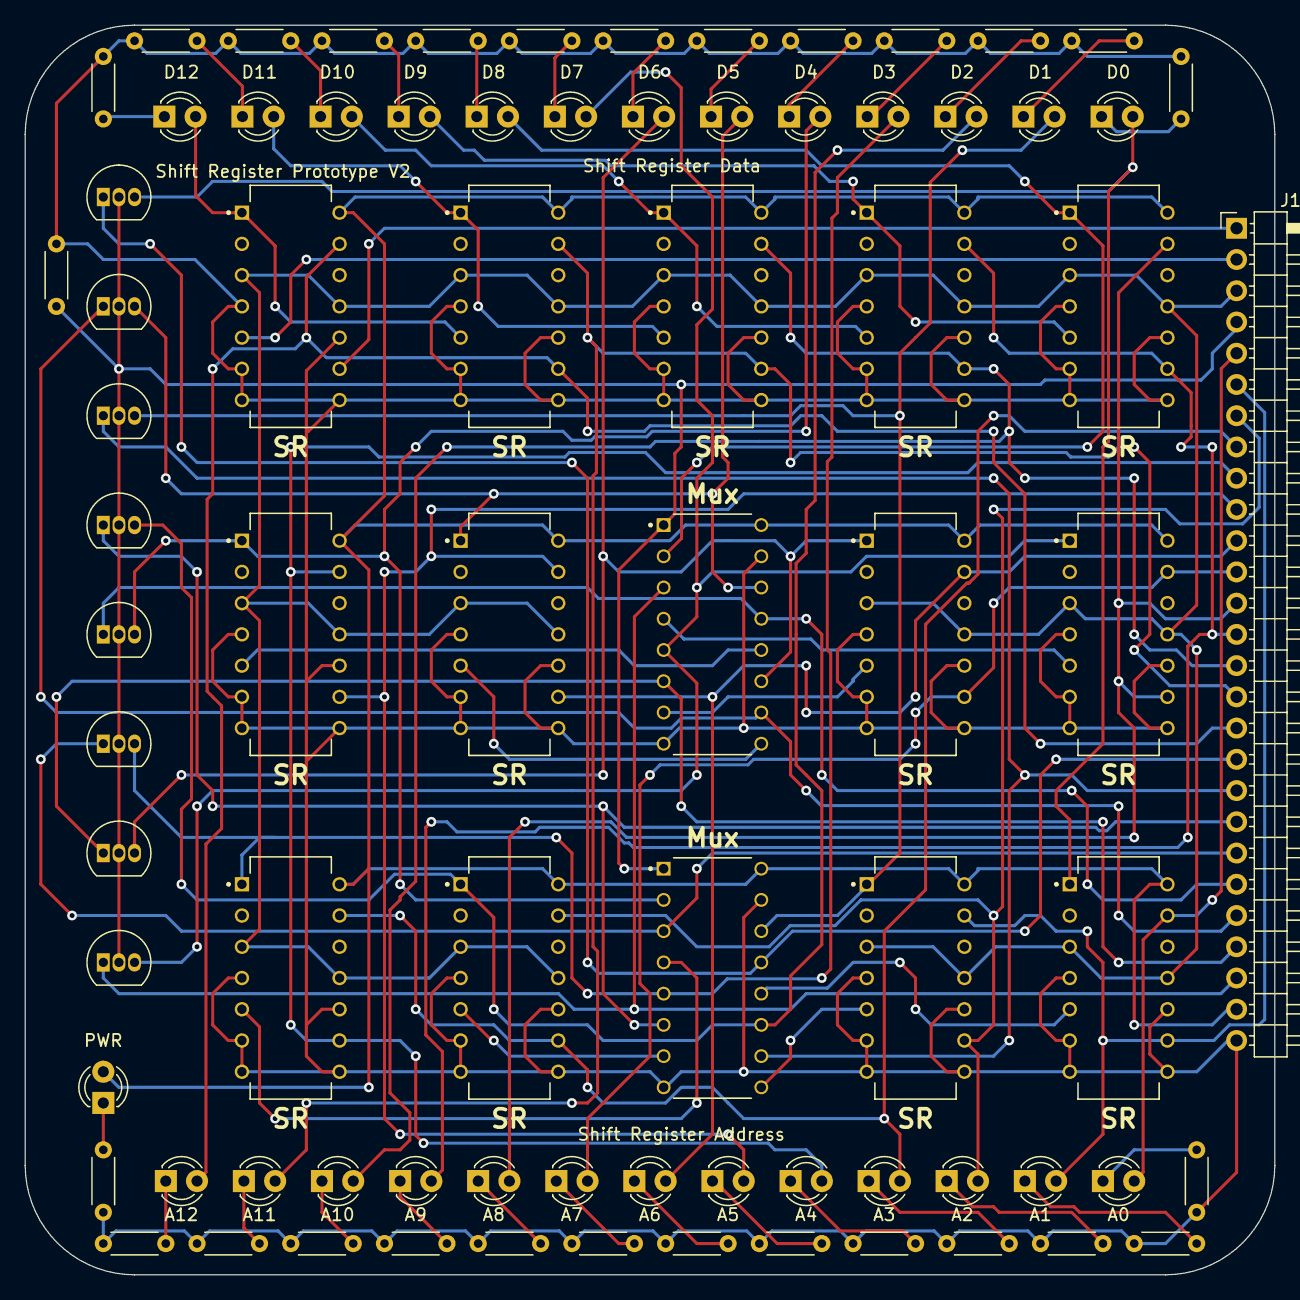
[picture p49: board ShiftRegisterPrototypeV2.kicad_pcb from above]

Board: 2 copper layers, 101.6 x 101.6 mm, 79 parts (0 on the bottom side), 75 nets.

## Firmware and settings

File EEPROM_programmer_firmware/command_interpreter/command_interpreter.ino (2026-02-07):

// Author: Dorian Knight
// Created: August 6th 2025
// Updated: August 8th 2025
// Description: Command interpreter for EEPROM Programmer firmware

#include "EEPROM_Programmer_Utility.h"

bool error_bit = 0;
const byte WRITE_COMMAND_LEN = 0x0E; // hex(0x0E) = dec(14)
const byte READ_COMMAND_LEN  = 0x04; // hex(0x04) = dec(4)
const byte SERIAL_BUFFER_MAX = 0x40; // hex(0x40) = dec(64)
const byte SHIFT_COMMAND_LEN = 0x06;
const unsigned short METADATA_LEN = 12;
const unsigned short MAX_EEPROM_SPACE = 8192;

// Binary array to pipe into shift register
bool data_package[64][8];
bool address_bit_stream[13];

// Byte array to store information from computer
byte command_info[WRITE_COMMAND_LEN];
byte file_data[SERIAL_BUFFER_MAX];
byte stop_byte_collector[1];

EEPROM_Utility Memory_Manager(9600);

void setup() {
  // put your setup code here, to run once:
  Serial.begin(Memory_Manager.get_baud_rate());
  Memory_Manager.begin();
  pinMode(LED_BUILTIN, OUTPUT); // Error LED
}

void write_manager() {
  /** Function description
    * Parses file metadata and handles bulk file data transfer from the computer into the EEPROM
    * The metadata contains the start address of the file, end address of the file and the name of the file (max 8 characters)
    * After writing the meta data into the "file allocation table" section of the EEPROM, the write_manager will signal the computer to send over the bulk data 64 bytes at a time
    * The after reading in the bulk data, the write_manager will transfer that data into the EEPROM in accordance to the file's metadata
    */

  /************ Metadata processing ************/

  // Read in full write command
  Serial.readBytes(command_info, WRITE_COMMAND_LEN);
  Serial.readBytes(stop_byte_collector,1); // Clear 0x0a from serial buffer

  // Package address and data into appropriate binary streams
  Memory_Manager.construct_address_bitstream(command_info, address_bit_stream);  // First two bytes of command_info is the metadata start address
  Memory_Manager.data_packager(command_info + 2, (bool *)data_package, METADATA_LEN);  // The remaining 12 bytes of data from command_info is the metadata to be written

  // Write metadata to EEPROM
  for(int i=0; i<METADATA_LEN; i++) {
    if (Memory_Manager.write(data_package[i], address_bit_stream) == 0) {
      error_funct();
    }
    Memory_Manager.increment_address(address_bit_stream);
  }

  /************ File data processing ************/
  // Assemble metadata
  unsigned short file_start;
  unsigned short file_end;

  memcpy(&file_start, command_info+2, 2);
  memcpy(&file_end, command_info+4, 2);
  unsigned short file_len = file_end - file_start + 1; // +1 because the end is inclusive

  // Keeps track of how much data has been written
  unsigned short bytes_written = 0;
  unsigned short bytes_remaining = file_len;
  unsigned short bytes_to_write = 0;

  // Create starting address bit stream
  Memory_Manager.construct_address_bitstream((byte *)&file_start, address_bit_stream);

  // Signal computer to commence data transfer
  Serial.write(0x7e);

  // Read in data from serial buffer and write to EEPROM in 64 byte chunks
  while (bytes_written < file_len) {
    // Send acknowledge bit back to computer

    // Wait for buffer to fill with data
    while (Serial.available() < SERIAL_BUFFER_MAX && Serial.available() < bytes_remaining);

    if (bytes_remaining < SERIAL_BUFFER_MAX) {
      bytes_to_write = bytes_remaining;
    }

    else {
      bytes_to_write = SERIAL_BUFFER_MAX;
    }

    Serial.readBytes(file_data, bytes_to_write);
    Serial.readBytes(stop_byte_collector, 1); // Collect 0x0a stop byte at the end
    Serial.write(0x7e); // Send acknowledge bit back to computer such that it can fill the buffer while the Arduino writes data into the EEPROM

    // Package and write data in buffer into EEPROM
    Memory_Manager.data_packager(file_data, (bool *)data_package, bytes_to_write);
    for (int i=0; i<bytes_to_write; i++) {
      if (Memory_Manager.write(data_package[i], address_bit_stream) == 0) {
        error_funct();
      }
      Memory_Manager.increment_address(address_bit_stream);
    }

    bytes_written += bytes_to_write;
    bytes_remaining -= bytes_to_write;
  }
}


void read_manager() {
  /** Function description
    * The read manager is called when a read command is presented to the Arduino firmware
    * This read command contains two important data points: Address start, address end, each of which are two bytes
    * The read manager should read from start to finish, and send the data over Serial in chunks of 64 bytes at a time
    */

  Serial.readBytes(command_info, READ_COMMAND_LEN +1); // +1 to remove the 0x0a from the serial buffer

  unsigned short file_start;
  unsigned short file_end;
  unsigned short file_len;
  unsigned short bytes_remaining;
  byte bytes_to_read;

  memcpy(&file_start, command_info, 2);
  memcpy(&file_end, command_info+2, 2);

  file_len = file_end - file_start + 1;  // +1 because the file end is inclusive
  bytes_remaining = file_len;

  // Test
  Serial.println(file_start);
  Serial.println(file_end);

  Memory_Manager.construct_address_bitstream((byte *)&file_start, address_bit_stream);

  while(bytes_remaining > 0) {

    if (bytes_remaining < SERIAL_BUFFER_MAX) {
      bytes_to_read = bytes_remaining;
    }

    else {
      bytes_to_read = SERIAL_BUFFER_MAX;
    }

    // Read the required amount of bytes

    for (int i=0; i<bytes_to_read; i++) {
      Memory_Manager.read(data_package[i], address_bit_stream);  // Read individual bits from EEPROM shift register
      file_data[i] = Memory_Manager.compress_bit_stream(data_package[i]);  // Convert bit stream into a singular byte of data and store in buffer;
      Memory_Manager.increment_address(address_bit_stream);  // Move to next address

      // Test
      Serial.println(file_data[i]);
    }

    // Write bytes in memory to computer over serial
    Serial.write(file_data, bytes_to_read);

    bytes_remaining -= bytes_to_read;
  }
}


void data_shift_command() {
  /** Function description
    * The data shift command is composed of three arguments, start, stop, and the number to shift by (signed)
    * because the number to shift by is a signed number we can shift forwards or backwards
    */


  // Read in command
  Serial.readBytes(command_info, SHIFT_COMMAND_LEN);
  Serial.readBytes(stop_byte_collector, 1); // Read the stop byte (0x0a) to remove it from the serial buffer

  unsigned short shift_start;
  unsigned short shift_end;
  unsigned short current_address;
  signed short shift_amplitude;
  signed short shift_destination;

  memcpy(&shift_start,     command_info,   2);
  memcpy(&shift_end,       command_info+2, 2);
  memcpy(&shift_amplitude, command_info+4, 2);

  shift_destination = (signed short)current_address + shift_amplitude;

  bool destination_address[8];
  if (shift_amplitude > 0) {
    // Shift data from lower address to higher address
    // Start from higher addresses and work down to the lower addresses
    current_address = shift_end;

    // Construct address bit streams
    Memory_Manager.construct_address_bitstream((byte *)&shift_end, address_bit_stream);
    Memory_Manager.construct_address_bitstream((byte *)&shift_destination, destination_address);
    for (current_address; current_address >= shift_start; current_address--) {
      // Read in data at current address
      Memory_Manager.read(data_package[0], address_bit_stream);

      // Write data to destination address
      Memory_Manager.write(data_package[0], destination_address);

      // Decrement address and repeat process
      Memory_Manager.decrement_address(address_bit_stream);
      Memory_Manager.decrement_address(destination_address);
    }
  }

  else {
    // Shift data from higher address to lower address
    // Start with lower addresses and work up to the higher addresses
    current_address = shift_start;

    // Construct address bit streams
    Memory_Manager.construct_address_bitstream((byte *)&shift_start, address_bit_stream);
    Memory_Manager.construct_address_bitstream((byte *)&shift_destination, destination_address);
    for (current_address; current_address <= shift_end; current_address++) {
      // Read in data at current address
      Memory_Manager.read(data_package[0], address_bit_stream);

      // Write data to destination address
      Memory_Manager.write(data_package[0], destination_address);

      // Increment address and repeat process
      Memory_Manager.increment_address(address_bit_stream);
      Memory_Manager.increment_address(destination_address);
    }
  }
}

void eeprom_format_command() {
  /** Function description
    * Called when the entire EEPROM chip needs to be erased
    * File allocation size reset to zero
    */

  file_data[0] = 0x5E;
  byte empty_memory_data = 0xFF;
  byte start_address = 0x00;

  Memory_Manager.data_packager(file_data, (bool *)data_package, 1);
  Memory_Manager.data_packager(&empty_memory_data, (bool *)data_package+1, 1);
  Memory_Manager.construct_address_bitstream(&start_address, address_bit_stream);

  for (int i=0; i<MAX_EEPROM_SPACE; i++) {
    if (i < 2) {
      Memory_Manager.write(data_package[0], address_bit_stream);
    }

    else {
      Memory_Manager.write(data_package[1], address_bit_stream);
    }

    Memory_Manager.increment_address(address_bit_stream);
  }
}

void loop() {
  // Serial.println("In main function");
  // put your main code here, to run repeatedly:
  byte command;
  if (Serial.available() > 0) {
    // Interpret command, parse data and call utility function
    command = Serial.read();
    Serial.println(command);
    switch (command) {
      case 64:  // Write command
        write_manager();
        break;
      case 65:  // Read command
        read_manager();
        break;
      case 2:  // Shift data command
        data_shift_command();
        break;
      case 3:  // Format EEPROM command
        eeprom_format_command();
        break;
      default:
        error_funct();
        break;
    }
  }
}

void error_funct() {
  // Break out of infinite loop
  Serial.println("Unexpected error has occured");
  while(true) // Infinite loop to trap program execution @TODO: find a better solution
  {
    digitalWrite(LED_BUILTIN, HIGH);  // Signal Error has occured
    delay(100);
    digitalWrite(LED_BUILTIN, LOW);
    delay(100);
  }
}

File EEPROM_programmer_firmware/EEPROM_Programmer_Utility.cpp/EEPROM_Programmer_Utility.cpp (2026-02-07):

/*
  EEPROM_Programmer_Utility.cpp is a library for managing communication between
  the programmer software application and the EEPROM mounted to my custom hardware

  // Author: Dorian Knight
  // Created: August 11th 2025
  // Updated: August 18th 2025

  Contains utility function implementations to translate data and manage PCB hardware signals
*/

#include "Arduino.h"
#include "EEPROM_Programmer_Utility.h"

EEPROM_Utility::EEPROM_Utility(int baud_rate){
  _baud_rate = baud_rate;
}

void EEPROM_Utility::begin()
{
  // Called during setup

  // Define MCU port pins
  pinMode(OE,     OUTPUT); // Output Enable
  pinMode(WE,     OUTPUT); // Write Enable
  pinMode(CE,     OUTPUT); // Chip Enable
  pinMode(AddRx,  OUTPUT); // Address received from PC
  pinMode(DataRx, OUTPUT); // Data received from PC
  pinMode(DataTx, INPUT);  // Data received from EEPROM
  pinMode(Clk,    OUTPUT); // Clock signal
  pinMode(Load,   OUTPUT); // Load signal

  // Pull the control signal lines high as the control signals are active low
  digitalWrite(CE, HIGH);
  digitalWrite(OE, HIGH);
  digitalWrite(WE, HIGH);
}

void EEPROM_Utility::data_packager(byte *bytewise_data, bool *data_container, unsigned short stream_length) {
  /** Function description:
    * Take data bytes as input and construct an array of 8 elements where each element represents a bit of the input data byte
    * The end result is a two dimensional array where the [i] is the binary array for each input byte and the [j] is a singular bit within the desired byte
    * data_container[8][4] would get me the 5th bit in the 9th byte provided to me as input
    * Note: The data is stored in little endian format
    */
  byte mask;
  byte result;
  for (int i=0; i<stream_length; i++) {
    // Take byte from input data and convert into a binary stream
    mask = 0b00000001;
    for (int j=0; j<8; j++) {
      // Use mask to construct bit stream
      result = bytewise_data[i] & mask;
      if (result > 0) {
        *(data_container + i*8 + j) = 1;
      }

      else {
        *(data_container + i*8 + j) = 0;
      }

      mask <<= 1;
    }
  }
}

void EEPROM_Utility::construct_address_bitstream(byte *raw_bytes, bool *bit_stream) {
  /** Function description
    * Use bitmasking to construct binary array
    * Binary array is little endian
    */

  unsigned short raw_data;
  unsigned short result;
  unsigned short mask = 0b00000001;

  memcpy(&raw_data, raw_bytes, 2); // Converts binary array into unsigned short making the data easier to manipulate

  for (int i=0; i<13; i++) {
    result = raw_data & mask;

    if (result > 0) {
      // ith bit is 1
      bit_stream[i] = 1;
    }
    else {
      // ith bit is a zero
      bit_stream[i] = 0;
    }

    mask <<= 1; // Left shift the mask
  }
}

void EEPROM_Utility::increment_address (bool *address_bit_stream) {
  /** Function description
    * Given the boolean array representing an address in binary, the function will iterate through the array
    * and increment the binary representation by 1 such that the end result array will represent a binary number
    * one higher than the original
    */

  int carry = 0;
  for (int i=0; i<13; i++) {
    if (address_bit_stream[i] == 0 && carry == 0) {
      // Increment and break out of loop
      address_bit_stream[i] = 1;
      break;
    }

    else if (address_bit_stream[i] == 1 && carry == 0) {
      // Reset and set carry
      address_bit_stream[i] = 0;
      carry = 1;
    }

    else if (address_bit_stream[i] == 0 && carry == 1) {
      // Increment and break out of loop
      address_bit_stream[i] = 1;
      break;
    }

    else {
      // Address is 1 and carry is 1
      // Reset and set carry
      address_bit_stream[i] = 0;
      carry = 1;
    }
  }
}

void EEPROM_Utility::decrement_address (bool *address_bit_stream) {
  /** Function description
    * Given the boolean array representing an address in binary, the function will iterate through the array
    * and decrement the binary representation by 1 such that the end result array will represent a binary number
    * one lower than the original
    */

  // Find the least significant 1
  int i=0;
  for (i; i<13; i++) {
    if (address_bit_stream[i] == 1) {
      // Found least significant 1
      // Subtract 1
      address_bit_stream[i] = 0;
      i--;
      break;
    }
  }

  for (i; i>=0; i--) {
    // To properly subtract, all bits behind that 1 must be flipped
    address_bit_stream[i] ^= 1;
  }
}

bool EEPROM_Utility::write(bool *data, bool *address) {
  // Given the address and data binary arrays, output serially into the shift register
  // After loading into the shift register, send EEPROM the write signal
  bool success;
  byte iteration_count = 0;

  do
  {
    for (int i=0; i<13; i++) {
      // For the first eight iterations, program address and data
      // After the eigth iteration, only program in the address

      // Set the address and data lines
      if (i<8) {
        // Program the data line
        digitalWrite(DataRx, data[i]);
      }
      digitalWrite(AddRx, address[i]);

      // Clock the data in
      pulse();
    }

    // Send write commands to EEPROM
    EEPROMWrite();

    // Verify transcription
    success = verify(data, address);
    iteration_count++;
  } while (success == 0 && iteration_count < 3);

  return success;
}

void EEPROM_Utility::read(bool *data, bool *address) {
  // Given the address in binary, the read function will use the shift register to read the byte written at the specified address,
  // Fill the given data pointer with bits stored at the specified address

  // Input the address into the shift register
  for (int i=0; i<13; i++) {
    digitalWrite(AddRx, address[i]);
    pulse();
  }

  // Load the EEPROM data from the specified address into the shift register
  EEPROMLoad();

  // Shift the data out and read one bit at a time
  for (int i=0; i<8; i++) {
    data[i] = (bool)digitalRead(DataTx);
    pulse(); // Advance the shift register
  }
}

byte EEPROM_Utility::compress_bit_stream(bool* data_bit_stream) {
  /** Function description
   *  Converts the 8 bit stream of data into an decimal integer between 0 and 255
   */
  int data_byte = 0;
  int power_multiplier = 1;
  for (int i=0; i<8; i++) {
    data_byte += (int)data_bit_stream[i]*power_multiplier;
    power_multiplier <<= 1;
  }
  return (byte)data_byte;
}

// ############### Private functions ############### //
void EEPROM_Utility::pulse() {
  // Governs the clock pulse logic to control the shift register
  digitalWrite(Clk, HIGH);
  delay(clk_period);
  digitalWrite(Clk, LOW);
}
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

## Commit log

2025-06-29 Add EEPROM V2 PCB design
    [Assembled_view.kicad_pcb, Assembled_view.kicad_sch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]
2025-06-29 Add current draft of documentation
2026-02-07 Create High level user flow.png
2026-02-07 Update High level user flow.png
2026-02-07 Update high level user flow diagram
2026-02-07 Add Arduino driver code
